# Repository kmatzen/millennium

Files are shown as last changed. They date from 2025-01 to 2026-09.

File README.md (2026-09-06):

# Millennium Project

The **Millennium Project** breathes new life into the Nortel Millennium public telephone by replacing much of its original electronics with modern hardware and software. The project integrates a Raspberry Pi Zero 2 W, two Arduinos, and a VoIP software stack while retaining all the original hardware, including the display, keypad, coin acceptor, magstripe reader, handset, and ringer speaker.

## Table of Contents

1. [Overview](#overview)
2. [Architecture](#architecture)
3. [Features](#features)
4. [Directory Structure](#directory-structure)
5. [Setup](#setup)
6. [Configuration](#configuration)
7. [Development](#development)
8. [Resources](#resources)
9. [License](#license)

---

## Overview

This project reimagines the functionality of the Nortel Millennium telephone by combining modern hardware and software while preserving its iconic hardware features:
- **Raspberry Pi Zero 2 W**: Manages the system, runs the VoIP stack, and interfaces with the original hardware.
- **Arduinos**: Control the keypad, display, and other peripherals.
- **Custom PCB**: Consolidates the connections between components.
- **Host Software**: Includes a daemon, plugin system, web dashboard, and ALSA audio configuration.
- **Preserved Hardware**: The original display, keypad, coin acceptor, magstripe reader, handset, and ringer speaker are retained and functional.

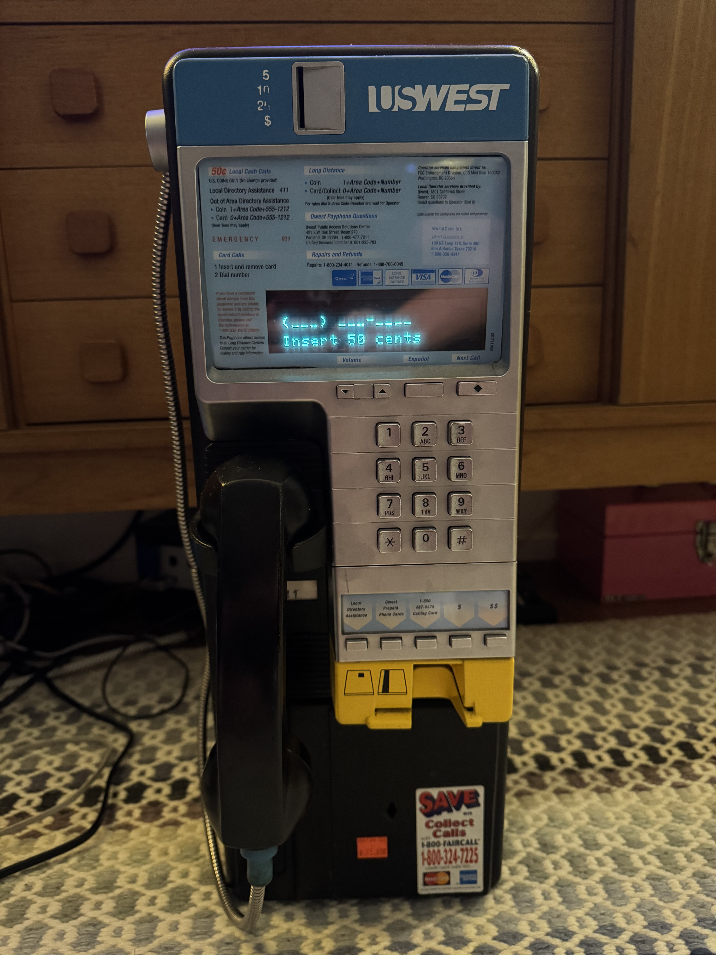
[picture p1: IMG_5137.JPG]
photo of modified phone


---

## Architecture

```
┌────────────────────────── Raspberry Pi Zero 2 W ───────────────────────────┐
│                                                                            │
│  ┌──────────────┐     ┌──────────────┐      ┌──────────────────────────┐   │
│  │ Daemon       │────▶│ PJSIP (VoIP) │      │ Web Dashboard :8081      │   │
│  │              │     └──────────────┘      │                          │   │
│  │ Plugins:     │                           │ - phone state            │   │
│  │ - Phone      │     ┌──────────────┐      │ - plugin switching       │   │
│  │ - Fortune    │     │ ALSA Audio   │      │ - OTA updates            │   │
│  │ - Jukebox    │     └──────────────┘      │ - health / metrics       │   │
│  │ - +4 games   │                           └──────────────────────────┘   │
│  └──────┬───────┘                                                          │
│         │ USB serial (9600 baud)                                           │
└─────────┬──────────────────────────────────────────────────────────────────┘
          │
┌─────────┴───────────────── Custom PCB (phonev6) ───────────────────────────┐
│                                                                            │
│  ┌──────────────────────┐ I2C      ┌────────────────────────┐              │
│  │ Display Arduino      │◀─────────│ Keypad Arduino         │              │
│  │ (millennium_beta)    │          │ (millennium_alpha)     │              │
│  │                      │          │                        │              │
│  │ - VFD display        │          │ - 4x7 keypad           │              │
│  │   (parallel 8-bit)   │          │ - magstripe reader     │              │
│  │ - coin validator     │          │ - hook switch          │              │
│  │   (SoftSerial)       │          └────────────────────────┘              │
│  └──────────────────────┘                                                  │
└────────────────────────────────────────────────────────────────────────────┘
```

**Data flow**: Keypad/hook/card events originate on the Keypad Arduino, are sent via I2C to the Display Arduino, which forwards them to the Raspberry Pi over USB serial. The daemon processes events through an event processor, dispatches them to the active plugin, and sends display updates back down the same path. VoIP calls are handled by PJSIP (PJSUA C API) with audio routed through ALSA (dmix + route plugins for mono channel splitting).

---

## Features

- **Pay phone operation**: Insert coins, dial numbers, make VoIP calls — authentic payphone experience
- **Plugin system**: Swap modes live — Classic Phone, Fortune Teller, Jukebox, plus games (Number Guess, Simon, Dial-A-Joke, Trivia). Write your own against the [plugin SDK](host/PLUGIN_AUTHORING.md); new plugins appear in the dashboard automatically
- **Emergency calls**: Dial 911, 311, or 0 without coins (configurable free numbers)
- **Dedicated credential-card support**: Swipe a random-token card for free calling or administration; payment cards are prohibited
- **Web dashboard**: Real-time phone state, plugin switching, health monitoring via WebSocket
- **Signed OTA updates**: Check, install, attest, and roll back immutable host and firmware releases. The unattended production design is documented in [host/docs/UNATTENDED_APPLIANCE.md](host/docs/UNATTENDED_APPLIANCE.md).
- **Audio tones**: DTMF, dial tone, busy tone, coin tone, ringback via ALSA
- **Idle timeout**: Automatically resets phone state after configurable inactivity period
- **State persistence**: Saves and restores coin balance and plugin state across restarts
- **Health monitoring**: Tracks serial connection, SIP registration, and daemon activity
- **Metrics collection**: Counters for calls, coins, keypresses, card swipes
- **Version tracking**: Build version and git hash displayed on dashboard
- **Scenario testing**: Simulator-based integration tests with simulated time
- **Full ARM appliance VM**: A Debian/QEMU lab runs the real daemon under
  systemd against a protocol-faithful virtual phone controller. See
  [tools/qemu/README.md](tools/qemu/README.md).

---

## Directory Structure

- **`Arduino/`**: Arduino sketches for the keypad and display microcontrollers, plus a Makefile for building and flashing.
- **`case/`**: 3D model files (`.blend` and `.stl`) for a custom enclosure. See [case/README.md](case/README.md) for dimensions and print settings.
- **`pcb/`**: KiCad schematic, PCB layout, BOM, and Gerber files for the custom PCB (phonev6).
- **`HARDWARE.md`**: Physical assembly reference — USB topology, cable routing, power budget, and component list.
- **`host/docs/UNATTENDED_APPLIANCE.md`**: Production design for signed full-device OTA and outbound remote maintenance.
- **`host/`**: Raspberry Pi software:
  - `daemon.c` — Main daemon loop and event routing
  - `plugins/` — Plugin implementations (classic_phone, fortune_teller, jukebox, number_guess, simon, dial_a_joke, trivia)
  - `plugin_sdk.c` — Plugin authoring facade (see [PLUGIN_AUTHORING.md](host/PLUGIN_AUTHORING.md))
  - `web_server.c` — HTTP server with dashboard and REST API
  - `audio_tones.c` — Tone generation (DTMF, dial tone, etc.)
  - `updater.c` — OTA update checker and applier
  - `simulator.c` — Test runner with scenario file support and simulated time
  - `tests/` — Unit tests and scenario test files
  - `systemd/` — Service file for the daemon
  - `daemon.conf.example` — Example configuration file
  - `asoundrc.example` — ALSA audio configuration for mono channel splitting
- **`tools/qemu/`**: Reproducible ARM VM, cloud-init provisioning, virtual MCU,
  lifecycle commands, and end-to-end smoke test.

---

## Setup

### 1. Arduino Firmware
Navigate to the `Arduino/` directory and follow the instructions in its [README](Arduino/README.md) to build and flash firmware to the microcontrollers.

### 2. PCB
The PCB files are in the `pcb/` directory. Upload the Gerber files to a PCB fabricator like JLCPCB for manufacturing. See the [pcb README](pcb/README.md) for details.

### 3. Host Software
Follow the [setup guide](host/SETUP.md) for full step-by-step instructions, or use the quick install:

```bash
cd host
make daemon        # Build the daemon
sudo make install  # Install to /usr/local/bin and set up systemd
```

See the [host README](host/README.md) for dependency installation (PJSIP, ALSA) and audio configuration.

### 4. Configuration
Copy and edit the configuration file:

```bash
sudo cp host/daemon.conf.example /etc/millennium/daemon.conf
sudo nano /etc/millennium/daemon.conf
```

See [Configuration](#configuration) below for all available options.

---

## Configuration

The daemon reads configuration from `/etc/millennium/daemon.conf`. See `host/daemon.conf.example` for a complete annotated example. Key settings:

| Key | Default | Description |
|-----|---|---|
| `hardware.display_device` | `/dev/serial/by-id/usb-Arduino_LLC_Millennium_Beta-if00` | Serial device for display Arduino |
| `hardware.baud_rate` | `9600` | Serial baud rate |
| `call.cost_cents` | `50` | Cost per call in cents |
| `call.timeout_seconds` | `300` | Maximum call duration |
| `call.free_numbers` | `911,311,0` | Comma-separated numbers that bypass coin requirement |
| `call.idle_timeout_seconds` | `60` | Seconds of inactivity before phone resets |
| `card.enabled` | `true` | Enable magstripe card support |
| `card.free_tokens` | *(empty)* | Random 16-digit dedicated-card tokens for free calling |
| `card.admin_tokens` | *(empty)* | Random 16-digit dedicated-card tokens for administration |
| `web_server.enabled` | `true` | Enable the web dashboard |
| `web_server.port` | `80` | Web dashboard port |
| `system.source_dir` | `/home/millennium/millennium` | Development-only source directory |

---

## Development

### Building and testing

```bash
cd host
make test          # Build simulator + unit tests, run both
make daemon        # Build the full daemon (requires PJSIP/libpjproject on the Pi)
make clean         # Remove all build artifacts
```

### Running tests locally

Tests run on any platform (macOS, Linux) without PJSIP or ALSA — the simulator stubs out hardware dependencies:

```bash
cd host
make test
```

This runs:
- **Unit tests**: Config, daemon state, plugins, emergency numbers, card config, updater
- **Scenario tests**: Full integration tests (basic call, timeout, emergency, card swipe, hook lifecycle, state persistence, display scrolling, idle timeout)

### Adding a plugin

See [host/PLUGIN_AUTHORING.md](host/PLUGIN_AUTHORING.md) for the full guide. In short:

1. Create `host/plugins/your_plugin.c` (write it against [plugin_sdk.h](host/plugin_sdk.h))
2. Implement handler functions for the events you care about (coin, keypad, hook, call state, card, tick)
3. Register with `plugins_register()` in a `register_your_plugin()` function
4. Call the registration function from `plugins_init()` in `plugins.c`
5. Add the `.o` file to the Makefile build targets (daemon, `SIM_OBJS`, `UNIT_TEST_OBJS`)
6. Run `make test` — your plugin then appears in the dashboard automatically

### Coding style

- C89 across the whole codebase, compiled with `-std=gnu89` (the C89 language plus the GNU extensions the ALSA/PJSIP headers require, e.g. `inline`; strict `-std=c89` can't parse those headers)
- `-Wall -Wextra -Wdeclaration-after-statement -Werror` on every target — warnings are errors, and `-Wdeclaration-after-statement` keeps the source free of C99-style mixed declarations
- No unnecessary comments — code should be self-documenting

---

## Resources

This project draws on several resources for understanding and interfacing with the Nortel Millennium telephone's hardware:

1. **General Millennium Payphone Documentation**
   The [Millennium Payphone Wiki](https://wiki.muc.ccc.de/millennium:start) provides extensive documentation on the phone's hardware and protocols.
   - **Coin Validator Protocol**: Used the documented higher-level protocol to interface with the coin validator.
   - **EEPROM Data**: Referenced for configuring the coin validator to accept Canadian currency.

2. **Display Documentation**
   A detailed discussion on the Noritake CU20026SCPB-T23A VFD display can be found in this [HardForum thread](https://hardforum.com/threads/noritake-cu20026scpb-t23a-20-x-2-vfd-modulel.1132806/). This was essential for understanding and controlling the display.

3. **Device Pinouts**
   The [New Fire Millennium Payphone Page](http://www.newfire.org/payphones/millennium/) includes pinout diagrams for various components, which were critical when developing the Arduino sketches.

4. **Millennium Phone Source**
   The Millennium phone used in this project was sourced from [Ballard Reuse](https://ballardreuse.com/) in Seattle, a store specializing in salvaged and reusable materials.

---

## License

This project is licensed under the MIT License. See [LICENSE](LICENSE) for details.

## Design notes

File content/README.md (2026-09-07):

# Story content

Stories are data, not daemon code. Each story directory contains `story.json`
and an optional `media/` directory. A scene gives the two display lines, an
optional WAV filename, and event-to-scene transitions. Supported events cover
keypad input, coins, credentials, handset changes, timeouts, resumed sessions,
and a default recovery path.

Run these before review or deployment:

```sh
python3 content/storytool.py validate content/stories/last_line/story.json
python3 content/storytool.py explore content/stories/last_line/story.json
python3 content/storytool.py preview content/stories/last_line/story.json
python3 content/storytool.py compile content/stories/last_line/story.json \
  --output content/stories/last_line/story.mst
python3 content/storytool.py package content/stories/last_line/story.json \
  --output build/content --private-key /secure/content-signing.pem --key-id content-2026
python3 content/catalogtool.py build build/content/*.manifest.json \
  --base-url https://updates.kmatzen.com/experiences/ \
  --channel stable --sequence 1 --key-id catalog-2026 \
  --private-key /secure/catalog-signing.pem --output build/content/catalog.json
python3 content/catalogtool.py validate build/content/catalog.json
python3 content/catalogtool.py select build/content/catalog.json \
  --device-id phone-001
python3 content/publish_catalog.py build/content \
  /home/kmatzen/selfhosted/millennium-updates/www/experiences \
  --catalog-key catalog-2026:/secure/catalog-public.pem \
  --package-key content-2026:/secure/content-public.pem
```

Validation rejects unreachable scenes, unmarked dead ends, closed loops with no
ending, missing or unused media, duplicate inputs, invalid transitions, and
copy that exceeds the physical 20-character VFD. It also rejects undeclared
runtime capabilities, invalid compatibility ranges, ratings/locales, state
migrations, and package quotas. `preview` lets an editor play each choice locally;
`explore` prints every acyclic path and ending for review. Packaging produces a
canonical schema-2 manifest, per-file inventory and digests, compressed size,
monotonic sequence, compatibility/capability/rating/quota policy, reproducible
archive, and optional Ed25519 signature. Content versions are independent of
the daemon version; sequence provides the anti-rollback ordering.

On the phone, `install_content.py install` requires that signature and a
matching trusted key ID, revalidates the author and runtime forms, installs an
immutable release, and atomically moves `current` while retaining `previous`.
It accepts legacy schema-1 releases during migration, but schema-2 releases
also enforce archive and expanded-size limits, exact file inventory, runtime
and daemon compatibility, allowlisted capabilities, and persistent monotonic
sequence state. A rollback switches to the retained known-good release without
lowering that anti-rollback state.

`catalogtool.py` builds canonical signed channel catalogs from schema-2 package
manifests. Catalog entries use immutable HTTPS manifest/signature URLs and bind
the manifest SHA-256. Deterministic per-device rollout supports percentages,
device groups, global holds, signed-digest withdrawal, package-ID denial, and
installed-sequence filtering. The website remains an untrusted transport;
catalog and package signatures establish authority.

`publish_catalog.py` verifies both signature layers and every bound digest
again at the server boundary. It refuses an existing release directory or a
non-increasing channel sequence, publishes packages beneath
`releases/<id>/<sequence>-<version>/`, then atomically commits the mutable
channel catalog last. The publisher accepts public verification keys only;
offline private keys never belong on the update server.

On `anima`, `updates.kmatzen.com` is served by the unprivileged
`millennium-updates` container. Its read-only `/srv/updates` mount is backed by
the operator-writable host directory
`/home/kmatzen/selfhosted/millennium-updates/www`; run the publisher against
that host path. Copy only the already-signed package set, this publisher and
its Python verifier modules, and the public keys to a private staging
directory. No container restart is required because nginx reads the bind mount
for each request. Verify the public catalog URL and every catalog-bound object
after publication before advancing rollout.

The full-device OTA bundle carries the matching content verifier and compiler
under `/opt/millennium/current/content`, so a story compiler-format change is
promoted with the daemon that reads it. Production content activation should
invoke that release-owned verifier rather than an older fixed-path copy.
`install_content.py rollback` swaps those links without changing the host
daemon or MCU firmware. Configure `story.path` to
`/var/lib/millennium/content/current/story.mst`.

`make -C host install` installs the verifier as
`/usr/local/libexec/millennium-content` and provisions *The House at the End of the Line* as an
immutable offline bootstrap release. It never replaces an existing `current`
content link. New content can therefore be installed and rolled back without
replacing the daemon, while a factory-new or disconnected phone still has a
complete local experience.

Authors should keep the first prompt actionable, acknowledge every input with
audio or display feedback, provide timeout and hang-up recovery, make the main
ending discoverable without secrets, and test every branch with a first-time
caller. Never place personal data in story state or analytics.

The runtime supports conditional transitions over persistent integer variables,
`set` and `increment` actions, the special `$hour` and `$weekday` variables,
outgoing calls and call-state transitions, per-scene `timeout_seconds`, and
events for every physical input. A scene may also schedule one persistent local
callback after a bounded wall-clock delay:

```json
"callback": {"after_seconds": 86400, "target": "operator_callback"}
```

The due timestamp survives daemon restarts. Story Mode delivers the callback
only while the handset is down, records it as consumed before entering the
target, and can route a timeout into an ordinary message-waiting scene. This is
a narrative callback, not permission to call a real telephone number; external
calls still use the separately configured `call` field.

Operators may set `story.callbacks_enabled=false` as an immediate kill switch.
`story.callback_quiet_start` and `story.callback_quiet_end` are local hours
(defaults `22` and `8`); a due callback remains pending until the handset is
down, callbacks are enabled, and the current hour is outside that interval.

Accessibility metadata configures output
volume, a global repeat key, minimum response time, high-contrast copy, and a
spoken-instruction mode that requires audio for every actionable scene.
Audio values are safe `.wav` filenames stored in the story's `media/`
directory; the runtime resolves them through the atomically selected content
release, so media changes and rollbacks cannot drift away from story data.

Editorial and release criteria live in [STORY_BIBLE.md](STORY_BIBLE.md), the
planned experience sequence in [ROADMAP.md](ROADMAP.md), and first-time-caller
observation records in [PLAYTEST.md](PLAYTEST.md).

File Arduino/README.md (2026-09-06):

# Arduino Firmware

Host and MCU communication uses the CRC-framed, negotiated protocol documented
in [`../docs/MCU_PROTOCOL.md`](../docs/MCU_PROTOCOL.md). Both sketches report
their role, release version, source build ID, protocol version, self-test result,
and previous AVR reset cause for OTA attestation and monitoring.

Two Arduino Micro boards (ATmega32U4) run the keypad/peripheral I/O:

| Board | FQBN | Sketch | Role |
|---|---|---|---|
| Millennium Alpha  | `millennium:avr:millennium_alpha`  | `sketches/keypad`  | 4x7 keypad, magstripe reader, hook switch |
| Millennium Beta | `millennium:avr:millennium_beta` | `sketches/display` | VFD display, coin validator, I2C→USB bridge |

See [PINOUT.md](PINOUT.md) for complete pin assignments, I2C protocol, and serial command reference.

## Pre-built Firmware

Pre-built hex files are checked in under `build/`:

```
build/keypad/keypad.ino.hex    # Flash to Millennium Alpha
build/display/display.ino.hex  # Flash to Millennium Beta
```

These can be flashed directly without compiling:

```bash
arduino-cli upload -p /dev/serial/by-id/usb-Arduino_LLC_Millennium_Alpha-if00 \
    --fqbn millennium:avr:millennium_alpha --input-dir ./build/keypad

arduino-cli upload -p /dev/serial/by-id/usb-Arduino_LLC_Millennium_Beta-if00 \
    --fqbn millennium:avr:millennium_beta --input-dir ./build/display
```

## Building from Source

### Prerequisites

- [arduino-cli](https://arduino.github.io/arduino-cli) in your `PATH`
  (or set `ARDUINO_CLI=/path/to/arduino-cli`)
- Arduino AVR core: `arduino-cli core install arduino:avr`

That is the whole setup. The Millennium board definitions live in this repo
under `hardware/millennium/avr/` and the Makefile points `arduino-cli` at them,
so no machine-specific configuration is needed (#256).

### Build and Flash

```bash
make build              # Compile both sketches → build/
make install            # Flash both to connected Arduinos
make install_keypad     # Flash keypad only
make install_display    # Flash display only
make clean              # Remove build artifacts
```

**Recommended: build on macOS, deploy to Pi via GPIO reset**

The Pi has direct GPIO reset connections to both Arduinos:
- GPIO17/GEN0 (pin 11) → Arduino Alpha RST
- GPIO27/GEN2 (pin 13) → Arduino Beta RST

The deploy scripts assert reset via GPIO (open-drain: drive low, release to input), wait for
the sketch's port to disappear, then wait for the **bootloader's** port and flash that with
`avrdude`. Those are two different paths: a reset board runs stock Caterina, which enumerates
as `usb-Arduino_LLC_Arduino_Micro-if00`, not under the sketch's custom name. Pointing avrdude
at the sketch path instead reaches the running firmware and fails with
`butterfly_recv(): programmer is not responding` (#254). An external reset holds the
bootloader open for several seconds, so there is no tight window to hit. Requires
`raspi-gpio` and `avrdude` on the Pi.

```bash
./Arduino/deploy_display.sh [user@host]   # flash Beta (display)
./Arduino/deploy_keypad.sh  [user@host]   # flash Alpha (keypad)
# Default host: millennium@millennium-phone.local

# Or via make:
make deploy_display
make deploy_keypad
make deploy          # flash both (keypad first, then display)
```

If hex not pushed: `VIA_SCP=1`.

If `arduino-cli` is not in your `PATH`:

```bash
make build ARDUINO_CLI=/home/millennium/bin/arduino-cli
```

### Verifying a Build

The build is reproducible — recompiling from the same source with the same
arduino-cli and AVR core version produces identical hex files.

## Custom Board Definitions

The two boards are Arduino Micro clones with custom USB product names and
PIDs so the Pi can distinguish them via `/dev/serial/by-id/`. Building with
stock `arduino:avr:micro` is **not** a substitute — it would produce two
indistinguishable "Arduino Micro" ports, and both `pi_flash.sh` and the
daemon's `hardware.display_device` key off those names.

The definitions are vendored in this repo (#256):

```
hardware/millennium/avr/boards.txt     # millennium_alpha / millennium_beta
hardware/millennium/avr/platform.txt   # references arduino:avr
```

They reference the installed AVR core for toolchain, core and variant rather
than duplicating it, so nothing here pins a core version. Verified byte-identical
output across AVR core 1.8.6 and 1.8.8, and across a Pi and a Mac.

They previously existed only as hand-appended entries in the AVR core's own
`boards.txt` on one SD card, where any `arduino-cli core upgrade` would have
silently erased them.

Key differences from stock Arduino Micro:

| Property | Stock Micro | Millennium Alpha | Millennium Beta |
|---|---|---|---|
| USB PID (app) | 0x0037 | 0x0045 | 0x0046 |
| USB PID (boot) | 0x8037 | 0x8045 | 0x8046 |
| Product name | Arduino Micro  | Millennium Alpha | Millennium Beta |

The full entries are in [`hardware/millennium/avr/boards.txt`](hardware/millennium/avr/boards.txt).

### Bootloaders

The boards run **stock** Micro Caterina bootloaders, flashed at the factory. The
custom VID/PID only takes effect once the sketch is running; during the
bootloader window both boards look like a plain Arduino Micro. That is why
`pi_flash.sh` flashes the `usb-Arduino_LLC_Arduino_Micro-if00` path, and why it
resets only one board at a time — two boards in the bootloader at once would
contend for that single path with no way to tell them apart (#254).

The vendored `boards.txt` deliberately omits the `bootloader.*` keys the old
hand-edited entries carried. They referenced
`Caterina-Micro-Millennium-Alpha.hex` / `-Beta.hex`, which were never built, and
burning a bootloader is not part of any workflow here.

To build custom bootloaders (requires LUFA library and `avr-gcc`):

```bash
cd ~/.arduino15/packages/arduino/hardware/avr/1.8.6/bootloaders/caterina
make VID=0x2341 PID=0x8045 TARGET=Caterina-Micro-Millennium-Alpha
make VID=0x2341 PID=0x8046 TARGET=Caterina-Micro-Millennium-Beta
```

This requires the [LUFA 111009](https://github.com/abcminiuser/lufa) library
installed at the path referenced in the Makefile
(`../../../../../../LUFA/LUFA-111009` relative to the bootloader directory).

## Directory Structure

```
Arduino/
├── Makefile                    # Build and flash targets
├── hardware/millennium/avr/    # vendored board definitions (#256)
├── PINOUT.md                   # Pin assignments and protocol reference
├── build/
│   ├── keypad/keypad.ino.hex   # Pre-built keypad firmware
│   └── display/display.ino.hex # Pre-built display firmware
├── sketches/
│   ├── keypad/keypad.ino       # Keypad Arduino source
│   └── display/display.ino     # Display Arduino source
└── libraries/
    ├── Keypad/                 # Keypad matrix library
    └── MagStripe/              # Magnetic stripe reader library
```

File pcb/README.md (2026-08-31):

# PCB Design

This directory contains the PCB design files created with [KiCad](https://www.kicad.org/).

## Design History

- **phonev2** (removed): Dual LM358 op-amps, raw power connector, pin headers for audio.
- **phonev4** (earlier fabrication): Single LM386 power amplifier for ringer only,
  XL6009 boost converter, RJ9 and 3.5mm jacks. Had two design flaws: speaker
  output coupling (#42) and unamplified handset earpiece (#44).
- **phonev5** (previous schematic): TDA2822M dual-channel amplifier replacing the
  LM386, fixing both audio design flaws. Adds reverse polarity protection, ESD
  protection, power LED, fuse, test points, and improved I2C pull-ups.
- **phonev6 (current — fabricated and installed)**: through-hole → SMD migration of
  the phonev5 design, plus a `make verify` guardrail suite (netlist sync, footprint
  parity, pinout and footprint checks, ERC, DRC) that must be all-green before
  ordering. This is the revision currently installed in the phone.

## Audio Circuit (TDA2822M)

The TDA2822M is a dual low-voltage audio power amplifier in a DIP-8 package
(same footprint as the LM386 it replaces). It provides two independent amplified
channels, solving both the speaker coupling and quiet handset issues.

### Signal Paths

```
USB audio card (stereo 3.5mm)
  ├─ Left channel → J7 tip → C_inA → TDA2822 IN_A (pin 3)
  │                                    → OUT_A (pin 1) → C_outA → speaker_front+ → ringer
  │
  └─ Right channel → J7 ring → C_inB → TDA2822 IN_B (pin 4)
                                        → OUT_B (pin 5) → C_outB → speaker_receiver+ → J4 RJ9 → handset
```

Each channel has its own input coupling capacitor (100nF) and output coupling
capacitor (100µF). The channels are electrically isolated inside the TDA2822M,
eliminating the crosstalk present in the v4 LM386 design.

### TDA2822M Pin Connections

| Pin | Function | Net |
|-----|---|---|
| 1 | OUT_A | → C_outA → `speaker_front+` |
| 2 | GND | `gnd` |
| 3 | IN_A | `speaker_front_pre+` via C_inA |
| 4 | IN_B | `speaker_receiver_pre+` via C_inB |
| 5 | OUT_B | → C_outB → `speaker_receiver+` |
| 6 | V+ | `5V_MAIN` |
| 7 | RIPPLE | → C_ripple (4.7µF) to GND |
| 8 | NC | Not connected |

### Component Values

| Ref | Value | Purpose |
|---|---|---|
| C_inA | 100nF | Input coupling, channel A (ringer) |
| C_inB | 100nF | Input coupling, channel B (handset)  |
| C_outA | 100µF 16V | Output coupling, channel A (ringer)  |
| C_outB | 100µF 16V | Output coupling, channel B (handset) |
| C_vcc | 100µF 16V | Vcc bypass |
| C_ripple  | 4.7µF | Ripple rejection (pin 7) |
| C_dec | 100nF | Vcc decoupling |

## Bill of Materials

| Ref | Value / Part | Qty | Footprint | Notes |
|---|---|-----|---|---|
| A1 | Arduino Micro (keypad) | 1 | Socket headers | Millennium Alpha board |
| A2 | Arduino Micro (display) | 1 | Socket headers | Millennium Beta board |
| A3 | Raspberry Pi Zero WH | 1 | ADA3708 footprint | Adafruit ADA3708 |
| U1 | XL6009 boost converter | 1 | Module | 12V output (from 5V input), coin validator supply |
| U2 | TDA2822M | 1 | DIP-8 | Dual audio amplifier |
| R1 | 4.7kΩ resistor | 1 | Axial | I2C pull-up (SDA) |
| R2 | 4.7kΩ resistor | 1 | Axial | I2C pull-up (SCL) |
| R3 | 1kΩ resistor | 1 | Axial | Power LED current limit |
| C_inA | 100nF ceramic | 1 | Axial L3.8mm THT | TDA2822 ch A input coupling |
| C_inB | 100nF ceramic | 1 | Axial L3.8mm THT | TDA2822 ch B input coupling |
| C_outA | 100µF 16V electrolytic | 1 | Radial D8mm P3.8mm | TDA2822 ch A output coupling |
| C_outB | 100µF 16V electrolytic | 1 | Radial D8mm P3.8mm | TDA2822 ch B output coupling |
| C_vcc | 100µF 16V electrolytic | 1 | Radial D8mm P3.8mm | TDA2822 Vcc bypass |
| C_ripple | 4.7µF electrolytic | 1 | Radial D5mm P2.0mm | TDA2822 ripple rejection |
| C_dec | 100nF ceramic | 1 | Axial L3.8mm THT | TDA2822 Vcc decoupling |
| C-* | 100nF ceramic | 5 | Axial L3.8mm THT | Decoupling (see below) |
| D1–D3 | P6KE6.8CA | 3 | DO-15 (THT axial) | TVS clamp signal lines to GND (600W bidirectional) |
| Q1 | AO3401A P-ch MOSFET | 1 | SOT-23 (SMD, JLCPCB basic C15127) | Reverse polarity protection |
| F1 | 1A PTC fuse | 1 | Radial D10mm THT | Resettable overcurrent fuse |
| D4 | Red LED (0603, C2286 basic) | 1 | LED_0603 SMD | Power indicator |
| J1 | Coin validator | 1 | 2x5 pin header | 10-pin IDC |
| J2 | Keypad | 1 | 2x10 pin header | 20-pin IDC |
| J3 | VFD display | 1 | 2x13 pin header | 26-pin IDC |
| J4 | Handset (RJ9) | 1 | RJ9 jack | 4P4C handset connector |
| J5 | Microphone | 1 | 3.5mm stereo jack | Handset mic input |
| J6 | Card reader | 1 | 2x7 pin header | 14-pin for magstripe reader |
| J7 | Speaker | 1 | 3.5mm stereo jack | Stereo audio from USB card |
| TP1–5 | Test points | 5 | Through-hole loop D2.5mm | 5V_MAIN, Pi 3.3V, GND, SDA, SCL (see Test Points section)|

### Decoupling Capacitors (C-*)

| Ref | Location |
|---|---|
| C-arduino1 | Near keypad Arduino |
| C-arduino-display1 | Near display Arduino |
| C-raspi1 | Near Raspberry Pi |
| C-coin1 | Near coin connector |
| C-card1 | Near card reader |

## Protection Circuits

### Reverse Polarity Protection (Q1)

A P-channel MOSFET (AO3401A, SOT-23 SMD; JLCPCB basic C15127) on the incoming 5V rail protects
against accidental reverse-polarity connections. Q1 is placed on the power
input *before* distribution and *before* feeding U1 IN+. The MOSFET's body
diode conducts during normal operation with near-zero voltage drop, and blocks
current when polarity is reversed.

### ESD / TVS Protection (D1, D2, D3)

Three P6KE6.8CA TVS diodes (600W bidirectional, THT DO-15) protect signal
lines from ESD and transients. Each clamps between the protected signal and
GND—one pin to signal, one to GND. D1 protects J4 (handset); D2 protects
speaker_front+ (ringer output from TDA2822); D3 protects the third signal
line. These protect against back-EMF and ESD on external connectors.

### Overcurrent Protection (F1)

A 1A resettable PTC fuse (F1) is placed on the incoming 5V rail, in series
with Q1, before power distribution and before U1. It protects the entire board
(including the boost converter input) from downstream shorts. The fuse
self-resets when the fault is cleared.

### Power Indicator (D4, R3)

A red LED on the 5V_MAIN rail provides visual confirmation that the board is
powered, useful when debugging inside the payphone enclosure.

## Connector Pinouts

### J1 — Coin Validator (2x5)

The coin validator is powered from the 12V_COIN rail (U1 output). The PCB
routes SoftwareSerial (600 baud) from the display Arduino pins 14 (RX) and 23
(TX), plus a reset line from pin 15. See the coin validator documentation for
the serial protocol.

### J2 — Keypad (2x10)

Routes to the keypad Arduino's row pins (6–9) and column pins (10–13, 18–20),
plus the hook switch pins (4, 5, 21). See `Arduino/PINOUT.md` for the complete
mapping.

### J3 — VFD Display (2x13)

8-bit parallel data bus (D0–D7) plus control signals (WR, AD, RD, CS, TEST,
RESET) routed from the display Arduino. See `Arduino/PINOUT.md` for the pin-
to-VFD-pin mapping with wire colors.

### J4 — Handset (RJ9)

| Pin | Signal |
|-----|---|
| 1 | `mic+` |
| 2 | `speaker_receiver+` |
| 3 | `gnd` |
| 4 | `gnd` |

### J6 — Card Reader (2x7)

MagStripe reader connections routed to the keypad Arduino: CLS (pin 22),
RDT/data (pin 0), RCL/clock (pin 1).

### J7 — Speaker/Audio (3.5mm stereo)

| Contact | Signal | Destination |
|---|---|---|
| Tip | `speaker_receiver_pre+` | → TDA2822 ch B → handset |
| Ring | `speaker_front_pre+` | → TDA2822 ch A → ringer  |
| Sleeve  | `gnd` | Ground |

## I2C Bus

The two Arduinos communicate over I2C (SDA/SCL). The PCB provides 4.7kΩ pull-up
resistors (R1, R2) to 5V on both lines — the standard recommended value for
100kHz I2C.

## Power Distribution

The board is powered from an external 5V supply. Power flows as follows:

1. **Incoming 5V** enters the board and passes through:
   - Q1 (reverse polarity protection)
   - F1 (PTC fuse)
2. **5V_MAIN rail** (after Q1 and F1) distributes to:
   - Both Arduino Micro boards (5V pin)
   - Raspberry Pi Zero WH (5V via GPIO header)
   - VFD display (5V logic supply; VFD filament uses its own internal supply)
   - TDA2822M amplifier (pin 6)
   - MagStripe reader (5V via Arduino)
   - U1 IN+ (boost converter input)

3. **12V_COIN rail**: U1 (XL6009) boosts 5V → 12V. XL6009 pins: IN+ = 5V_MAIN,
   IN- = GND, OUT- = GND, OUT+ = 12V_COIN. The 12V_COIN rail powers the coin
   validator only (J1). Nothing else on the board uses 12V.

## Test Points

| Label | Signal | Purpose |
|---|---|---|
| TP1 | 5V_MAIN  | Main 5V power rail |
| TP2 | 3.3V | Pi's 3.3V output (if accessible) |
| TP3 | GND | Ground reference |
| TP4 | SDA | I2C data (Arduino ↔ Arduino) |
| TP5 | SCL | I2C clock |
| TP6 | 12V_COIN | Boosted 12V rail for coin validator |

**Note on USB connectivity**: Arduino ↔ Pi communication is via USB through an
external hub. There are no discrete USB serial TX/RX nets on the PCB; TP6 and
TP7 in older docs referred to USB serial, but that path does not exist as PCB
nets. Only the test points above (5V_MAIN, GND, 12V_COIN, I2C) are actual PCB
nets.

## Schematic Audit

Run `python3 audit_schematic.py` to check component/BOM alignment, net labels, and documentation consistency. See `AUDIT.md` for findings and action items.

## Files

| File | Description |
|---|---|
| `phonev6.kicad_pro` | KiCad project file |
| `phonev6.kicad_sch` | Schematic (updated with TDA2822M) |
| `phonev6.kicad_pcb` | PCB layout (needs re-layout for new parts) |
| `phonev6.kicad_prl` | KiCad preferences (local) |
| `phonev6.csv` | Bill of materials (updated) |
| `phone.kicad_sym` | Custom symbol library (xl6009, TDA2822M, P6KE6.8CA) |
| `footprints.pretty/` | Project footprint lib (F1: Fuse_Radial_D10.0mm_P5.00mm) |
| `fp-lib-table` | Footprint library table (includes project footprints) |
| `jlcpcb/production_files/` | Gerbers zip, BOM, CPL (JLCPCB upload) |
| `audit_schematic.py` | Python script to audit schematic vs BOM vs README |
| `AUDIT.md` | Audit findings and action items |
| `SCHEMATIC_D2_CHANGES.md`  | TVS diode wiring (D1, D2, D3 P6KE6.8CA) and net reference |

## Manufacturing

See **[JLCPCB_WORKFLOW.md](JLCPCB_WORKFLOW.md)** for fabrication steps.

Quick summary:
1. Run `./pcb/scripts/export_jlcpcb.sh` to generate `jlcpcb/production_files/GERBER-phonev6.zip`
2. Use KiCad's JLCPCB Fabrication Toolkit plugin for BOM/CPL
3. Upload all three from `jlcpcb/production_files/` to JLCPCB

## Schematic Changes Required in KiCad

The schematic file has been updated with the TDA2822M symbol and updated
component values. The following wiring changes need to be completed in KiCad's
schematic editor:

### Audio path rewiring

1. **J7 pin 1 (tip)**: Change net from `speaker_receiver+` to
   `speaker_receiver_pre+`. This is the pre-amplified handset signal that
   now feeds into the TDA2822 channel B input.

2. **TDA2822 IN_A (pin 3)**: Connect to `speaker_front_pre+` via input
   coupling cap C_inA.

3. **TDA2822 IN_B (pin 4)**: Connect to `speaker_receiver_pre+` via input
   coupling cap C_inB.

4. **TDA2822 OUT_A (pin 1)**: Connect via output coupling cap C_outA to
   `speaker_front+` (ringer speaker).

5. **TDA2822 OUT_B (pin 5)**: Connect via output coupling cap C_outB to
   `speaker_receiver+` (handset earpiece via J4).

6. **TDA2822 GND (pin 2)**: Connect to `gnd`.

7. **TDA2822 V+ (pin 6)**: Connect to `5V_MAIN` via C_vcc and C_dec bypass caps.

8. **TDA2822 RIPPLE (pin 7)**: Connect via C_ripple (4.7µF) to `gnd`.

### Protection circuit wiring

1. **Q1 (reverse polarity)**: Place on the incoming 5V rail *before* distribution
   and *before* U1. Source to incoming 5V, drain to 5V_MAIN bus, gate to source
   (or appropriate pull-down for PMOS). Protects the entire board including U1
   input.

2. **F1 (fuse)**: Insert in series on the incoming 5V rail, before Q1 or between
   Q1 drain and 5V_MAIN distribution. Protects the 5V supply and boost converter
   input from overcurrent.

3. **D1, D2, D3 (TVS)**: P6KE6.8CA bidirectional TVS. Each: pin 1 → GND,
   pin 2 → protected signal (e.g. speaker_receiver+, speaker_front+, or
   other external signal). Protects signal lines, not power.

4. **D4 + R3**: Connect from 5V_MAIN through R3 (1kΩ) through D4 to GND.

### Test points

Add test point symbols connected to: 5V_MAIN, 3.3V, GND, SDA, SCL, 12V_COIN.
Do not add TX/RX test points for USB serial; Arduino ↔ Pi communication uses
USB through an external hub, so there are no discrete USB serial nets on the
PCB.

## Known PCB Errata

1. **Missing trace: Reset 2 (GPIO27 → Arduino Beta RST)** — The PCB is missing a
   trace connecting the Pi's GPIO27/GEN2 (pin 13) to the display Arduino's RST
   pin. Worked around with a bodge wire on the assembled board. Must be added as
   a proper trace in the next KiCad layout revision.

## Known Issues (resolved by this revision)

1. ~~**Speaker output coupling (#42)**~~ — **Fixed**: TDA2822M provides fully
   isolated dual channels. No more crosstalk between handset and ringer.

2. ~~**Handset earpiece too quiet (#44)**~~ — **Fixed**: Both channels are now
   amplified by the TDA2822M. The handset earpiece is no longer driven at
   unamplified line level.

## Remaining Considerations

The phonev6 schematic, layout, and generated BOM are the fabricated as-built
revision. Its migration is intentionally mixed technology: protection and
support parts moved to SMD while U2 remains the verified DIP-8 TDA2822M. The
layout is not pending; only the GPIO27 reset bodge in Known PCB Errata remains
for a future revision.

1. **ALSA config update**: The ALSA `softvol` max_dB setting in
   `host/asoundrc.example` may need adjustment since the TDA2822M provides
   hardware amplification. Software gain can likely be reduced.

2. **Gain tuning**: The TDA2822M's default gain may need adjustment for
   comfortable volume. If too loud, input attenuation resistors can be added.
   If too quiet, the coupling cap values can be increased.

3. **Mounting holes**: Consider adding M3 mounting holes at board corners for
   mechanical support inside the payphone enclosure.

## Circuit Improvement Ideas

Ideas for future revisions, ordered by likely impact.

### High priority

1. **Bulk capacitor on 5V input** — Add a 470–1000 µF electrolytic (16–25V) on
   the 5V rail (after Q1/F1, before distribution). Smooths supply during Pi boot
   current spikes and audio peaks.

2. **Bulk capacitor on 12V_COIN** — Add 100–220 µF (25V) near J1 (coin validator).
   Coin validators draw current spikes when the motor runs; the bulk cap reduces
   rail droop.

3. **Series resistor on coin validator reset** — If the Arduino drives the reset
   line directly to J1, add a 100–220 Ω series resistor. Limits fault current and
   reduces coupling.

### Medium priority

4. **I2C series resistors** — Add 22–33 Ω series resistors on SDA/SCL at each
   Arduino I2C port. Dampens ringing if cable lengths increase or in noisy
   environments.

5. **XL6009 thermal** — The 5V→12V boost at ~50–100 mA can get warm in a confined
   enclosure. Use adequate copper around the module; consider a small heatsink if
   airflow is limited.

6. **Undervoltage handling** — The bulk input cap (item 1) helps. If the 5V supply
   is marginal during boot, consider explicit UVLO or reset sequencing for
   critical loads.

### Lower priority

7. **ESD on audio jacks** — J5 (mic) and J7 (speaker) are externally accessible.
   Consider PRTR5V0U2X or similar TVS on their signal pins for robustness.

8. **Power LED brightness** — If D4 is too bright in a dark payphone, increase
   R3 (e.g., 2–4.7 kΩ) for dimmer indication.

9. **TDA2822M gain flexibility** — Add DNP footprints for optional input
   attenuation resistors so gain can be tuned without a respin.

### Documentation / mechanical

10. **Connector keying** — Verify J1 (coin validator) is keyed to prevent reverse
    insertion. Document pin-1 orientation clearly.

11. **Pi power path** — Document whether the Pi receives 5V only from the GPIO
    header or also via USB; affects power sequencing and fault behavior.

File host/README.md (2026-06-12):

# Host Software for Raspberry Pi Zero 2 W

This directory contains the software and configuration files needed to run the Millennium payphone daemon on a Raspberry Pi Zero 2 W.

**First-time setup?** See [SETUP.md](SETUP.md) for the full step-by-step guide.

## Overview

The host software includes:
- A daemon for managing the payphone — event processing, plugin system, display control, VoIP calling, web dashboard
- A systemd service file for running the daemon at startup
- An ALSA configuration for audio routing (mono channel splitting for handset/speaker)

## Files

- `Makefile` — Builds the daemon, simulator, and unit tests
- `DEVICE_TEST.md` — Run API tests against the live phone over the network
- `daemon.conf.example` — Example configuration file (copy to `/etc/millennium/daemon.conf`)
- `asoundrc.example` — Example ALSA configuration for the USB audio device
- `systemd/daemon.service` — Systemd service for the daemon
- `plugins/` — Plugin implementations (classic_phone, fortune_teller, jukebox, number_guess, simon, dial_a_joke, trivia)
- `PLUGIN_AUTHORING.md` / `PLUGIN_SYSTEM_SUMMARY.md` — Plugin authoring guide and system overview
- `tests/` — Unit tests and scenario test files

## Dependencies

The following must be installed on the Raspberry Pi Zero 2 W:

1. **PJSIP (pjproject)**: Built from source for VoIP/SIP support (PJSUA C API).
   - [pjproject GitHub Repository](https://github.com/pjsip/pjproject)
   - See [SETUP.md](SETUP.md) for build flags (ALSA + OpenSSL/TLS).

2. **ALSA development libraries**: For audio tone generation.
   ```bash
   sudo apt install libasound2-dev
   ```

## Audio Setup

Audio routing uses pure ALSA configuration (no PipeWire or WirePlumber needed). The USB audio device is a C-Media USB sound card with stereo output. The ALSA config splits this into mono channels so one channel drives the handset earpiece and the other drives the ringer/speaker.

1. Copy the ALSA configuration (or run `sudo make install`, which includes this):
   ```bash
   sudo cp host/asoundrc.example /etc/asound.conf
   ```

2. Verify the USB audio device is card 1:
   ```bash
   aplay -l
   ```
   If it's a different card number, edit `/etc/asound.conf` and change `"hw:1,0"` accordingly.

The config provides several PCM devices:
- `default` — Stereo output to the USB audio device (via dmix + softvol)
- `out_left_solo` — Mono output to left channel only (handset earpiece)
- `out_right_solo` — Mono output to right channel only (ringer speaker)
- `out_left_dup` / `out_right_dup` — Mono duplicated to both channels

## Build and Test

```bash
make daemon        # Build the full daemon (requires PJSIP/libpjproject)
make test          # Build simulator + unit tests, run both
make clean         # Remove all build artifacts
sudo make install  # Install daemon binary, ALSA config, and systemd service
```

## Command-line options

The daemon accepts a few flags (anything else is rejected with a usage message
and exit code 2):

```
Usage: millennium-daemon [options]

Options:
  -c, --config <path>   Read configuration from <path>
                        (default: /etc/millennium/daemon.conf)
  -v, --version         Print version and build info, then exit
  -h, --help            Print this help, then exit
```

`--version` prints the build's semantic version, git hash, and build time —
useful for confirming which build is actually installed after a deploy:

```bash
millennium-daemon --version
# millennium-daemon 0.3.0 (git 1f831a8, built 2026-06-11T12:00:00Z)
```

`--config` may appear anywhere on the command line and also accepts the
`--config=<path>` form. The systemd unit passes
`--config /etc/millennium/daemon.conf`.

## Systemd Setup

```bash
sudo make install
```

This installs the daemon and enables the `daemon.service` unit. SIP credentials
are read from `/etc/millennium/daemon.conf` (`sip.*`). Check status:

```bash
sudo systemctl status daemon.service
```

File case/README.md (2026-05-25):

# 3D-Printed Case

An enclosure for the custom PCB, designed in Blender and printed in PLA+.

## Dimensions

| Measurement | Value |
|---|---|
| Outer size | 109.5 × 134.0 × 38.0 mm |
| Interior (approx)  | ~103 × 128 mm |
| Wall thickness | ~3 mm |
| Depth per half | 19 mm |
| PCB size | 88.9 × 124.5 mm |
| PCB clearance (X)  | ~14.6 mm |
| PCB clearance (Y)  | ~3.5 mm |
| Triangle count | 3,544 |

## Design

The case is a two-piece clamshell that splits horizontally at the midplane:

- **Bottom half** — has rectangular cutouts on one edge for USB cables and
  connectors (2 large + 1 small), allowing cables to pass through to the
  Raspberry Pi and Arduinos while the case is closed.
- **Top half** — plain walls, no cutouts. Acts as the lid.
- **6 notch tabs** — 3 on each long side, designed for rubber bands to hold
  the halves together.

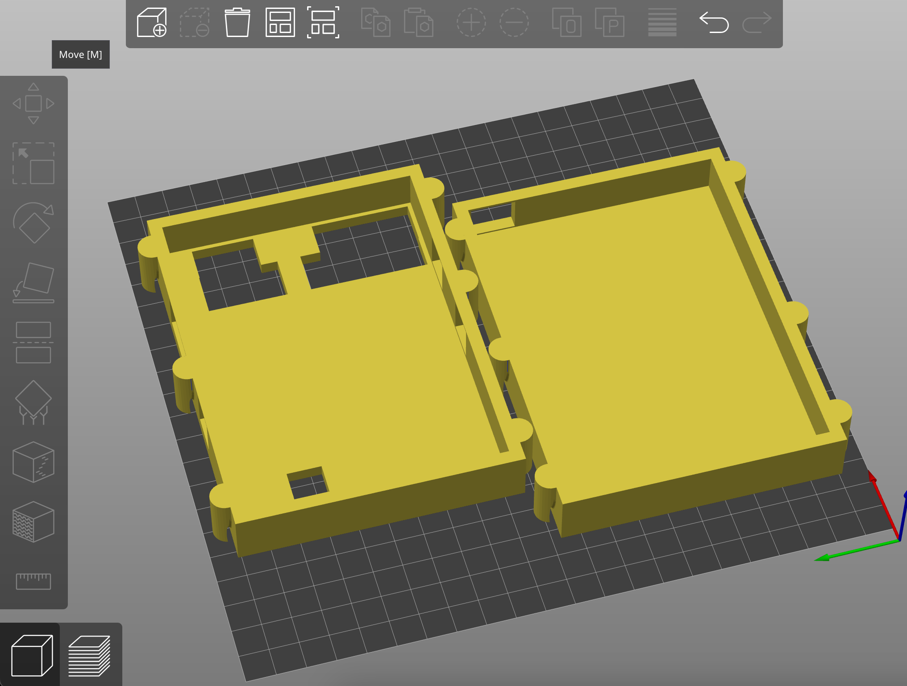
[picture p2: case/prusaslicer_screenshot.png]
PrusaSlicer view of both halves


## Files

- `case.blend` — Blender source file (editable)
- `case.stl` — Ready-to-print STL mesh (both halves as a single object)
- `prusaslicer_screenshot.png` — Preview of the sliced halves

## Printing

### Preparation

1. Load `case.stl` into your slicer (e.g., PrusaSlicer, Cura, OrcaSlicer).
2. The STL contains the full case as one piece. Use the slicer's cut tool to
   split it at Z = 0 mm (the midplane) into two separate halves.
3. Orient each half with the open face up (flat bottom on the print bed).

### Recommended Settings

| Setting | Value |
|---|---|
| Material | PLA+ (or PETG for heat resistance) |
| Layer height | 0.2 mm |
| Infill | 20–30% |
| Perimeters | 3 |
| Supports | Not needed (flat bottom, no overhangs) |
| Bed adhesion | Brim recommended for the larger half |

The original was printed with PLA+ at default slicer settings. No supports
are required since both halves print with the open face up.

### Print Time

Approximately 3–4 hours per half on a standard FDM printer at 0.2 mm layer
height.

## Assembly

1. Place the PCB into the bottom half. The PCB sits on the flat interior
   floor — there are no standoffs or mounting posts.
2. Route cables through the rectangular cutouts: USB cables for the Pi and
   Arduinos, audio cables, and the handset/keypad ribbon cables.
3. Place the top half over the bottom and align the notch tabs.
4. Loop rubber bands around the 3 pairs of opposing notch tabs to clamp the
   halves together.

## Known Limitations

1. **No PCB standoffs**: The PCB rests directly on the case floor. This risks
   shorting traces on the bottom copper layer against any printing artifacts.
   Adding 4 standoff posts (matching the PCB corner positions) would lift the
   board and provide proper mechanical mounting.

2. **No screw bosses**: The halves are held together only by rubber bands.
   Adding M3 screw bosses at the corners would provide a more secure and
   permanent closure.

3. **No ventilation**: The case is fully enclosed with no airflow openings.
   The Pi Zero W runs at ~38°C in this enclosure which is fine, but a few
   small vent slots on the top half would improve airflow if the system is
   under sustained load.

4. **Tight Y clearance**: The PCB has only ~3.5 mm of clearance in the Y
   direction. Components or solder joints that protrude from the board edge
   may interfere with the case walls.

5. **No cable strain relief**: The cutouts are simple rectangular openings
   with no strain relief features. Cables can be pulled out accidentally.

6. **No labeling**: The case has no external markings for connector
   identification or orientation.

## Modification Tips

The Blender source file (`case.blend`) can be edited to address the
limitations above. Common modifications:

- **Add standoffs**: Extrude 4 cylindrical posts (2.5 mm diameter, 3 mm
  tall) from the interior floor at the PCB mounting hole positions.
- **Add screw bosses**: Replace the notch tabs with cylindrical bosses and
  matching holes for M3 × 16 mm screws.
- **Add vents**: Boolean-subtract a row of 2 mm slots from the top half.
- **Add cable guides**: Extrude small channels or clips near the cutouts to
  route and retain cables.

Export the modified model as STL from Blender (File → Export → STL) with
"Selection Only" if you've kept the case as a single object.

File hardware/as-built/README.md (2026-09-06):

# Per-device as-built records

Copy `TEMPLATE.md` once for every physical phone. Do not mark a record accepted
while any `REQUIRED` value remains. Hash the exact fabrication exports and HEX
files installed—not merely nearby source files. Store assembly photographs in
the device's adjacent `photos/` directory and list their hashes.

Power-loss testing must interrupt boot, idle, an active call, content-state
save, OTA download, MCU flash, and host activation. Brownout testing records
the supply, load, minimum voltage, duration, observed reset causes, and safe
recovery result. A narrative note without measurements is not evidence.

On an installed phone, arm each scenario immediately before the physical
action. Reboot-required cases reconcile automatically; run `reconcile`
manually after network-only or measured-load cases:

```bash
sudo millennium-physical-interruption arm --scenario idle_power_loss
# remove and restore power
sudo millennium-physical-interruption status
sudo millennium-physical-interruption reconcile  # harmless if already complete
```

Copy the resulting JSON from
`/var/lib/millennium/physical-tests/evidence/` into the private evidence
directory, add the human observation and measurements, then pass that file to
`as_built_record.py record-test`.

Generate a machine-readable starting record on the actual phone, then fill it
with observations and exact installed-artifact identities:

```bash
python3 tools/as_built_record.py capture --device-id phone-001 \
  --operator OPERATOR --output hardware/as-built/phone-001/evidence.json
python3 tools/as_built_record.py validate \
  hardware/as-built/phone-001/evidence.json
```

Fill the record through the CLI so file hashes and measurement requirements
cannot be omitted accidentally:

```bash
python3 tools/as_built_record.py set-physical evidence.json \
  --field pcb_revision --value phonev6
python3 tools/as_built_record.py add-photo evidence.json \
  --path photos/interior.jpg --description "Interior, PCB marking and wiring"
python3 tools/as_built_record.py record-installed evidence.json \
  --name host_binary --path /opt/millennium/current/host/millennium-daemon \
  --identity "sequence 9, version 0.4.0"
python3 tools/as_built_record.py record-test evidence.json \
  --name controlled_brownout --result pass --date 2026-09-02 \
  --instrument-and-load "bench supply and complete installed phone" \
  --minimum-voltage 4.72 --evidence-file evidence/brownout.txt
```

Use `record-installed` for every artifact named by `--help`, `set-physical`
for every physical field, and `record-test` for every interruption scenario.
A failed observation is recorded with `--result fail` and remains an open gate.

`validate` intentionally fails while any physical observation, measurement,
photo, installed identity, or recovery drill is absent. Candidate repository
hashes emitted by `capture` are never represented as installed artifacts.

## Final handoff gate

After the as-built record and first-time-caller playtest record are complete,
create one final record that also binds the four real Wi-Fi client tests, two
physically distinct encrypted signing-key copies, and an interactive
maintenance session performed from outside the home network:

```bash
python3 tools/handoff_acceptance.py template --device-id phone-001 \
  --as-built-record evidence.json \
  --playtest-record playtest-last-line-2.1.0.json \
  --signing-key-id release-2026-08 \
  --signing-public-key host/ota/keys/release-2026-08.pem \
  --output hardware/as-built/phone-001/handoff.json

python3 tools/handoff_acceptance.py record-wifi \
  hardware/as-built/phone-001/handoff.json --platform ios --result pass \
  --date 2026-09-02 \
  --portal-evidence-file evidence/millennium-wifi-ios.json \
  --outcome-evidence-file evidence/wifi-ios-outcome.txt

python3 tools/handoff_acceptance.py add-key-copy \
  hardware/as-built/phone-001/handoff.json --media-label "USB-A" \
  --ciphertext /Volumes/USB-A/release-2026-08.pem.aes256 \
  --verified-at 2026-09-02 --recovery-tested-at 2026-09-02 \
  --copy-evidence-file evidence/key-copy-usb-a.json \
  --recovery-evidence-file evidence/key-recovery-usb-a.json

python3 tools/handoff_acceptance.py record-external \
  hardware/as-built/phone-001/handoff.json --result pass --date 2026-09-02 \
  --network-description "cellular hotspot, not home ISP" \
  --evidence-file evidence/external-maintenance.json

python3 tools/handoff_acceptance.py record-server-backup \
  hardware/as-built/phone-001/handoff.json \
  --evidence-file server-state-backup-2026-09-02.json

python3 tools/handoff_acceptance.py validate \
  hardware/as-built/phone-001/handoff.json
```

Repeat `record-wifi` for `android`, `macos`, and `windows`, and `add-key-copy`
for a second removable device. The tool hashes each ciphertext itself, rejects
duplicate media labels, and requires every recovery drill to match the
canonical public-key identity selected for production. It also hashes and
rechecks every referenced evidence file, validates the linked as-built and
playtest records, and will not mark the phone acceptable from QEMU, a
mislabeled legacy key, or unsupported narrative assertions alone.

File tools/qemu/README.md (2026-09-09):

# Millennium QEMU appliance lab

This setup boots a complete Debian 12 ARM appliance, builds and runs the real
Millennium daemon under systemd, and connects it to separate behavioral models
of the Alpha and Beta Arduinos plus their display, keypad, card, hook, and coin
peripherals. It is intended for development,
integration tests, admin-dashboard work, release rehearsal, and failure testing.

It deliberately does **not** claim to emulate a Raspberry Pi Zero 2 W board or
execute the AVR instructions. QEMU has no ATmega32U4 machine, and the physical
Beta link uses native USB CDC. The co-simulation instead preserves the real
Alpha → I2C → Beta → USB protocol boundary and Beta → peripheral routing. The
actual firmware ELFs remain covered by the reproducible Arduino build and must
pass the hardware release gate.

QEMU's stable `virt` machine is used instead. USB enumeration, ALSA channel
routing, Wi-Fi radio/AP behavior, Arduino flashing, coin-validator electrical
timing, and the physical display still require a real-phone hardware test.

The lab has two complementary machines. The everyday cloud guest supports fast
development, OTA fault injection and peripheral co-simulation. The
`exact-image-test` boots the expanded factory image itself and exercises its
real MBR A/B layout, system slot, persistent partition, shared mounts and early
services. QEMU-only slot aliases are injected into `/run`; the tested image is
not altered. A physical Zero 2 W must still verify firmware selection,
read-only-root behavior, SD I/O, radios, USB, audio and power interruption.

## Requirements

- macOS arm64 or Linux
- QEMU with AArch64 and UEFI support (`brew install qemu` on macOS;
  `apt install qemu-system-arm qemu-efi-aarch64 qemu-utils` on Debian)
- Python 3, OpenSSH client and server, netcat, curl, tar, and socat
- about 2 GB RAM and 2 GB free disk space for the cloud lab; exact-image tests
  additionally require the expanded production image (currently about 15 GB)

Both the cloud guest and current production image use Debian arm64. The cloud
guest validates application, service, network, update, and protocol behavior;
the exact-image test additionally validates the assembled production userspace
and disk layout. Keep the real-device smoke test as a release gate.

## First boot

```sh
tools/qemu/qemu.sh start
tools/qemu/qemu.sh wait
tools/qemu/qemu.sh provision
tools/qemu/qemu.sh smoke
```

`start` downloads Debian's official generic-cloud image on first use, creates a
copy-on-write 16 GB overlay, generates a VM-only SSH key and NoCloud CIDATA
disk, starts the virtual MCU, and launches QEMU. All generated state remains
under `tools/qemu/state/` and is ignored by Git.

Cloud-init installs the native build dependencies. `provision` streams the
current working tree into the guest, compiles the daemon there, installs its
configuration and hardened systemd service, and starts it. Re-run `provision`
after source changes; rebuilding the disk is unnecessary.

## Everyday commands

```sh
tools/qemu/qemu.sh status
tools/qemu/qemu.sh ssh
tools/qemu/qemu.sh logs
tools/qemu/qemu.sh display
tools/qemu/qemu.sh hook up
tools/qemu/qemu.sh key 1
tools/qemu/qemu.sh coin 25
tools/qemu/qemu.sh card TEST-OWNER-TOKEN
tools/qemu/qemu.sh peripherals
tools/qemu/qemu.sh fault i2c down
tools/qemu/qemu.sh fault i2c up
tools/qemu/qemu.sh fault coin jam
tools/qemu/qemu.sh fault coin clear
tools/qemu/qemu.sh fault serial down
tools/qemu/qemu.sh fault serial up
tools/qemu/qemu.sh fault ack drop
tools/qemu/qemu.sh fault ack delay 250
tools/qemu/qemu.sh fault crc next
tools/qemu/qemu.sh fault validator verify-fail
tools/qemu/qemu.sh fault validator verify-clear
tools/qemu/qemu.sh reset-mcu alpha
tools/qemu/qemu.sh reset-mcu beta
tools/qemu/qemu.sh reset-mcu watchdog-alpha
tools/qemu/qemu.sh reset-mcu watchdog-beta
tools/qemu/qemu.sh restart-virtual-mcu
tools/qemu/qemu.sh network down
tools/qemu/qemu.sh network up
tools/qemu/qemu.sh pause
tools/qemu/qemu.sh resume
tools/qemu/qemu.sh power-cut
tools/qemu/qemu.sh collect-artifacts my-test-run
tools/qemu/qemu.sh ota-test
tools/qemu/qemu.sh ota-fault-test
tools/qemu/qemu.sh ota-external-origin-test
tools/qemu/qemu.sh os-ota-test
tools/qemu/qemu.sh wifi-test
tools/qemu/qemu.sh maintenance-external-tunnel-test
tools/qemu/qemu.sh experience-test
tools/qemu/qemu.sh experience-lifecycle-test
tools/qemu/qemu.sh experience-power-test
tools/qemu/qemu.sh exact-image-test
tools/qemu/qemu.sh full-test
tools/qemu/qemu.sh stop
```

When all three exact-image variables shown below are set, `full-test` includes
the exact production-image gate and records
`exact_production_image_tested: true`. With none set it runs the portable cloud
lab and records `false`; a partial exact-image configuration is rejected. The
exact-image boot remains bounded at ten minutes because external-volume I/O and
concurrent emulation can make a valid first boot exceed five minutes.

Cold disk checkpoints are available while the VM is stopped:

```sh
tools/qemu/qemu.sh checkpoint save known-good
tools/qemu/qemu.sh checkpoint list
tools/qemu/qemu.sh checkpoint load known-good
tools/qemu/qemu.sh checkpoint delete known-good
```

`power-cut` terminates QEMU without a guest shutdown specifically for recovery
testing. `reset` and checkpoint loading are recoverable but intentionally alter
the overlay selected for the next boot; do not keep irreplaceable data only in
the lab VM.

To use the loopback-only dashboard and metrics endpoints, open an SSH tunnel:

```sh
tools/qemu/qemu.sh tunnel
```

Then visit `http://127.0.0.1:8081`. Obtain its bearer token with
`tools/qemu/qemu.sh token`. Metrics are at `http://127.0.0.1:8080`.

The co-simulator writes the complete Arduino/peripheral state to
`tools/qemu/state/display.json` and logs VFD and validator traffic in
`tools/qemu/state/mcu.log`. Alpha models the 4x7 keypad, hook debounce boundary,
card reader, bounded I2C delivery, resets, and drop accounting. Beta models I2C
forwarding, USB framing, VFD writes, validator gate/reset/program state, resets,
and heartbeats. The shared link implements CRC-16/CCITT, HELLO negotiation,
critical-command ACKs, fragmented input, resynchronization, and sequences.
The status snapshot also carries a deterministic ticked trace, MCU firmware and
reset-cause identities, and every injected fault. Run
`qemu.sh peripheral-fault-test` for the live I2C, serial, validator, watchdog,
ACK, and CRC matrix.

`collect-artifacts NAME` creates `tools/qemu/state/artifacts/NAME/` with the
daemon journal, health JSON, Prometheus metrics, console/provision logs, VFD and
peripheral state, OTA status/recovery/flash evidence, deterministic fault trace,
and a SHA-256 summary explicitly
marked `physical_hardware_claimed: false`.

Provisioning also installs the production OTA worker, timers, recovery unit,
immutable release layout, a guest-local HTTPS origin, and two independent MCU
identity endpoints. The lab creates its own disposable signing and TLS keys in
`/var/lib/millennium/qemu-ota`; these keys never leave the ignored VM overlay
and are not production credentials. `ota-test` signs and commits a release
through the real worker and attests both virtual MCU roles. `ota-fault-test`
exercises loss, corruption, withdrawal, quarantine, interrupted activation,
rollback, and active-link invariants.

`ota-external-origin-test` copies a newly signed release out of the guest,
serves it from an independent HTTPS process on the QEMU host, disables the
guest-local origin, and drives the production updater through apply, outage,
and recovery. It also injects wrong TLS identity, mid-bundle cutoff,
post-activation health loss, signed rollback and withdrawal, and exercises the
systemd update-check path used after Wi-Fi transition. This catches networking
and trust-boundary defects that an in-guest origin cannot expose.

`maintenance-external-tunnel-test` starts an isolated SSH server outside the
guest, provisions the production reverse-tunnel service against it, reaches
the guest only through the forwarded port, then proves fail-closed behavior
and automatic recovery across a server outage.

`os-ota-test` runs the full signed OS state machine inside the ARM64 guest. It
covers atomic HTTPS staging and interrupted/truncated downloads, inactive-slot
write/readback, pre-reboot selection, failed candidate fallback, digest-scoped
quarantine, health commit, persistent anti-rollback state, and both selector
directions using test-only virtual block files. Raspberry Pi firmware behavior
remains a physical Zero 2 W acceptance gate.

## Exact production-image test

Provide the expanded image and a generic arm64 QEMU `virt` kernel/initramfs.
The initramfs must carry the modules needed before the image's system slot is
mounted: `fat`, `vfat`, `nls_ascii`, `nls_cp437`, `nls_iso8859_1`, and
`nf_tables` (including their dependencies). A minimal cloud initramfs often
omits these because its own root disk does not need them; the exact-image test
will reject that transport rather than silently skipping production mounts or
firewall startup.

```sh
export MILLENNIUM_QEMU_EXACT_IMAGE=/path/to/millennium-zero2w-ab-phone-001.img
export MILLENNIUM_QEMU_EXACT_KERNEL=/path/to/vmlinuz-arm64
export MILLENNIUM_QEMU_EXACT_INITRD=/path/to/initrd.img-arm64
tools/qemu/qemu.sh exact-image-test
```

The harness creates disposable copy-on-write overlays and boots both immutable
system partitions (5 and 6),
injects `/dev/vda1`, `vda2`, `vda5`, and `vda7` as the production slot names
through ephemeral udev rules, and starts the image's own systemd. It requires
the persistent/shared mount graph, both FAT boot partitions, D-Bus, resolver,
nftables and the Millennium firewall to start under their real service
accounts. It executes the selected daemon binary as the `millennium` account
and rejects systemd `203/EXEC`; daemon liveness with virtual MCUs is covered by
the full-system suite. It fails on the permission errors previously
observed on the physical image and writes `console.log` plus `result.json` under
`$MILLENNIUM_QEMU_STATE/exact-image/`.

The output explicitly records `raspberry_pi_firmware_emulated: false` and
`physical_hardware_claimed: false`. QEMU has no exact Zero 2 W machine, so this
test closes userspace/image-assembly gaps without pretending to validate the
VideoCore boot chain, BCM2710A1 peripherals, native SD/USB/Wi-Fi behavior or
brownouts.

`wifi-test` exercises the NetworkManager boundary through deterministic radio
faults, validates captive-portal behavior for the major platform probes, and
checks the setup firewall, service sandbox, atomic credential storage, rollback,
recovery gesture, timeout, and private factory handoff. RF behavior and real
client association remain physical gates.

`wifi-external-client-test` adds an outside-in transport check. A client process
outside QEMU crosses an explicit forwarded TCP boundary to the real portal in
the ARM64 guest, performs an Android captive probe, downloads acceptance
evidence, renders the setup form, preserves its session cookie, submits the
CSRF-protected form, and verifies the helper receives the intended candidate.
It does not claim RF association.

## Reset and recovery

```sh
tools/qemu/qemu.sh reset
tools/qemu/qemu.sh start
```

Reset is recoverable: the previous overlay is renamed with a timestamp instead
of deleted. The downloaded base image is retained. To change ports, state
location, or the size of a newly created overlay, set
`MILLENNIUM_QEMU_SSH_PORT`, `MILLENNIUM_QEMU_STATE`, or
`MILLENNIUM_QEMU_DISK_SIZE` (for example, `64G`). The size setting never
resizes an existing disk.

If boot fails, inspect `tools/qemu/state/console.log`. If the
daemon fails, use `qemu.sh logs` and `qemu.sh ssh systemctl status daemon`.

## Test layers

`python3 tools/qemu/test_virtual_mcu.py` runs without QEMU and checks protocol
framing. `qemu.sh smoke` checks the running guest, systemd service, virtio MCU
device, health API, metrics endpoint, input injection, and display response.
`qemu.sh lifecycle-test` verifies pause/resume and network isolation against an
already provisioned guest. `qemu.sh recovery-test` saves a named cold
checkpoint, boots it, cuts power without a guest shutdown, restores the
checkpoint, and requires a healthy daemon after reboot. The complete remaining objective ledger and exact
acceptance commands are in `OBJECTIVES.md`.

`qemu.sh full-test` reprovisions the current tree and runs every software layer
in dependency-safe order, including the production-paced offline story. It
emits a timestamped `full-test-result.json` whose
`physical_hardware_claimed` field is always false.

The QEMU lab complements rather than replaces these release gates:

1. host unit/scenario/content tests;
2. arm64 release compilation and signed OTA verification;
3. this ARM VM appliance smoke test;
4. a real phone smoke test for USB, audio, Wi-Fi, firmware, and peripherals.

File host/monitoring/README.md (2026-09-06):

# Appliance monitoring and backup

`millennium-monitor.timer` samples the loopback health, state, and metrics APIs
once per minute and writes a Prometheus node-exporter textfile. It also checks
the daemon and maintenance-tunnel units, signed-OTA status, serial disconnects,
MCU reset reports, disk space, recent kernel filesystem errors, reboot time,
update-site certificate lifetime, and backup freshness. A failed check makes
the oneshot unit fail as well as emitting its metric, so `OnFailure=` or the
system journal can be used even without Prometheus.

Install `alerts.yml` on the monitoring server and scrape the phone's node
exporter through the authenticated maintenance path. The `last_checkin` alert
must be evaluated off-device; a dead phone cannot alert about itself.

`millennium-hil-smoke.timer` runs nightly against the installed hardware. It
requires both stable MCU device paths, framed-protocol negotiation, matching
host/release versions, healthy daemon and maintenance services, and a
non-failed OTA state. Its atomic JSON result is monitored for failure and
staleness. The test is intentionally non-destructive: it does not place calls,
accept coins, or rewrite story state.

## Physical interruption evidence

`millennium-physical-interruption` creates a durable checkpoint before an
operator deliberately interrupts power or networking. It records boot ID,
active host/content links, installed sequence, firmware digests, OTA state,
service state, and the full HIL result. Only one scenario can be armed at once:

```bash
sudo millennium-physical-interruption arm --scenario idle_power_loss
# Perform exactly the printed physical action, then restore power.
sudo millennium-physical-interruption status
```

The boot service automatically reconciles reboot-required scenarios. For
network-only and measured-load scenarios, run
`sudo millennium-physical-interruption reconcile` after restoring the normal
condition. Evidence is retained under
`/var/lib/millennium/physical-tests/evidence/` and failed attempts never
overwrite one another.

The harness does not mark a physical test accepted. It records
`physical_observation_required: true`; the operator must still document the
instrument/load, minimum voltage where applicable, observed behavior, and use
`tools/as_built_record.py record-test`. An expected OTA rollback counts as
system recovery only when the prior host release is restored and, for an MCU
flash interruption, both prior firmware digests are restored.

### Isolated OTA-download interruption

Use `tools/physical_ota_download_probe.py` when the production manifest is
already current and a destructive reinstallation would add risk without
improving the network evidence. The probe downloads the unchanged production
manifest and detached signature, validates both through the installed OTA
worker and trust store, then downloads and hashes the referenced bundle. It
never calls the install or activation commands.

For a Pi with an independent Wi-Fi maintenance path, connect its Ethernet
adapter and the operator laptop to an isolated router. Run an SSH TLS byte
forward on the laptop and put `tools/rate_limited_tcp_relay.py` between that
forward and the Pi. The rate limit belongs on the Pi-facing relay—not in the
downloader—so upstream or kernel buffers cannot complete the transfer after
the cable is removed. The relay binds only to the isolated laptop address and
the probe overrides DNS in-process; neither `/etc/hosts`, firewall rules, nor
the published manifest are changed.

Arm `ota_download_interruption`, begin the paced probe, and confirm its JSON
reports `phase: bundle-download` before physically removing only the RJ45
cable. Valid interruption evidence requires all of the following:

- the direct Ethernet address becomes unreachable;
- the probe terminates with `phase: interrupted` before receiving the signed
  bundle's declared byte count;
- the independent maintenance tunnel remains active;
- reconnecting RJ45 restores the direct address without a reboot;
- a subsequent probe validates the full bundle size and SHA-256; and
- harness reconciliation passes the full HIL snapshot without changing the
  active release, content target, installed sequence, or firmware identities.

A transfer that completes from buffered bytes after link loss is diagnostic
only and must not be entered into the as-built acceptance record.

## Encrypted backup

Install `restic`, copy `backup.env.example` to
`/etc/millennium/backup.env`, create the referenced password file with mode
`0600`, initialize the remote repository, and run:

```sh
sudo systemctl start millennium-backup.service
sudo systemctl status millennium-backup.service
sudo restic -r "$RESTIC_REPOSITORY" snapshots --tag millennium-phone
```

Only after that successful first run should the timer be enabled. The backup
contains daemon configuration and credentials, signed OTA state/artifacts, the
canonical authorized-maintainer public key, the device WireGuard identity,
the SSH hardening drop-in, and Cloudflare maintenance configuration when
present. Restic encrypts all content
before it leaves the phone and applies daily, weekly, and monthly retention.
Keep the repository credential and restic password in the offline recovery
record; losing both copies makes the backup intentionally unrecoverable.

Quarterly, restore the newest snapshot into an empty temporary directory on a
different machine and record the snapshot ID, date, and verification result.
An untested repository is not considered a backup.

### Pull-based backup host

For a phone reachable only through its reverse maintenance tunnel, install
`millennium_backup_pull.sh` on the backup host. The phone's authorized key must
be restricted to `millennium-backup-export`. The pull script can request only
`backup` and `ack`: it streams the fixed archive into Restic, applies retention,
and acknowledges the phone only after both operations succeed. That acknowledgement
updates `/var/lib/millennium/backup/last-success`, which is the freshness stamp
consumed by `millennium-monitor`.

Install `millennium_metrics_pull.sh` and its user timer on the same host to pull
the monitor's fixed Prometheus textfile through that restricted key. The export
command cannot read arbitrary files, and the pull validates the check-in metric
before atomically replacing anima's node-exporter textfile. This avoids a stale
LAN address and continues working wherever the phone's reverse tunnel connects.

The same nightly service must also run `millennium_server_state_backup.py`.
That helper streams an allowlisted archive directly into the existing encrypted
Restic repository—no plaintext archive is staged—and immediately streams the
saved archive back through `tar -t` to prove every required path is restorable.
It covers the update origin, doormand configuration, maintenance systemd units
and scripts, authorized public keys, and an installed copy of the recovery
instructions. The service refuses to acknowledge overall backup success if a
required path is missing or restore verification fails. Its latest evidence is
`~/.config/millennium-backup/server-state-last.json`.

Each phone stream carries a unique per-run Restic tag. If SSH fails after
Restic observes EOF, the wrapper resolves only snapshots with that run tag and
forgets their explicit IDs, preventing an empty or truncated stdin snapshot
from appearing valid. A successful phone snapshot is dumped back through
`tar -t` before retention or acknowledgement. The independent server-state
backup still runs when the phone is unavailable, but the combined service
correctly remains failed until both required legs succeed.

Install the backup-host components and recovery documentation with permissions
that keep the Restic credential private:

```bash
install -m 0755 host/monitoring/millennium_backup_pull.sh \
  ~/.local/bin/millennium-backup-pull
install -m 0755 host/monitoring/millennium_server_state_backup.py \
  ~/.local/bin/millennium-server-state-backup
install -d -m 0700 ~/.local/share/millennium-recovery
install -m 0600 host/docs/UNATTENDED_APPLIANCE.md \
  host/docs/SIGNING_KEY_LIFECYCLE.md ~/.local/share/millennium-recovery/
install -m 0644 host/monitoring/millennium-backup-pull.service \
  host/monitoring/millennium-backup-pull.timer ~/.config/systemd/user/
systemctl --user daemon-reload
systemctl --user enable --now millennium-backup-pull.timer
systemctl --user start millennium-backup-pull.service
```

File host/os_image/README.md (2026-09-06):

# Millennium Raspberry Pi OS image

This directory defines the minimal production operating-system image for the
Raspberry Pi Zero 2 W. It uses Raspberry Pi's official `rpi-image-gen`, pinned
by `rpi-image-gen.lock`, and adapts its rotational A/B layout to the MBR boot
scheme required by Zero 2 W firmware.

The image contains runtime dependencies and deployed application artifacts
only. Repository sources, compilers, QEMU state, package caches, and temporary
build files do not belong in the output.

## Layout

| Number | Purpose | Format/type |
| --- | --- | --- |
| 1 | boot control (`bootcode.bin`, `start.elf`, `autoboot.txt`) | FAT32 primary |
| 2 | boot A | FAT32 primary |
| 3 | boot B | FAT32 primary |
| 4 | logical-partition container | MBR extended |
| 5 | system A | ext4 logical |
| 6 | system B | ext4 logical |
| 7 | persistent device state | ext4 logical |

The static slot map is `a.boot=::2`, `a.system=::5`, `b.boot=::3`, and
`b.system=::6`. Persistent data uses the upstream `PERSISTENT` filesystem and
`/persistent` mount contract.

Because MBR partitions do not provide GPT partition labels, the image layer
installs that static map at `/boot/slot.map` before regenerating every
initramfs, then proves each generated archive contains it. The copy on each
boot FAT partition is retained for runtime inspection; the embedded copy is
what lets early boot create `/dev/disk/by-slot/{active,other}` before mounting
the root filesystem.

The image also embeds `89-millennium-mbr-slots` immediately before the
upstream root safety check. It reads the firmware-selected boot partition and
creates all four active/other aliases deterministically for partitions 2/5 and
3/6. Any other partition or missing block device still fails closed.

Zero 2 W's BCM2837 boot ROM loads `bootcode.bin` from the first FAT partition
before the second-stage firmware can process `autoboot.txt`. The preparation
transform therefore copies the pinned boot payload's real `bootcode.bin` and
`start.elf` into BOOTCONFIG. The selected A/B partition contains the same GPU
firmware plus the kernel and initramfs. Missing or empty firmware fails the
build; the independent verifier also proves the selector and selected-slot
copies match.

## Build

Build on native arm64 Debian Bookworm or Trixie. Clone the exact commit in the
lock file, prepare an isolated builder tree, then build with the project source
layer:

```sh
git clone https://github.com/raspberrypi/rpi-image-gen.git rpi-image-gen
git -C rpi-image-gen checkout 3f2c916086ad70197945bfc50ef953c1f6035f10
python3 tools/prepare_zero2w_image_builder.py \
  --upstream rpi-image-gen --output rpi-image-gen-zero2w
mkdir image-work
cd rpi-image-gen-zero2w
PATH=/usr/sbin:/sbin:$PATH ./rpi-image-gen build \
  -S ../host/os_image -c millennium-zero2w-ab.yaml -B ../image-work
```

The preparation script verifies the upstream commit and every transformed
source fragment. It refuses unknown upstream content instead of applying a
best-effort patch.

## Verify

Run the independent MBR/EBR parser against the raw image before publishing or
writing removable media:

```sh
python3 tools/verify_zero2w_image.py \
  --boot-content \
  image-work/image-millennium-zero2w-ab/millennium-zero2w-ab.img
```

Also inspect `autoboot.txt`, `slot.map`, the NetworkManager profile, enabled
units, account name, SSH policy, and deployed application payload. A successful
partition check alone is not a production release gate.

The built root filesystem must contain the project-owned
`/usr/lib/systemd/system-generators/slot-shared-generator`. Its regression test
proves that every `Path=` declaration creates both a mount unit and a
`local-fs.target.requires` link. The image-layer test also proves that the
project generator is reinstalled during cleanup, after the upstream image
overlay would otherwise replace it:

```sh
python3 -m unittest \
  tools.tests.test_slot_shared_generator \
  tools.tests.test_zero2w_image_layer
```

After booting the exact recovery image on a Zero 2 W, verify the runtime mount
topology before accepting any application health result:

```sh
findmnt -no SOURCE,OPTIONS /
findmnt -no SOURCE,OPTIONS /etc/millennium
findmnt -no SOURCE,OPTIONS /etc/ssh
findmnt -no SOURCE,OPTIONS /etc/NetworkManager/system-connections
findmnt -no SOURCE,OPTIONS /var/lib/millennium
```

The root source must be the active system slot and include `ro`. Every shared
path must be backed by the persistent partition and include `rw`. QEMU's
generic `virt` guest does not satisfy this physical-image gate.

Run `tools/audit_zero2w_rootfs.py` against the generated root and package
manifest. It rejects compiler/binutils, EEPROM and device-tree tooling that is
irrelevant to Zero 2 W, VCS/source residue, package caches, and temporary files.

For a new physical phone, generate all per-device secrets in a memory-backed
staging directory and run `tools/factory_seed_zero2w.py` on a copy of the raw
image. It seeds both system slots and the official shared/persistent paths,
checks the declared sharing contract, applies fixed ownership and modes, and
writes a privacy-safe provisioning record. Never publish or retain the seeded
whole-disk image: it contains the device's private host and tunnel keys.

The optional upstream Image Description Provisioning document is omitted for
this target because its schema rejects DOS logical partitions. The raw image is
still constructed by `genimage`, checked by `sfdisk`, and independently checked
by `verify_zero2w_image.py`.

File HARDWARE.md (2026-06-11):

# Hardware Assembly Reference

Physical hardware inside the Millennium payphone, how everything connects,
and notes from the current build.

## Components

| Component | Model / Part | Notes |
|---|---|---|
| Single-board computer | Raspberry Pi Zero 2 W | Single USB port, needs hub |
| Keypad microcontroller | Arduino Micro (custom) | "Millennium Alpha" board def |
| Display microcontroller | Arduino Micro (custom) | "Millennium Beta" board def |
| USB audio card | C-Media CM109 (Unitek Y-247A) | USB class-compliant, stereo out + mono mic in |
| USB hub | Huasheng USB2.0 HUB | 2 hubs daisy-chained for 3 ports. Supports per-port software power via uhubctl (-l 1-1 -a cycle -p 2 for display Arduino). |
| Boost converter | XL6009 module | Boosts 5V → 12V for coin validator only |
| Custom PCB | phonev6 | Connects all peripherals |
| VFD display | Noritake CU20026SCPB-T23A | 20×2 character VFD |
| Coin validator | Original Millennium part | 600 baud serial protocol |
| Magstripe reader | Original Millennium part | Clock + data signals |
| Handset | Original Millennium part | RJ9 connector (4P4C) |
| Ringer speaker | Original Millennium part | Front-mounted |
| Keypad | Original Millennium part | 4×7 matrix, 20-pin ribbon |
| 3D-printed case | PLA+ | Houses the PCB |

## USB Topology

The Raspberry Pi Zero 2 W has a single micro-USB OTG port. A USB hub provides
connectivity for all USB peripherals:

```
Pi Zero 2 W (USB OTG)
  └─ USB Hub #1
       ├─ USB Hub #2
       │    ├─ Arduino "Millennium Alpha" (keypad)
       │    └─ Arduino "Millennium Beta" (display)
       └─ C-Media USB Audio Adapter
```

The two Arduinos enumerate as USB serial devices:
- `/dev/serial/by-id/usb-Arduino_LLC_Millennium_Alpha-if00`
- `/dev/serial/by-id/usb-Arduino_LLC_Millennium_Beta-if00`

The USB audio card appears as ALSA `hw:1,0`.

## Cable Routing

Inside the payphone, cables route from the original hardware to the custom PCB:

| Cable | From | To | Connector |
|---|---|---|---|
| Keypad ribbon | Keypad matrix | PCB J2 (2×10 header) | 20-pin IDC |
| Display ribbon | VFD display | PCB J3 (2×13 header) | 26-pin IDC |
| Coin validator | Coin mechanism | PCB J1 (2×5 header) | 10-pin IDC |
| Magstripe reader | Card slot | PCB J6 (2×7 header) | 14-pin IDC |
| Handset | Handset cord | PCB J4 (RJ9 jack) | 4P4C RJ9 |
| Mic audio | USB audio card out  | PCB J5 (3.5mm jack) | 3.5mm stereo  |
| Speaker audio | USB audio card out  | PCB J7 (3.5mm jack) | 3.5mm stereo  |
| USB (display) | PCB Arduino Beta | Pi via USB hub | Micro-USB |
| USB (audio) | USB audio card | Pi via USB hub | USB-A |
| Power | 5V supply | PCB power input (5V) | Screw terminal |

## Power

The board is powered from an external 5V supply. The 5V_MAIN rail powers
everything except the coin validator: both Arduinos, the Raspberry Pi (via
GPIO 5V pins), the VFD display logic, the audio amplifier (TDA2822M), the
card reader, and the USB hub. The coin validator requires 12V; the XL6009
(U1) boost converter generates 12V_COIN from 5V input, and that rail feeds
only the coin validator.

Total estimated current draw:

| Rail | Component | Current (typical) |
|---|---|---|
| 5V_MAIN | Raspberry Pi Zero 2 W  | 150 mA |
| 5V_MAIN | Arduino Micro × 2 | 50 mA each |
| 5V_MAIN | VFD display | 100 mA |
| 5V_MAIN | USB audio card | 50 mA |
| 5V_MAIN | Audio amplifier | 50–200 mA (playing) |
| 5V_MAIN | USB hub | 50 mA |
| 5V_MAIN | **Subtotal** | **~550–700 mA** |
| 12V_COIN | Coin validator (via U1)| ~50 mA |

The external 5V supply must provide enough current for both 5V_MAIN loads and
the XL6009 input (which draws from 5V to produce 12V_COIN for the coin validator).
The quad-core Zero 2 W can draw well above the ~150 mA typical figure under
sustained multi-core load, so size the supply with headroom (a 2 A+ supply is
recommended).

## Thermal

The original Pi Zero W ran at approximately 38°C inside the closed case with no
active cooling. The quad-core Zero 2 W runs warmer under sustained load but
stays well within operating limits (throttling starts at 80°C). The phone's
metal enclosure acts as a passive heat sink.

## Physical Mounting

The custom PCB sits inside a 3D-printed PLA+ case (see `case/README.md`).
The case mounts inside the payphone's internal cavity. The original
Millennium control board is removed and replaced with this assembly.

Original hardware (keypad, display, coin validator, magstripe reader, handset,
ringer) remains in place and connects to the PCB via ribbon cables and the
RJ9/3.5mm jacks.

## Serial Numbers and Device IDs

| Device | USB VID:PID  | Serial Name |
|---|---|---|
| Keypad Arduino | 2341:8045 | Millennium Alpha |
| Display Arduino  | 2341:8046 | Millennium Beta |
| USB Audio | 0d8c:0014 | Audio Adapter |

The custom Arduino board definitions assign unique VID/PID pairs so the
Arduinos can be identified by name in `/dev/serial/by-id/`.

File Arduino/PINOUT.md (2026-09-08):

# Arduino Pinout Reference

This document maps every Arduino pin used by the firmware to its physical function and PCB connector.

## Board Assignments

| Board Name | Ref | FQBN | USB Product Name  | Firmware |
|---|-----|---|---|---|
| Millennium Alpha  | A1  | `millennium:avr:millennium_alpha`  | Millennium Alpha  | `keypad.ino` |
| Millennium Beta | A2  | `millennium:avr:millennium_beta` | Millennium Beta | `display.ino` |

Both are ATmega32U4-based (Arduino Micro clones) at 16 MHz. The custom board
definitions only change the USB VID/PID so the Pi can distinguish them via
`/dev/serial/by-id/`.

## Keypad Arduino (Millennium Alpha, A1)

| Arduino Pin | ATmega32U4 Pin | Function | Direction | Notes |
|---|---|---|---|---|
| 0 | PD2 (RXD1) | MagStripe RDT (data) | Input (ISR)  | Shared with HW UART RX — see note  |
| 1 | PD3 (TXD1) | MagStripe RCL (clock) | Input (ISR)  | Shared with HW UART TX — see note  |
| 4 | PD4 | Hook down sense | Input pullup | |
| 5 | PC6 | Hook up sense | Input pullup | |
| 6 | PD7 | Keypad row 3 (* 0 #) | I/O | |
| 7 | PE6 | Keypad row 2 (7 8 9) | I/O | |
| 8 | PB4 | Keypad row 1 (4 5 6) | I/O | |
| 9 | PB5 | Keypad row 0 (1 2 3) | I/O | |
| 10 | PB6 | Keypad col 0 | I/O | |
| 11 | PB7 | Keypad col 1 | I/O | |
| 12 | PD6 | Keypad col 2 | I/O | |
| 13 | PC7 | Keypad col 3 | I/O | Extra columns (A-P keys) |
| 18 (A0) | PF7 | Keypad col 4 | I/O | Extra columns (A-P keys) |
| 19 (A1) | PF6 | Keypad col 5 | I/O | Extra columns (A-P keys) |
| 20 (A2) | PF5 | Keypad col 6 | I/O | Extra columns (A-P keys) |
| 21 (A3) | PF4 | Hook common pin | Output | Driven LOW to scan, HIGH at idle |
| 22 (A4) | PF1 (ADC1) | MagStripe CLS (card present) | Input | |
| 2 (SDA) | PD1 | I2C SDA (master) | I/O | To display Arduino |
| 3 (SCL) | PD0 | I2C SCL (master) | I/O | To display Arduino |

### Notes

**Pins 0/1 (MagStripe) vs UART**: On the ATmega32U4, USB serial (`SerialUSB`)
uses the native USB peripheral, not the hardware UART on pins 0/1. So
`Serial1` (PD2/PD3) is free and there is no conflict between the MagStripe
interrupt pins and USB communication. This is correct.

**Hook switch technique**: Pin 21 is configured as OUTPUT in `setup()` and
driven LOW to scan the hook switch, then returned HIGH. A 50 ms debounce timer
prevents spurious events from switch bounce.

**4x7 keypad matrix**: Columns 3–6 map keys A–P which are not standard phone
keys. The daemon only processes `0`–`9`, `*`, `#`, so these extra keys are
silently ignored. They correspond to extra button positions on the Millennium
keypad PCB (volume, language, etc.).

## Display Arduino (Millennium Beta, A2)

| Arduino Pin | ATmega32U4 Pin | Function | Direction | Notes |
|---|---|---|---|---|
| 0 (RX) | PD2 (RXD1) | VFD RD (read strobe) | Output | |
| 1 (TX) | PD3 (TXD1) | VFD AD (address) | Output | |
| 4 | PD4 | VFD WR (write strobe)| Output | |
| 5 | PC6 | VFD D0 | Output | |
| 6 | PD7 | VFD D1 | Output | |
| 7 | PE6 | VFD D2 | Output | |
| 8 | PB4 | VFD D3 | Output | |
| 9 | PB5 | VFD D4 | Output | |
| 10 | PB6 | VFD D5 | Output | |
| 11 | PB7 | VFD D6 | Output | |
| 12 | PD6 | VFD D7 | Output | |
| 13 | PC7 | VFD RESET | Output | |
| 14 (MISO) | PB3 | Coin validator RX | Input | SoftwareSerial at 600 baud |
| 15 | PB1 | Coin validator RESET | Output | Active-low reset |
| 16 | PB2 | VFD TEST | Output | |
| 17 (SS) | PB0 | VFD CS (chip select) | Output | |
| 23 | N/A | Coin validator TX | Output | SoftwareSerial (pin 23 is TX)|
| 2 (SDA) | PD1 | I2C SDA (slave) | I/O | Slave address 0 |
| 3 (SCL) | PD0 | I2C SCL (slave) | I/O | |
| USB | Native USB | SerialUSB to Pi | I/O | 9600 baud |

### VFD Pin Mapping (Noritake CU20026SCPB-T23A)

| VFD Pin | Signal | Arduino Pin | Wire Color |
|---|---|---|---|
| 1 | D7 | 12 | gray |
| 3 | D6 | 11 | white |
| 5 | D5 | 10 | black |
| 7 | D4 | 9 | brown |
| 9 | D3 | 8 | red |
| 11 | D2 | 7 | orange |
| 13 | D1 | 6 | yellow |
| 15 | D0 | 5 | green |
| 17 | WR | 4 | blue |
| 19 | AD | 0 (RD=1) | violet |
| 21 | RD | 1 (AD=0) | gray |
| 23 | CS | 17 | white |
| 25 | TEST | 16 | black |
| 20 | RESET  | 13 | yellow |

## I2C Bus

- **Master**: Keypad Arduino (A1) via `Wire.begin()`
- **Slave**: Display Arduino (A2) via `Wire.begin(8)`
- **Address**: 8 (`I2C_DISPLAY_ADDR` on both controllers)
- **Pull-ups**: External pull-ups required on SDA/SCL (check PCB)

### Protocol (Keypad → Display → Pi)

The keypad Arduino sends complete protocol-v2 frames over I2C. The display
Arduino's `receiveEvent` ISR forwards each byte unchanged over USB serial to the
Pi. Key, hook, credential, and diagnostic types are defined in
[`../docs/MCU_PROTOCOL.md`](../docs/MCU_PROTOCOL.md). The Wire buffer limits an
Alpha frame to 32 bytes and its credential payload to 24 bytes.

### Pi → Display Arduino (USB Serial)

All commands use the versioned frame described in `docs/MCU_PROTOCOL.md`.
Display, coin control, EEPROM program, and EEPROM verify are types `0x10`–`0x13`;
`0x14` is reserved and identity is `0x15`. Critical commands are acknowledged by sequence number and
replays are not executed twice.

### Coin Validator → Pi

When the coin validator sends a byte over SoftwareSerial, the display Arduino
wraps it as a `MCU_EVT_COIN` (`0x23`) frame and forwards it over USB serial.

## Custom Board Definitions

The board definitions are vendored in the repo (#256):
```
Arduino/hardware/millennium/avr/boards.txt
```

Key differences from stock Arduino Micro:

| Property | Stock Micro | Millennium Alpha  | Millennium Beta  |
|---|---|---|---|
| USB PID (app)  | 0x0037 | 0x0045 | 0x0046 |
| USB PID (boot) | 0x8037 | 0x8045 | 0x8046 |
| Product name | Arduino Micro  | Millennium Alpha  | Millennium Beta  |
| Bootloader | Caterina-Micro | Caterina-Micro | Caterina-Micro |

The boards run **stock** Caterina bootloaders flashed at the factory. The old
hand-edited definitions named `Caterina-Micro-Millennium-Alpha.hex` / `-Beta.hex`
bootloaders that were never built; the vendored definitions drop those keys,
since burning a bootloader is not part of any workflow here.

The practical consequence is that the custom product name only applies while the
**sketch** is running. During the bootloader window both boards present as a
plain `Arduino Micro` — which is why `pi_flash.sh` flashes the
`usb-Arduino_LLC_Arduino_Micro-if00` path and resets only one board at a time
(#254).

If a board is ever bricked badly enough to need its bootloader reflashed, stock
`Caterina-Micro.hex` is the right image; the custom identity comes back as soon
as a sketch is uploaded.

## Known Issues and Recommendations

1. ~~**I2C address 0 is the general call address**~~. **Resolved** — display
   Arduino now uses `Wire.begin(8)` (`I2C_DISPLAY_ADDR`), and the keypad
   addresses it as `Wire.beginTransmission(8)`.

2. ~~**No hook switch debounce**~~. **Resolved** — `keypad.ino` now uses a 50 ms
   timer-based debounce (`DEBOUNCE_MS`) before reporting hook state changes.

3. ~~**`parseTrack2` has no bounds checking**~~. **Resolved** — all sentinel
   search loops use the `length` parameter as an upper bound.

4. ~~**`receiveEvent` ISR writes to `SerialUSB`**~~. **Resolved** — `receiveEvent`
   now writes to a lock-free ring buffer; `loop()` drains it to `SerialUSB`.

5. ~~**Blocking serial reads in `display.ino`**~~. **Resolved** — `waitForSerial()`
   implements a 2-second timeout (`SERIAL_TIMEOUT_MS`).

6. ~~**No watchdog timer**~~. **Resolved** — both sketches enable a 4-second
   watchdog (`WDTO_4S`) in `setup()` and pet it every `loop()` iteration (and
   inside the long EEPROM program/verify loops in `display.ino`).

7. ~~**Dead code**~~. **Resolved** — `#if 0` debug blocks and unused `vfdtest()`
   have been removed.

8. ~~**Coin EEPROM data is hardcoded**~~. **Resolved** — `coinEeprom[]` in
   `display.ino` now has a block comment documenting the structure: global config,
   per-coin-type acceptance windows (nickel, dime, quarter, dollar), calibration
   block, and hardware provenance (TRC-6500).

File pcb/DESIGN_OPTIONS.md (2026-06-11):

# PCB Design Options: Bus Breakout & Direct UART

Design exploration for phonev6+ revisions.

## 1. Bus Breakout Connector (I/O on Separate Board)

**Goal:** Put J1–J7 (coin, keypad, VFD, handset, mic, card, speaker) on a separate I/O board, connected to the main board via a bus.

### Signal Count

| Connector | Pins | Notes |
|---|---|---|
| J1 Coin validator | 10 | 12V, GND, TX, RX, RESET, + unused |
| J2 Keypad | 20 | 14 used (rows 0–3, cols 0–6, hook) |
| J3 VFD display | 26 | 14 used (D0–D7, WR, AD, RD, CS, TEST, RESET) |
| J4 Handset RJ9 | 4 | mic+, speaker+, GND |
| J5 Mic | 3 | sig, shield, switch |
| J6 Card reader | 14 | 3 used (CLS, RDT, RCL) |
| J7 Speaker | 3 | stereo L/R, GND |
| **Subtotal I/O** | **~80** | |
| Power (5V, GND, 12V_COIN) | 3 | |
| I2C (SDA, SCL) | 2 | Keypad ↔ Display |
| **Total** | **~85** | |

### Bus Connector Options

| Option | Connector | Pins | Cost | Notes |
|---|---|---|---|---|
| A | 2× 2×20 IDC ribbon | 80 | Low | Two 40-pin ribbons (keypad/VFD/coin on one, audio/card/handset on other) |
| B | 1× 2×25 IDC | 50 | Low | Single ribbon; need to reduce pins or use two boards |
| C | FFC/FPC (flex) | 40–60 | Medium | Single cable, smaller footprint |
| D | Board-to-board (e.g. Samtec) | 60–80 | Higher | More robust, good for modular layout |

**Recommended:** Option A — two 2×20 (40-pin) IDC connectors. Split logically:
- **Bus A:** Keypad (J2), VFD (J3), Card (J6) → ~50 signals → use two rows of a 2×20 or a 2×25
- **Bus B:** Coin (J1), Handset (J4), Mic (J5), Speaker (J7), power, I2C → ~25 signals → one 2×20

Or a single 2×25 (50-pin) if all critical signals fit; some keypad/VFD pins could be dropped if not all keys/features are used.

### Main Board vs I/O Board

**Main board (with bus connector):**
- Arduino Micro ×2 (A1, A2)
- Raspberry Pi
- TDA2822M, XL6009
- Power input (Q1, F1)
- **Bus connector** (replaces direct J1–J7 footprint)
- USB hub connection (unchanged)

**I/O board (daughter / remote):**
- J1, J2, J3, J4, J5, J6, J7
- Bus connector (mates to main)
- Optional: local ESD/TVS on long lines (D1–D3 could move here)
- Routing: straight pass-through from bus pins to connector pins

### KiCad Implementation

1. Create a new schematic sheet for "I/O Board" with J1–J7 and a bus connector symbol.
2. On the main schematic, replace J1–J7 with a single "J_BUS" connector that carries all nets.
3. Define the bus pinout in a table (e.g. `BUS_PINOUT.md`) so both boards stay in sync.
4. For a two-board design, either:
   - One project with two PCB files (main + I/O), or
   - One project, one PCB with a clearly defined "split line" for a future mechanical break.

---

## 2. Direct UART from Pi (Bypass USB for Arduino ↔ Pi)

**Goal:** Connect Pi UART (GPIO 14/15) directly to Arduino serial, avoiding USB hub and `/dev/ttyACM*`.

### Current Architecture

- **Pi ↔ Display Arduino:** USB CDC (SerialUSB) at 9600 baud
- **Pi ↔ Keypad Arduino:** Indirect — keypad → display (I2C) → display → Pi (USB)
- **Pi UART:** GPIO 14 (TX), GPIO 15 (RX) exist on the Pi header but are **unconnected** on phonev6

### Challenge: Arduino Pin Usage

| Arduino | HW UART (pins 0/1) | USB |
|---|---|-----|
| Keypad (A1) | MagStripe RDT, RCL | Not used for Pi |
| Display (A2) | VFD RD, AD | **Used for Pi** |

The display Arduino uses its only hardware UART (Serial1) for the VFD. Pi communication is over SerialUSB (native USB). So we **cannot** simply wire Pi UART to Arduino pins 0/1 on the display without reallocating VFD pins.

### Options for Direct UART

#### Option 2a: Repin Display Arduino

- Move VFD RD and AD to two other GPIO pins (e.g. 18, 19).
- Use pins 0 (RX) and 1 (TX) for Pi UART.
- **Level shifting required:** Pi = 3.3V, Arduino Micro = 5V. Use bidirectional shifter (e.g. TXS0108E, BSS138, or 74LVC245).
- **Firmware:** Use `Serial1` for Pi instead of `SerialUSB`. Daemon would open `/dev/ttyS0` or `/dev/serial0` instead of `/dev/serial/by-id/...`.

**Pros:** One UART link, no USB for display
**Cons:** Pin shuffle, level shifter, firmware changes, lose USB identity (no by-id)

#### Option 2b: Add USB-UART Bridge on Pi

- Add a USB-UART IC (e.g. CH340, CP2102) on the PCB, fed from Pi 3.3V.
- Connect its UART side to the display Arduino’s Serial1 (with level shifting).
- Pi talks to the bridge as `/dev/ttyUSB0`. Same idea as "direct" UART but still USB from the Pi’s perspective.

**Pros:** No change to Arduino pinout
**Cons:** Extra part, still USB on the Pi side, just different topology

#### Option 2c: Keep USB, Improve Topology

- Use a Pi 4/5 with multiple USB ports → no hub, simpler wiring.
- Or keep Pi Zero + hub, but this doesn’t address "direct from Pi."

#### Option 2d: Pi UART ↔ Keypad Only

- Keypad doesn’t talk to the Pi directly today; everything goes through the display.
- To use Pi UART, we’d need the keypad to talk to the Pi over UART instead of I2C→display→USB. That’s a protocol/architecture change.

**Conclusion:** Direct Pi UART is possible if we repin the display (Option 2a) and add level shifters. It removes USB for that link and avoids hub/enumeration issues, at the cost of pin changes, new parts, and firmware updates.

---

## Summary

| Question | Feasible? | Approach |
|---|---|---|
| Bus breakout for I/O? | **Yes** | Add a multi-pin bus (e.g. 2×20 or 2×25 IDC) to the main board; create an I/O daughter board with J1–J7; document pinout. |
| Pi UART for Arduino? | **Yes, with changes** | Repin VFD RD/AD, use Serial1 for Pi, add 3.3V↔5V level shifter, update daemon to use `/dev/ttyS0`. |

If you want to proceed, the next step is a concrete pinout table for the bus connector and (if desired) a proposed VFD repin + UART schematic fragment.

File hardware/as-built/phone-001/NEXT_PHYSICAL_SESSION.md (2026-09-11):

# Phone 001 final physical acceptance session

This is the shortest safe path through every remaining hardware-dependent
gate. Keep the phone assembled and connected for the entire session; the order
below is intended to avoid another teardown or network rewire. None of these
steps may be replaced by QEMU evidence.

Before touching the phone, validate the coverage inventory and print the exact
remaining physical-only plan:

```bash
python3 tools/coverage_ledger.py validate
python3 tools/coverage_ledger.py physical-plan
```

Run the `host` and `contracts` ledger suites locally and the `qemu` suite on
`anima`. Do not begin this session unless all three pass for the candidate
source commit. The physical plan intentionally coalesces every remaining claim
into the single assembly, Wi-Fi-client, interruption, external-network, and
playtest phases below; it is the machine-checked guard against silently adding
an untested shipped function or repeating a hardware setup unnecessarily.

## Bring once

- the production-equivalent Raspberry Pi Zero 2 W;
- the controller board, Alpha and Beta Arduinos, display, keypad, handset,
  audio path, coin validator, and any token/card reader, all connected as they
  will be handed off;
- the production power supply plus a meter or oscilloscope capable of recording
  minimum 5 V rail voltage during boot, ringing, coin operation, and brownout;
- one dedicated, OS-reported removable SD card of at least 32 GB for recovery;
- two additional, physically distinct removable media for the new offline
  experience package/catalog signing keys (do not reuse the recovery card);
- the disconnected signing machine and both custodians' full OpenPGP hardware
  key fingerprints;
- the Mac with this repository and `UEBuild` attached;
- iOS, Android, macOS, and Windows clients;
- a cellular hotspot or other network that is genuinely outside the home ISP;
- two first-time callers who have not read the story documentation.

Do **not** use the 512 GB `UEBuild` volume as recovery media, regardless of the
`/dev/diskN` number macOS assigns it. It holds the builder, retained images, and
signing-key backup. Identify the recovery card by its reported media name,
capacity, and removable status immediately before writing it.

## 0. Establish and provision the experience trust roots

No production experience signing key currently exists in the repository,
local restricted storage, or `anima`'s retained signing vault. Before
publishing a catalog, generate separate package and catalog Ed25519 keys on the
disconnected signing machine. Export only their public keys. For each private
key, use `tools/signing_key_backup.py backup` for both custodians, copy the two
encrypted ciphertexts to distinct removable media with `copy-offline`, and run
an independent `recover` sign/verify drill from each read-only medium-backed
copy. Retain the evidence records and destroy the plaintext RAM-backed scratch
directory after each operation.

Add both public keys to the phone through an OTA release authenticated by the
existing `release-2026-08` trust root. Confirm their exact DER SHA-256 values
on the rebuilt phone before signing any production content. Never copy either
private key to this repository, the phone, `anima`, or the update web root.

After all content unit and QEMU gates pass, build and sign immutable packages
and stable/beta/device-group catalogs offline as described in
`content/README.md`. Transfer only the signed artifacts and public keys to a
private staging directory on `anima`, then run `content/publish_catalog.py`
against `/home/kmatzen/selfhosted/millennium-updates/www/experiences`. Verify
the public catalog, signature, and every catalog-bound immutable object before
enabling the phone's automatic catalog timer. The nginx container reads that
host directory through a read-only bind mount and does not require a restart.

## 1. Write and verify the corrected recovery card

**Current candidate `940d118` is the only candidate eligible for the next
write.** It supersedes `9a343aa`, `27b69be`, `7033d94`, and `c409237`.
Physical boot of `9a343aa` proved the persistent namespace roots, effective
update trust, read-only root, owner Wi-Fi, both Arduinos, and outbound
maintenance tunnel, but exposed missing version and source-commit fields in
the bootstrap release record. `940d118` makes that metadata mandatory during
image staging and rejects its absence in the rootfs audit. The fresh image's
formal host, contracts, both-slot exact-image, full QEMU, signing, public OS
endpoint, and real-phone disposable updater-selection gates passed. The signed
expanded SHA-256 is
`f20a50bef7eb238993cd5a008561c6c90f0a1bcd95f0173332e293025bd833ea`;
the compressed SHA-256 is
`c6cd78c09a208609118af82a80e88f24c44ccc896ff2bf34b5ce3bae5872c906`.
The verified package is retained at
`/Volumes/UEBuild/millennium-images/zero2w-ab-1.0.0-940d118-phone001-unapproved`.
Exact evidence is in
`evidence/zero2w-recovery-seeded-artifact-940d118-2026-09-11.json`.

The dedicated card write is complete. macOS identified `/dev/disk12` as the
63,864,569,856-byte removable USB card and separately identified `UEBuild` as
the fixed 512 GB disk. The writer verified the release signature and compressed
artifact, wrote and flushed all 15,636,365,312 expanded bytes, and hashed the
complete image length back. Readback matched signed SHA-256
`c3d4efd4eb19bf1d88a02227792d56912e8b51315c1d81ee7cdb3815556ecbaa`.
The card was ejected successfully. Physical cold boot and the 125-second
health gate remain open. Exact evidence is in
`evidence/recovery-media-phone001-9a343aa.json`.

**Do not redeploy this written `9a343aa` card.** Its physical boot proved the
trust-path, persistent-state, Wi-Fi, tunnel, native-MCU, and SIP recovery fixes,
but the installed HIL found that the bootstrap `release.json` lacks host
version metadata. The real OS updater also rejected the first published OS
manifest because its board model omitted `Rev 1.0`; corrected sequence 2 passed
the physical compatibility check but was quarantined before any automatic
installation. A replacement image must include complete bootstrap metadata,
pass the static rootfs audit that now enforces it, and publish an OS release
whose exact board identity is validated by the real phone updater. Evidence is
in `evidence/physical-boot-rejection-9a343aa-2026-09-11.json`.

The formerly empty production OS channel is no longer a pre-write blocker.
Signed baseline OS release `00000001-1.0.0` is published at the production
HTTPS origin. Its manifest signature, compatibility selection, compressed
objects, and complete 3,489,660,928-byte expansion were independently fetched
and verified from `anima` after publication. The expanded boot and root hashes
match the exact generic images used to build the qualified `9a343aa` recovery
candidate. Publication is fail-closed, immutable by release identity, and uses
the stable manifest rename as its commit point. Exact evidence is in
`evidence/os-release-00000001-1.0.0-production-2026-09-11.json`.

**The `27b69be` card is rejected and must not be redeployed.** Physical boot of
`c409237`
reached owner Wi-Fi and the maintenance tunnel but exposed missing persistent
state roots for both application and OS update checks. `27b69be` provisions
and exact-image-tests all production namespace roots: `ota`, `os-ota`, `hil`,
`backup`, and `physical-tests`. Both production system slots, the full QEMU
lab, host suite, contracts suite, and formal release gate passed on `anima`
without making a physical-hardware claim. The signed expanded SHA-256 is
`ea10c9f4c3e062c80f323535a0d1fdb9cc7138b66f5067edfae983f47dcfa55b`;
the compressed SHA-256 is
`114c7a83ae302778b5779c2045b7b281dbd88e919f0905949e5819b84060127e`.
The package is retained on `anima` at
`/data2/millennium-build-27b69be/recovery-package` and independently verified
on external storage at
`/Volumes/UEBuild/millennium-images/zero2w-ab-1.0.0-27b69be-phone001-unapproved`.
Exact evidence is in
`evidence/zero2w-recovery-seeded-artifact-27b69be-2026-09-11.json`.

**The signed `7033d94` package is superseded and must not be written.** It
fixed only the application OTA root; the later physical audit also exposed the
missing OS OTA root and showed that the remaining declared persistent roots
had not been provisioned or exercised.

**The `c409237` card is rejected and must not be redeployed.** Its physical
boot proved the corrected captive-portal firewall path, owner Wi-Fi
association, setup-AP shutdown, and outbound maintenance tunnel. It also
proved that the scheduled update check could not start because the production
image lacked `/var/lib/millennium/ota`; that defect is corrected and
regression-tested only in `7033d94` and later.

**The superseded `1f63772` candidate was built, factory-seeded, signed, and
accepted by its automated gates, but failed physical captive handoff and must
not be redeployed.** Its unchanged
application payload is from `4a15bf6`; the image-layer correction is
`1f63772`, and the final exact-image harness is `ff27782`. The exact seeded
image is retained on `anima` at
`/data2/millennium-build-1f63772/phone001-1f63772.img`; its expanded SHA-256 is
`aa1b2b0b1d5b312709666db22d6246ae0cfd921ba13cce595a59893ed5142e71`
and its size is 15,636,365,312 bytes. Full QEMU evidence is in
`/data2/millennium-build-1f63772/repo/tools/qemu/state/artifacts/full-20260909T171854Z/`.
Its compressed recovery artifact and canonical manifest are signed with the
active offline release key and independently verified on macOS, `anima`, and
the non-overwriting external `UEBuild` copy. All four hashes, the public-key
identity, signature, and complete expanded stream match without using laptop
internal storage. The dedicated 63.9 GB removable card was written on
2026-09-10, flushed, completely read back, matched signed expanded SHA-256
`aa1b2b0b1d5b312709666db22d6246ae0cfd921ba13cce595a59893ed5142e71`,
and safely ejected. Exact evidence is in
`evidence/zero2w-recovery-seeded-artifact-1f63772-2026-09-09.json` and
`evidence/recovery-media-phone001-1f63772.json`. Insert and boot this card; do
not use any predecessor card for acceptance.

**The `4a15bf6` card was written and fully read back, but its physical boot is
rejected.** `daemon.service` failed with systemd `203/EXEC` because the image
installed `/opt/millennium` as `root:root 0750`; the unprivileged `millennium`
service user could not traverse the executable path. The previous exact-image
test had accepted an echoed marker before its assertions ran. The `1f63772`
replacement fixes both the image mode and the gate. Evidence is in
`evidence/recovery-media-phone001-4a15bf6.json` and
`evidence/zero2w-recovery-seeded-artifact-1f63772-2026-09-09.json`. Do not
redeploy `4a15bf6`.
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

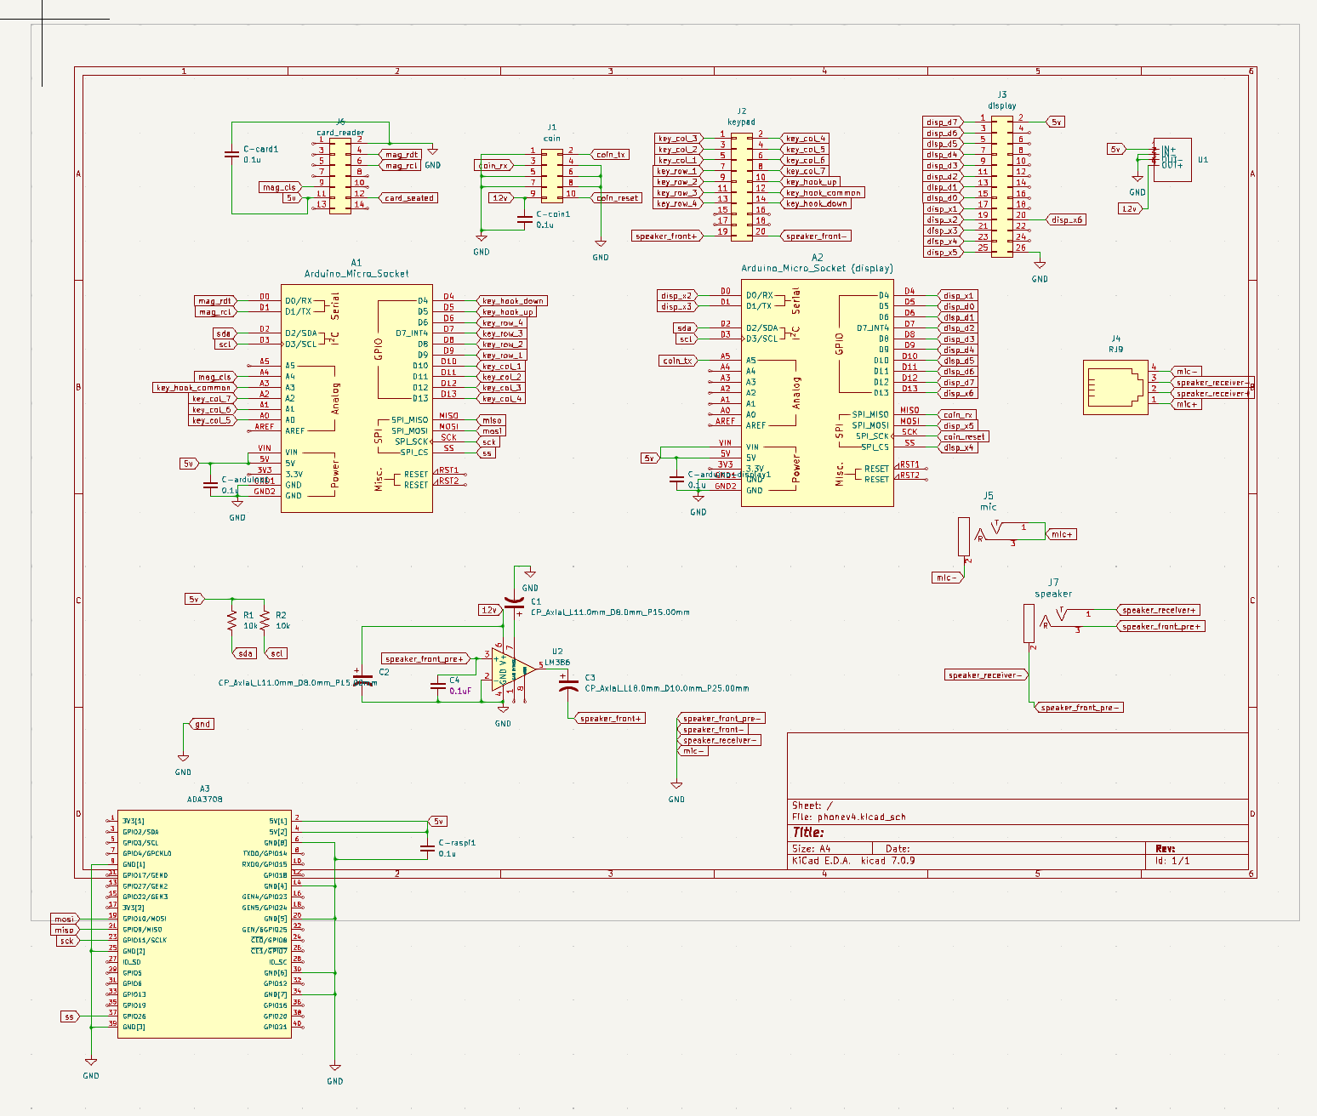
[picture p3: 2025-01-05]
pcb/schematic_screenshot.png

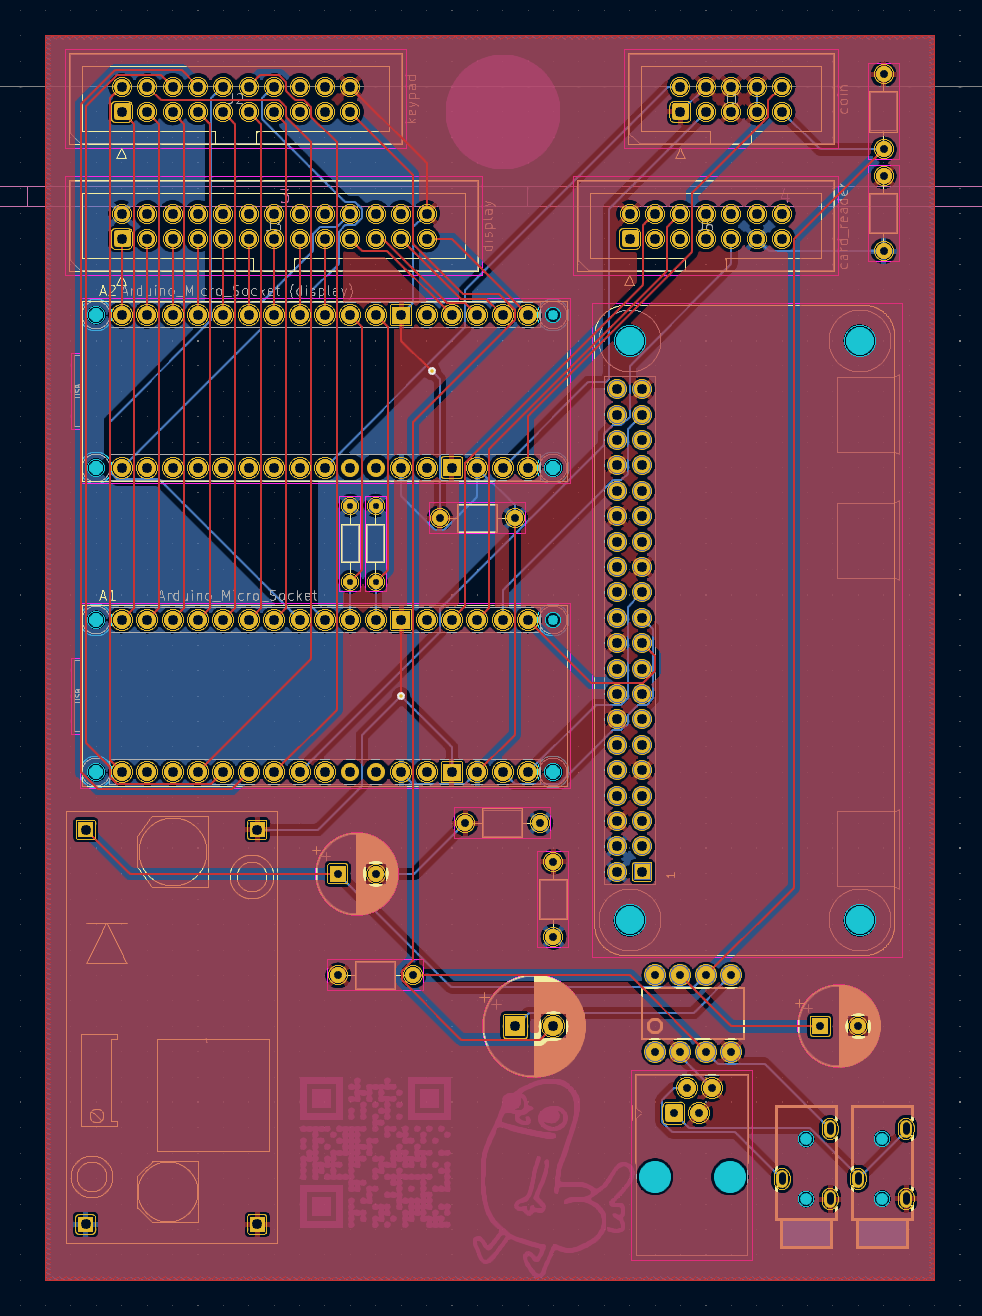
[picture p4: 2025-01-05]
pcb/pcb_screenshot.png

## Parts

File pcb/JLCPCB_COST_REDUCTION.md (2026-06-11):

# JLCPCB Assembly Cost Reduction: Basic vs Extended Parts

JLCPCB charges **$3 per unique extended component** (Economic PCBA) or **$1.50** (Standard PCBA). Basic parts have **no loading fee** because they are pre-loaded on pick-and-place machines. This document identifies extended parts in the phonev6 design and recommends basic alternatives where available.

## Cost Summary

| Category | Current | Basic Alternative | Savings (Economic) |
|---|---|---|---|
| Q1 P-MOSFET | Si2319A (C545576) extended | **AO3401A (C15127)** basic | $3 |
| R1,R2 4.7kΩ | 0805 C17673 basic | (already basic) | — |
| R3,R4,R5 1kΩ | 0805 C11702 basic | (already basic) | — |
| 100nF caps | 0805/0603 basic | C14663, C1525 | — |
| 100µF caps | CP_Elec (SMD) | C15008 (1206 MLCC) or C16133 (tantalum) | Consider for decoupling |
| U2 Audio amp | PT2308-S (C115492) extended | No basic dual audio amp | — |
| D1–D3 TVS | P6KE6.8CA (D_SMB) extended | Check SMB TVS basic options | TBD |
| F1 Fuse | 1812 SMD | Check basic fuse options | TBD |
| D4 LED | LED_0603 SMD | Basic LED options exist | — |
| Connectors | IDC, RJ9, PJ-320, Arduino, Pi, XL6009 | Usually extended | — |

## Implemented Replacements

### Q1 → AO3401A (Basic)

**Replaced:** Si2319A (C545576) → **AO3401A (C15127)** [JLCPCB basic]

- Same SOT-23 package, compatible pinout (G-S-D)
- AO3401A: 30V, 4A, 47mΩ @ 10V — sufficient for 5V reverse polarity (F1 is 1A)
- Saves $3 per board (Economic assembly)

### D4 LED → Red LED C2286 (Basic)

**Replaced:** Green LED (C125094) → **Red LED (C2286)** [JLCPCB basic, 0603]

- Same LED_0603 footprint
- Red is standard for power indicators
- Saves $3 per board if green was extended

### R1, R2 (4.7kΩ) → C17673 (Basic)

**Updated:** LCSC C17673 for 4.7kΩ 0805 resistors [JLCPCB basic]

### R3, R4, R5 (1kΩ) → C17513 (Basic)

**Updated:** LCSC C17513 for 1kΩ 0805 resistors [JLCPCB basic]

## Parts Already Basic or SMD

The design already uses many cost-effective choices:
- **Resistors:** 0805 (4.7k, 1k) — basic part C17673, C11702
- **Capacitors:** 0805 100nF, 0402 — basic MLCCs available
- **LED:** 0603 SMD — basic LED options in JLCPCB library
- **Fuse:** 1812 SMD (not radial THT) — check JLCPCB for basic 1A fuse

## Likely Extended (No Easy Basic Replacements)

| Part | LCSC | Notes |
|---|---|---|
| PT2308-S (U2) | C115492 | Dual audio amp SOIC-8; no basic dual audio amp in JLCPCB library |
| P6KE6.8CA (D1–D3) | — | TVS D_SMB; SMD TVS often extended |
| Arduino sockets, ADA3708, XL6009 | — | Connectors and modules are typically extended |
| IDC headers, RJ9, PJ-320 | — | Connectors usually extended |

## Verification Steps

1. **Upload BOM to JLCPCB** — Use KiCad's JLCPCB Fabrication Toolkit (File → Fabrication Outputs → JLCPCB) and upload the generated BOM. JLCPCB will flag each part as basic or extended and show the total loading fees.
2. **Check active basic parts list** — [lrks.github.io/jlcpcb-economic-parts/active.html](https://lrks.github.io/jlcpcb-economic-parts/active.html) (updated periodically).
3. **JLCPCB Part Search** — [jlcpcb.com/parts/componentsearch](https://jlcpcb.com/parts/componentsearch) — filter by "Basic" to find alternatives.

## Other Cost Savings (Non-Component)

### Assembly Service Level

- **Economic PCBA**: $3 per extended part loading fee. Best when you have few extended parts (as after our replacements).
- **Standard PCBA**: $1.50 per extended part. Compare total quote—with fewer extended parts, Economic is often cheaper.

### Panelization

- **50+ units:** Use "Panel by JLCPCB" to combine boards. Reduces the $0.46/board minimum assembly processing surcharge.
- **Suggested:** 150–200 mm panel, 2–6 boards per panel (V-cut or mouse-bites).

### Order Quantity

- **Volume discounts (PCB fabrication):** 50+ boards + area > 10 m² triggers FR4 discounts.
- **Assembly:** Per-board cost drops with quantity; fewer setup amortization per unit.

### Fabrication Defaults

- **Solder mask:** Green (default) — no upcharge. Red/blue/black/white cost more.
- **Lead time:** Standard is cheaper than expedited.
- **Surface finish:** ENIG costs more than HASL; use HASL if acceptable.

### Parts Already Basic

- **C49678** (100nF 0805): Used for C1–C6, C9, C10 — already basic.
- No further capacitor swaps needed unless changing footprints.

## References

- [JLCPCB: Basic vs Extended Parts](https://jlcpcb.com/help/answers/detail/578-How-to-identify-basic-and-extended-parts-in-JLCPCB-parts-library)
- [JLCPCB Assembly Pricing](https://jlcpcb.com/help/article/pcb-assembly-price)
- [Economic Parts List (Basic/Preferred Extended)](https://lrks.github.io/jlcpcb-economic-parts/active.html)

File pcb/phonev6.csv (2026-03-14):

Id | Designator | Footprint | Quantity | Designation | Supplier and ref
1 | A1 | Arduino_Micro_Socket | 1 | Arduino_Micro_Socket (keypad)
2 | A2 | Arduino_Micro_Socket | 1 | Arduino_Micro_Socket (display)
3 | A3 | ADA3708_RPI-ZERO | 1 | ADA3708 (Raspberry Pi Zero WH)
4 | U1 | XL6009_module | 1 | XL6009 boost converter (12V for coin validator)
5 | U2 | DIP-8_W7.62mm | 1 | TDA2822M dual audio amplifier
6 | R1,R2 | Resistor_SMD:R_0805_2012Metric | 2 | 4.7k (C17673 JLCPCB basic) | C17673
7 | C7 | CP_Radial_D5.0mm_P2.00mm | 1 | 100uF 16V (TDA2822 ch A output coupling)
8 | C11 | CP_Radial_D5.0mm_P2.00mm | 1 | 100uF 16V (TDA2822 ch B output coupling)
9 | C6 | C_Disc_D5.0mm_W2.5mm_P5.00mm | 1 | 100nF (TDA2822 ch A input coupling) | C49678
10 | C9 | C_Disc_D5.0mm_W2.5mm_P5.00mm | 1 | 100nF (TDA2822 ch B input coupling) | C49678
11 | C12 | CP_Radial_D5.0mm_P2.00mm | 1 | 100uF 16V (TDA2822 Vcc bypass)
12 | C8 | CP_Radial_D5.0mm_P2.00mm | 1 | 4.7uF (TDA2822 ripple rejection)
13 | C10 | C_Disc_D5.0mm_W2.5mm_P5.00mm | 1 | 100nF (TDA2822 Vcc decoupling) | C49678
14 | C1,C2,C3,C4,C5 | C_Disc_D5.0mm_W2.5mm_P5.00mm | 5 | 100nF decoupling (THT) | C49678
15 | D1,D2,D3 | D_DO-201AD_P12.70mm_Horizontal | 3 | P6KE6.8CA (600W bidirectional TVS, signal-to-GND, THT DO-201AD)
16 | Q1 | Package_TO_SOT_SMD:SOT-23 | 1 | AO3401A P-ch MOSFET (reverse polarity, SOT-23, C15127 JLCPCB basic) | C15127
17 | F1 | footprints:Fuse_Radial_D10.0mm_P5.00mm | 1 | 1A PTC resettable fuse (radial THT, pin-compatible with CP_Radial_D10mm_P5mm)
18 | D4 | LED_SMD:LED_0603_1608Metric | 1 | Red power LED (0603, C2286 JLCPCB basic) | C2286
19 | R3 | Resistor_SMD:R_0805_2012Metric | 1 | 1k LED current limit (C17513 JLCPCB basic) | C17513
20 | R4,R5 | Resistor_SMD:R_0805_2012Metric | 2 | 1k Pi GPIO to Arduino reset (C17513 JLCPCB basic) | C17513
21 | J1 | IDC-Header_2x05_P2.54mm_Vertical | 1 | coin
22 | J2 | IDC-Header_2x10_P2.54mm_Vertical | 1 | keypad
23 | J3 | IDC-Header_2x13_P2.54mm_Vertical | 1 | display
24 | J4 | RJ9_Evercom_5301-440xxx_Horizontal | 1 | RJ9 (handset)
25 | J5 | AUDIO-TH_HOOYA_PJ-320 | 1 | mic
26 | J6 | IDC-Header_2x07_P2.54mm_Vertical | 1 | card_reader
27 | J7 | AUDIO-TH_HOOYA_PJ-320 | 1 | speaker
28 | TP1,TP2,TP3,TP4,TP5 | TestPoint_Loop_D2.50mm_Drill1.0mm | 5 | Test points THT (5V_MAIN, Pi 3.3V, GND, SDA, SCL)

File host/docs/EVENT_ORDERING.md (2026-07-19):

# Event Ordering and Idempotency (#100)

Events are processed asynchronously: the PJSIP (PJSUA worker) thread queues call-state events to the main loop, while hook/coin/keypad events come from the serial/Arduino. Order is not guaranteed when multiple events occur close together.

## Hook + Call State Race

**Scenario**: User hangs up (hook_down) at roughly the same time the remote party hangs up (CALL_CLOSED → EVENT_CALL_STATE_INVALID).

### Order 1: Hook first, then INVALID

1. `handle_hook_event(hook_down)`: Transitions to IDLE_DOWN, clears keypad/coins, calls `millennium_client_hangup`, sends coin-validator commands.
2. `handle_call_state_event(INVALID)`: `current_state` is already IDLE_DOWN. Condition `current_state == CALL_ACTIVE || current_state == CALL_INCOMING` is false → **no action**. PJSIP tolerates a second hangup if one was already sent.

### Order 2: INVALID first, then hook

1. `handle_call_state_event(INVALID)`: Transitions to IDLE_UP, clears keypad/coins, calls `millennium_client_hangup`, sends coin-validator commands.
2. `handle_hook_event(hook_down)`: Transitions to IDLE_DOWN again, clears keypad/coins (already clear), sends hangup and coin-validator commands again. **Idempotent** — redundant but safe.

### Idempotency

- **INVALID handler**: Only acts when `current_state` is CALL_ACTIVE or CALL_INCOMING. If already IDLE (from prior hook_down), does nothing.
- **Hook-down handler**: Always transitions to IDLE_DOWN and clears state. Safe to run multiple times.
- **Double-hangup**: PJSIP tolerates (`pjsua_call_hangup` on an already-closed call is a no-op). Coin-validator commands (`c`, `z`) sent twice are assumed harmless.

## Testing

Scenario tests `test_remote_hangup.scenario` and `test_incoming_handset_up.scenario` cover call-state transitions.

## Model checking (`make tla-check`)

The idempotency argument above is a hand analysis of two orderings of two events. `tests/EventOrdering.tla` discharges it mechanically over *all* interleavings of every event type, across the two producers that actually race: the serial/Arduino path and the PJSUA worker thread, feeding the single-consumer main loop.

The model separates `hook` (the *physical* handset position) from `state` (the daemon's *belief*). The daemon's five-state enum conflates the two, so they can silently disagree — and that disagreement is only statable as an invariant once they are distinct variables.

**Verified (`make tla-check`, 3389 states):** under every interleaving, not just the two above — no reachable `INVALID`, balance stays non-negative, `IDLE_DOWN` always implies zero credit, and once the queue drains the daemon never sits in `CALL_ACTIVE` on-hook (`SettledNotActiveOnHook`) and its belief agrees with the physical handset (`Converged`).

**Confirms the analysis above:** the hook-down vs. `CALL_INVALID` race really is idempotent; both orders settle in `IDLE_DOWN`. The intermediate `IDLE_UP` in Order 2 is a genuine transient.

### Finding: the daemon could not tell an on-hook ring from an off-hook one

The first run of this spec produced three violations with a **single structural
root cause**, not a missing guard.

`daemon_state_data_t` had no field for the handset position, so the daemon
*inferred* it from `current_state` — and that inference is unsound, because
`CALL_INCOMING` is reachable both on-hook (a phone ringing in its cradle) and
off-hook (#92 interrupt dialing). No test on `current_state` can distinguish
them, so no guard placed there could be correct. Two intermediate attempts at a
`current_state` guard were both refuted by TLC before this became clear.

| Invariant | Failing behaviour |
|---|---|
| `SettledNotActiveOnHook` | A `CALL_ESTABLISHED` dispatched after the user hung up left the phone parked in `CALL_ACTIVE` with the handset cradled, with nothing left in the queue to recover it. |
| `Converged` | `CALL_INVALID` ending an unanswered on-hook ring dropped to `IDLE_UP` (`daemon.c:407`, `:411`), leaving the daemon believing the handset was lifted while it sat in the cradle. |
| `ActiveImpliesOffHook` | The instantaneous version of the first — see "By design" below. |

**Fix applied.** `daemon_state_data_t` gained an explicit `handset_up` field,
recorded in `handle_hook_event` from the physical hook direction. The
`EVENT_CALL_STATE_ACTIVE` arm now guards on it, and both `EVENT_CALL_STATE_INVALID`
arms return to `IDLE_DOWN` or `IDLE_UP` to match it. Mirrored in `simulator.c`
and `tests/cbmc_state_machine.c`.

Two consequences worth knowing:

- **`handset_up` is not persisted.** The keypad firmware only emits hook
  *transitions*, never the position at boot, so a restart cannot observe it. It
  is derived from the restored `last_state` instead, which keeps the two
  self-consistent.
- **Six scenario assertions changed** in `test_call_duration_metrics`,
  `test_failed_call_metrics`, and `test_missed_call_metrics`. Each was a
  `call_ended` with no preceding `hook_up`, asserting `IDLE_UP`. They were
  encoding the bug: the handset was never lifted, so `IDLE_DOWN` is correct.

### By design: `ActiveImpliesOffHook` (`make tla-check-race`)

The *instantaneous* property — never `CALL_ACTIVE` while the handset is
physically cradled, at every moment — cannot hold in an event-queue
architecture, and its violation is not a defect. The handset moves, the firmware
queues a hook event, and until the main loop dispatches it the daemon has not
yet learned. Every queued-event design has this window.

What is verified is that the window always **closes**: `SettledNotActiveOnHook`
and `Converged` both hold once the queue drains. Closing the instantaneous
window would require the firmware to report hook position synchronously — a
hardware change, not a daemon one.

### How the three tools divide the work

`make state-check` (CBMC) proves the **inductive step**: given a consistent
state, one transition preserves consistency — and that `simulator.c` and
`daemon.c` agree, now including `handset_up`. It cannot express two events in
flight.

`make tla-check` (TLC) proves the **reachability** half: no interleaving of
queued events can reach an inconsistent state to begin with. Neither tool covers
both halves alone, which is why the `CALL_ACTIVE` bug survived until now — CBMC
transcribed the unguarded arm faithfully and asserted nothing about it.

## Related: lock-order verification (`make lock-check`)

`tests/LockOrder.tla` model-checks the mutex acquisition graph for circular
wait, as a follow-up to #231. The full lock order is documented at
`daemon.c:59`.

Three things about it are worth knowing:

**The edge set was extracted, not remembered.** `tests/extract_lock_edges.py`
walks the source tracking lock/unlock nesting and takes the transitive closure
over the call graph. It found two edges the original #231 comment had missed —
`daemon_state_mutex -> plugins_mutex` (via `daemon_broadcast_state` calling
`plugins_get_active_name`) and `daemon_state_mutex -> logger_mutex`.

**Static analysis cannot see through function pointers.** The
`g_monitor_mutex -> daemon_state_mutex` edge runs through a registered health
check callback and had to be found by reading. The script says so in its own
docstring; treat its "no cycle" as necessary, not sufficient.

**`make lock-check-mutant` is what makes `make lock-check` mean anything.** It
reverses one edge and must report a violation. The first version of this spec
relied on TLC's built-in deadlock detection, which only flags a *global* stall
— and reported "no error" even on the deliberately-cycled model, because two
threads deadlocking while three keep running is not a global stall. The spec
now states circular wait directly as a waits-for cycle.

## Auditing the specs themselves (`make mutation-audit`)

A green TLC run is not evidence that a property is doing anything. Twice while
writing these specs a property passed for a reason unrelated to the system:

- `LockOrder.tla` relied on TLC's built-in deadlock detection, which flags only
  a state with *no successor*. A lock-order bug does not produce one — two
  threads deadlock while others keep running — so it reported "no error" on a
  deliberately-cycled version of itself.
- `Updater.tla`'s `RestartOk` both assigned `callDropped'` and listed it in
  `UNCHANGED`. That contradiction silently disabled the action whenever a call
  was up, so the guard under test was never exercised.

Both were caught by accident. `tests/mutation_audit.sh` makes it systematic:
for each property, break the system in the way that property is meant to notice
and confirm it fires. Anything reported `NOT CAUGHT` is vacuous or subsumed, and
its green result means nothing.

The audit also identified three properties that are **subsumed** and can never
be the invariant TLC reports — `NonNegative` in both specs (implied by
`TypeOK`'s `\in Nat`) and `NeverPromiseMoreThanHeld` (implied by
`LedgerAgreement`). They are kept for readability and now say so in place, so
nobody counts them as coverage.

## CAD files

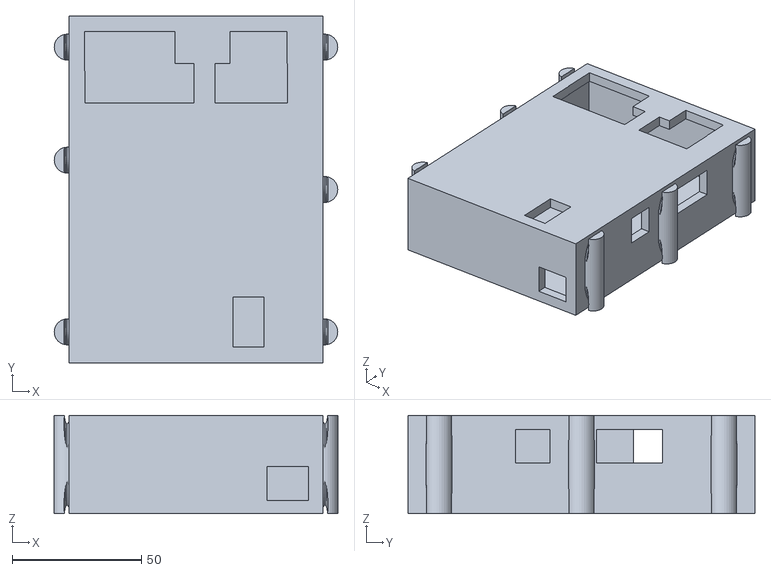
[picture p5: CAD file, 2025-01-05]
case/case.stl
109.5 x 134.0 x 38.0

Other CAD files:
case/case.blend

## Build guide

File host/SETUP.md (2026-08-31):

# Raspberry Pi Setup Guide

Step-by-step instructions for setting up the Millennium payphone daemon on a
Raspberry Pi Zero 2 W from a fresh Raspbian install.

## Prerequisites

- Raspberry Pi Zero 2 W with Raspbian 11 (Bullseye) or later
- SSH access to the Pi
- The custom PCB with both Arduinos flashed and the USB audio card connected
- A SIP account (e.g., from Twilio, VoIP.ms, or a local Asterisk server)

## 1. System packages

```bash
sudo apt update
sudo apt install build-essential git libasound2-dev libssl-dev cmake
```

## 2. User setup

The daemon runs as a system-wide systemd service. Add your user to the
`dialout` and `audio` groups (needed for serial ports and ALSA):

```bash
sudo usermod -aG dialout,audio $USER
```

Log out and back in for group changes to take effect.

## 3. Build PJSIP (pjproject — the VoIP stack)

The daemon embeds **PJSIP** via its PJSUA C API (`libpjproject`). Build it with
ALSA and TLS support:

```bash
cd ~
git clone https://github.com/pjsip/pjproject.git
cd pjproject
# A recent 2.x release; pin a tag you've tested, e.g.:
git checkout 2.15.1
./configure --enable-shared --disable-video \
            --with-ssl                # OpenSSL for TLS (Twilio needs it)
make dep && make -j$(nproc)
sudo make install
sudo ldconfig
```

Notes:
- `pkg-config --modversion libpjproject` should now succeed (the daemon's
  Makefile uses `pkg-config --cflags/--libs libpjproject`).
- PJSIP auto-detects ALSA; G.711 (PCMU/PCMA) is built in, which is all Twilio
  needs. Opus is optional.
- If `pkg-config` can't find it, ensure `/usr/local/lib/pkgconfig` is on
  `PKG_CONFIG_PATH`.

Smoke-test the PJSIP integration before wiring up real credentials — this
brings PJSUA up and down without a SIP peer or the phone hardware:

```bash
make pjsip-smoke && ./pjsip_smoke   # expect "RESULT: PASS"
```

## 4. Configure the SIP account

There is **no separate accounts file** — SIP credentials live in
`/etc/millennium/daemon.conf` (`make install` copies `daemon.conf.example`).
Set:

```
sip.id_uri=sip:+1XXXXXXXXXX@your-provider.sip.example.com
sip.registrar=sip:your-provider.sip.example.com
sip.realm=*
sip.username=+1XXXXXXXXXX
sip.password=YOUR_PASSWORD
sip.transport=tls                 # Twilio requires TLS
sip.stun_server=stun.l.google.com:19302
```

Leave `sip.id_uri`/`sip.registrar` empty to run the phone as a games console
with VoIP disabled. Because credentials are read by the daemon itself, it no
longer needs to run as a particular user or own a `~/.baresip` directory.

### Audio routing

The handset audio is split by the TDA2822M (left = ringer, right = earpiece).
The daemon's own tone generator (`audio_tones.c`) drives the ringer/dial/busy
tones on the left channel; PJSIP only carries the live **call** audio. Route
PJSIP's mono call audio to the earpiece via `/etc/asound.conf` (installed from
`asoundrc.example`) so the ALSA `default` device maps capture to the mic and
playback to the right channel. If needed, pin specific device IDs with
`sip.snd_capture_dev` / `sip.snd_playback_dev` (the daemon logs available
device IDs at startup).

## 5. Clone and build the daemon

```bash
cd ~
git clone https://github.com/kmatzen/millennium.git
cd millennium/host
make daemon
```

## 6. ALSA audio configuration

The USB audio card needs a custom ALSA config to split stereo into independent
mono channels for the handset earpiece and ringer speaker. From the `host/`
directory (where you just ran `make daemon`):

```bash
sudo cp asoundrc.example /etc/asound.conf
```

Verify the USB audio card is detected as card 1:

```bash
aplay -l
```

If it shows up as a different card number, edit `/etc/asound.conf` and change
`"hw:1,0"` to match.

Test audio output:

```bash
speaker-test -D out_left_solo -c1 -twav   # should play through ringer
speaker-test -D out_right_solo -c1 -twav  # should play through handset
```

## 7. Configure the daemon

```bash
sudo mkdir -p /etc/millennium
sudo cp daemon.conf.example /etc/millennium/daemon.conf
```

Edit `/etc/millennium/daemon.conf`. The key settings to verify:

```
hardware.display_device=/dev/serial/by-id/usb-Arduino_LLC_Millennium_Beta-if00
hardware.baud_rate=9600
call.cost_cents=50
call.timeout_seconds=300
web_server.enabled=true
web_server.port=80
```

The `hardware.display_device` path depends on the Arduino's USB product name.
With the custom board definitions flashed, the display Arduino appears as
`Millennium_Beta`. Verify with:

```bash
ls /dev/serial/by-id/
```

## 8. Create the log and state directories

```bash
sudo mkdir -p /var/log/millennium
sudo chown $USER:$USER /var/log/millennium
sudo mkdir -p /var/lib/millennium
sudo chown $USER:$USER /var/lib/millennium
```

## 9. Install the systemd service

**Production** (recommended): Use `make install` for a system-wide service that
starts at boot:

```bash
cd ~/millennium/host
make install
```

This installs the daemon to `/usr/local/bin/millennium-daemon`, creates
`/etc/systemd/system/daemon.service` (with a user override), copies
`daemon.conf.example` to `/etc/millennium/daemon.conf`, and starts the service.
Check status:

```bash
sudo systemctl status daemon.service
```

**Development** (running from repo, no `make install`): Use the dev service:

```bash
mkdir -p ~/.config/systemd/user
cp systemd/daemon-dev.service ~/.config/systemd/user/daemon.service
systemctl --user daemon-reload
systemctl --user enable daemon.service
systemctl --user start daemon.service
```

Ensure `/etc/millennium/daemon.conf` exists: `sudo cp daemon.conf.example /etc/millennium/daemon.conf`.

The web dashboard should now be accessible at `http://<pi-ip>:80`.

## 10. Disable unused services (optional cleanup)

If you previously had PipeWire/WirePlumber installed, mask the leftover services:

```bash
systemctl --user mask pipewire.service
systemctl --user mask wireplumber.service
systemctl --user disable remap-sink.service
systemctl --user disable filter-chain.service
systemctl --user disable audio-mux.service
```

## Verifying the setup

1. **Serial connection**: The daemon log should show "Serial port opened" on
   startup. If not, check the `display_device` path and that the Arduino is
   connected.

2. **VoIP registration**: Check the daemon log for SIP registration status.
   If registration fails, verify your `sip.*` credentials in
   `/etc/millennium/daemon.conf` and network connectivity.

3. **Audio**: Lift the handset and dial a number. You should hear dial tone
   through the handset earpiece. If no audio, verify the ALSA config and USB
   audio card detection.

4. **Web dashboard**: In production, open the authenticated maintenance domain
   provided by the Cloudflare tunnel. For local diagnosis on the Pi, use
   `http://127.0.0.1:8081`; the administrative listener is intentionally not
   reachable from the physical LAN.

5. **API integration test**: Run locally on the Pi or through the authenticated
   maintenance path:
   ```bash
   cd ~/millennium/host && make api-test
   # Or from another machine: HOST=<pi-ip> ./tests/api_test.sh
   ```

## Development-only source deployment

The following workflow is only for a developer-controlled lab phone. Never use
it to maintain an unattended production appliance:

```bash
cd ~/millennium/host
git pull
make clean && make daemon
sudo make install
```

Production phones accept only signed releases through the workflow in
`docs/UNATTENDED_APPLIANCE.md`. If using the development service
(`systemctl --user`), restart it with `systemctl --user restart daemon.service`.

## Troubleshooting

### Config, epoll, or state file errors

If you see:
- **Could not load config file** — Copy the config and ensure the path exists:
  ```bash
  sudo mkdir -p /etc/millennium
  sudo cp host/daemon.conf.example /etc/millennium/daemon.conf
  ```
  Update the systemd unit to use `--config /etc/millennium/daemon.conf`.

- **`pkg-config` can't find libpjproject** — Ensure PJSIP installed to
  `/usr/local` and `PKG_CONFIG_PATH=/usr/local/lib/pkgconfig`, then `sudo ldconfig`.
  Verify with `pkg-config --modversion libpjproject`.

- **Unit file daemon.service is masked** — Unmask before enabling: `sudo systemctl unmask daemon.service`, then run `make install` again.

- **No such file or directory** (for millennium-daemon) — You're running from the repo without `make install`. Use the dev service:
  ```bash
  cp systemd/daemon-dev.service ~/.config/systemd/user/daemon.service
  systemctl --user daemon-reload
  systemctl --user restart daemon.service
  ```

- **Failed to open state file for writing** — Create the state directory and make it writable:
  ```bash
  sudo mkdir -p /var/lib/millennium
  sudo chown $USER:$USER /var/lib/millennium
  ```
  Or set `MILLENNIUM_STATE_FILE=/home/$USER/.local/state/millennium` in the environment.

### Serial port not found

If the daemon log shows a serial open error:

1. Check the Arduino is connected: `ls /dev/serial/by-id/`
2. Verify your user is in the `dialout` group: `groups`
3. If the device path differs from the config, update `hardware.display_device`
   in `/etc/millennium/daemon.conf`

### No audio output

1. Verify the USB audio card is detected: `aplay -l`
2. Check the card number matches the ALSA config: look for `"hw:1,0"` in
   `/etc/asound.conf` and update if the card number differs
3. Test each channel independently:
   ```bash
   speaker-test -D out_left_solo -c1 -twav
   speaker-test -D out_right_solo -c1 -twav
   ```
4. Check ALSA mixer levels: `alsamixer -c 1`

### SIP registration fails

1. Check network connectivity: `ping -c3 8.8.8.8`
2. Verify the `sip.*` credentials in `/etc/millennium/daemon.conf`
3. Check the daemon log for PJSIP/SIP error messages:
   ```bash
   journalctl -u daemon.service --no-pager -n 100 | grep -iE 'reg|sip|403'
   ```
4. Check the web dashboard `/api/state` — it shows `sip_registered` (1=ok, -1=failed)
   and `sip_last_error` with the provider's message.
5. **Twilio 403 Forbidden**: Common causes:
   - Wrong `sip.username` or `sip.password` in `/etc/millennium/daemon.conf`
   - Credentials List username/password in Twilio Console don't match
   - SIP domain (e.g. `matzen-test.sip.twilio.com`) not set up or mismatched
   - Verify in Twilio Console → Voice → SIP Trunking → Credential List

### Daemon crashes or restarts repeatedly

1. Check the log for the crash reason:
   ```bash
   sudo journalctl -u daemon.service --no-pager -n 100
   ```
2. Check available disk space: `df -h` — the log file can grow if
   `logging.to_file=true`
3. Check memory: `free -h` — the Pi Zero 2 W has limited RAM

### VFD display shows garbage or nothing

1. Check the serial baud rate matches the config (should be 9600)
2. The Display Arduino may need a reset — unplug and replug the USB cable
3. Check I2C communication between the Arduinos:
   ```bash
   i2cdetect -y 1
   ```
   You should see address `08` (display Arduino) on the bus

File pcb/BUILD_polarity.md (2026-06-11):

# phonev6 — Hand-assembly polarity sheet

Auto-generated from the schematic. For each part, verify the **silkscreen polarity mark** (bar, dot, plus, beveled corner, pin-1 chamfer) lines up with the **net listed at the marked pin** before reflow / iron.

## electrolytic cap

| Ref | Value | Package | Pin | Function | Net |
|-----|---|---|-----|---|-----|
| `C7` | 100µF 16V | CP_Elec_6.3x5.4 | 1 | + (anode) | `5V_MAIN` |
|  | |  | 2 | − (cathode) | `GND` |
| `C11` | 100µF 16V | CP_Elec_6.3x5.4 | 1 | + (anode) | `Net-(U2-OUT1)` |
|  | |  | 2 | − (cathode) | `speaker_front+` |
| `C12` | 100µF 16V | CP_Elec_6.3x5.4 | 1 | + (anode) | `Net-(U2-OUT2)` |
|  | |  | 2 | − (cathode) | `speaker_receiver+` |

## LED

| Ref | Value | Package | Pin | Function | Net |
|-----|---|---|-----|---|-----|
| `D4` | Red LED | LED_0805_2012Metric | 1 | K  (cathode, marked) | `GND` |
|  | |  | 2 | A  (anode) | `Net-(D4-A)` |
| `D8` | Green LED | LED_0805_2012Metric | 1 | K  (cathode, marked) | `GND` |
|  | |  | 2 | A  (anode) | `LED_3V3` |
| `D9` | Green LED | LED_0805_2012Metric | 1 | K  (cathode, marked) | `GND` |
|  | |  | 2 | A  (anode) | `LED_12V` |
| `D10` | Yellow LED | LED_0805_2012Metric | 1 | K  (cathode, marked) | `RESET1` |
|  | |  | 2 | A  (anode) | `LED_RST1` |
| `D11` | Yellow LED | LED_0805_2012Metric | 1 | K  (cathode, marked) | `RESET2` |
|  | |  | 2 | A  (anode) | `LED_RST2` |
| `D12` | Blue LED | LED_0805_2012Metric | 1 | K  (cathode, marked) | `sda` |
|  | |  | 2 | A  (anode) | `LED_SDA` |
| `D13` | Blue LED | LED_0805_2012Metric | 1 | K  (cathode, marked) | `scl` |
|  | |  | 2 | A  (anode) | `LED_SCL` |

## MOSFET (SOT-23)

| Ref | Value | Package | Pin | Function | Net |
|-----|---|---|-----|---|-----|
| `Q1` | AO3401A | SOT-23 | 1 | G  (gate) | `GND` |
|  | |  | 2 | S  (source) | `Net-(Q1-S)` |
|  | |  | 3 | D  (drain) | `BOOST_IN+` |

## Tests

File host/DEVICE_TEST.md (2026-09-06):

# Device Testing

Run integration tests against the real Millennium payphone when it's connected
and the daemon is running.

## Finding the device

The Pi's address is **DHCP and has changed before** (e.g. `.145` → `.115` →
`.152`), so don't rely on a fixed IP. Prefer the mDNS hostname; fall back to the
router's DHCP table:

```bash
PI=raspberrypi.local            # mDNS hostname (can be flaky — fall back to an IP)
ping -c2 "$PI"                  # confirm it resolves and is up
# If it doesn't resolve, find the current IP on the LAN:
arp -a | grep -i 'b8:27\|dc:a6\|e4:5f\|d8:3a'   # Raspberry Pi OUIs
```

The daemon serves the HTTP API on **port 80**.

## Prerequisites

- Daemon running on the device (`ssh millennium@$PI 'sudo systemctl status daemon.service'`)
- Device reachable on the network (port 80 for the HTTP API)

## Run API Tests (from your machine)

```bash
make api-test HOST=raspberrypi.local      # or HOST=<pi-ip>
```

Or set the variable once:

```bash
export HOST=raspberrypi.local
make api-test
```

> `make device-test` defaults to `millennium-phone.local`; override it with
> `DEVICE_HOST=<hostname>` when testing another lab device.
> address — only use it if the Pi still happens to live there. Prefer
> `make api-test HOST=...` with the current address.

## Run API Tests (from the device)

SSH into the device and run locally (no networking flakiness):

```bash
ssh millennium@raspberrypi.local 'cd millennium/host && make api-test'
```

## Troubleshooting

If tests fail with "Cannot reach":

1. Check the daemon is running: `ssh millennium@$PI 'sudo systemctl status daemon.service'`
2. Verify port 80 is listening: `ssh millennium@$PI 'ss -tlnp | grep ":80 "'`
3. Confirm network connectivity: `curl -s http://$PI/api/health`
4. If `raspberrypi.local` doesn't resolve, the Pi may be powered off or on a new
   IP — find it via the router's DHCP table or the `arp -a` OUI grep above.

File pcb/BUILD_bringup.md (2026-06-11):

# phonev6 — bench bring-up checklist

Walk this top-to-bottom. **Do not skip stages** — each one catches a class of fault before the next stage exposes more expensive parts to it.

## Stage 0 — visual + polarity

- [ ] All solder joints reflowed cleanly; no bridges; no cold joints (loupe).
- [ ] **Polarity** of every electrolytic / LED / SOT-23 / diode matches `BUILD_polarity.md` (silkscreen mark ↔ schematic net at marked pin).
- [ ] Run `make verify` — netlist sync, pinouts, footprints, ERC, DRC all green.

## Stage 1 — bare board, no power, no ICs populated

Use a DMM in resistance / continuity mode. **Do not install the Pi or Arduinos yet.** With the board on the bench, GND clip on TP3:

- [ ] `5V_MAIN` ↔ `GND`: ≥ ~1 kΩ (no short). Probe: TP1.
- [ ] `BOOST_IN+` ↔ `GND`: ≥ ~1 kΩ (no short). Probe: (probe at any cap pin on this net).
- [ ] `12V_COIN` ↔ `GND`: ≥ ~1 kΩ (no short). Probe: (probe at any cap pin on this net).
- [ ] `3.3V` ↔ `GND`: ≥ ~1 kΩ (no short). Probe: TP2.
- [ ] Audio outputs `speaker_front+` ↔ `GND` and `speaker_receiver+` ↔ `GND`: should read open / high (the output coupling caps look like an open in DC).

If anything reads a hard short, **stop** and find it (look for solder bridges under SOIC pins, polarized parts in wrong, TVS shorted).

## Stage 2 — first power-on, current-limited, ICs still out

Bench supply: **5 V at 200 mA limit**. Power leads only into the 5 V input. Pi and Arduinos still **out of their sockets**.

- [ ] Power-on current draw: a few mA (just the LEDs + leakage). Supply does **not** hit the current limit.
- [ ] **F1** does not trip (no flashing red on the supply).
- [ ] **D4** (red power LED) lights.
- [ ] Voltage at `5V_MAIN` ≈ 5.0 V. Probe: TP1.
- [ ] Voltage at `BOOST_IN+` ≈ 5 V (≈ V_in − Q1 R_DS_on × I; should be well within ~50 mV of `5V_MAIN`). If `BOOST_IN+` is near 0 V, Q1 is backwards or the gate is floating.
- [ ] **D9** (green 12 V LED) lights ⇒ XL6009 is switching.
- [ ] `12V_COIN` ≈ 12 V (trim the XL6009 module's pot if not). Probe at any cap on this net (e.g. C17/C18).

## Stage 3 — populate the Pi (A3), bump current limit

Power **off**. Plug the Pi into its socket. Raise supply limit to ~1.5 A.

- [ ] Power on. Total current ≤ ~500 mA at idle on the Zero 2 W.
- [ ] **D8** (green 3.3 V LED) lights.
- [ ] Voltage at `3.3V` ≈ 3.3 V. Probe: TP2.
- [ ] Pi boots normally (activity LED blinking after a few seconds; SSH becomes reachable on the network).

## Stage 4 — populate Arduinos (A1 keypad, A2 display)

Power off. Plug in the two Arduino Micros.

- [ ] Power on. Total current increases by ~50 mA × 2 (Arduino idle).
- [ ] Flash both via the **`deploy-arduino`** workflow (`make deploy_keypad`, `make deploy_display`).
- [ ] **D10 / D11** (yellow `RESET1` / `RESET2` LEDs) **flash briefly** during the GPIO reset pulse — visible during the deploy. If they don't flash, the Pi GPIO isn't toggling the reset line.
- [ ] **D12 / D13** (blue `SDA` / `SCL`) flicker once the daemon runs I2C between Alpha and Beta. At idle they're off (lines pulled high); during traffic they twitch.

## Stage 5 — verify the audio amp (U2)

With everything powered, **no audio signal** yet:

- [ ] DC voltage at **U2 pin 2 (Vcc)** ≈ 5.0 V.
- [ ] DC voltage at **U2 pin 4 (GND)** ≈ 0 V (solid ground).
- [ ] DC voltage at **U2 pin 1 (OUT1)** and **pin 3 (OUT2)** ≈ ½·Vcc (~2.5 V). If either output sits near 0 V or near 5 V, the bias is broken — most likely the NF cap (C13 on pin 8, C14 on pin 5) is missing / reversed / cold-jointed.
- [ ] DC voltage at **pin 8 (NF1)** and **pin 5 (NF2)** ≈ ½·Vcc, stable. AC ripple here ⇒ bad / wrong NF cap.

Now apply a tone (Pi-side, after the daemon is up):

```bash
speaker-test -D out_left_solo  -t sine -f 1000   # ringer channel (OUT1)
speaker-test -D out_right_solo -t sine -f 1000   # earpiece channel (OUT2)
```

- [ ] Scope on **U2 pin 1 / pin 3** shows a clean sine, no clipping at moderate volume.
- [ ] Scope on `speaker_front+` / `speaker_receiver+` (after the 100 µF output cap) shows AC sine centred on 0 V into the speaker load.
- [ ] Scope on **`5V_MAIN`** AC-coupled while a loud tone plays: ripple ≪ 100 mV. Heavy ripple means insufficient bulk decoupling or boost noise.

## Stage 6 — functional end-to-end

- [ ] Lift / replace handset: hook events arrive at the daemon (`journalctl -u daemon.service -f` shows `HU` / `HD`).
- [ ] Keypad: pressing keys logs `K<char>` events.
- [ ] Coin: drop a known coin, verify a `V<byte>` event with the expected value.
- [ ] Magstripe: swipe a card, daemon logs `C<PAN>`.
- [ ] Place a test call (matches the **`phone-status`** skill: `curl -s http://<pi>:8081/api/state` should show `sip_registered:1`).

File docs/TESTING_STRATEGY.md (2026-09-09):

# Testing and release strategy

The default decision is **reject the image**. A release is eligible for a
single, planned hardware acceptance session only after all automated gates
below pass for the same full source commit and the exact image that will be
written. Passing QEMU is never recorded as passing physical hardware.

## Coverage model

`acceptance/inventory.json` is generated from every shipped executable,
systemd unit, API and Wi-Fi route, updater state, maintenance action, plugin,
experience event, MCU message and recovery tool. `acceptance/coverage.json`
assigns every inventory item to an owner, executable suites, fault classes,
fidelity levels and any irreducible physical gate. CI rejects stale or unowned
inventory and missing profiles.

For every production path, test the success path, rejection path, restart
path, interruption boundary, retry limit, rollback or fail-closed behavior,
and evidence/privacy behavior where applicable. A source-only assertion is not
sufficient for an installed permission, identity, mount, firewall, service
ordering or packaging contract.

## Automated layers

1. **Static and contract tests** validate generated metadata, image contents,
   unit sandboxing, filesystem modes, configuration, schemas, parsers, release
   signatures, inventory ownership and evidence validators.
2. **Host unit and process tests** execute daemon, SIP, audio, web, story,
   Wi-Fi, OTA and recovery logic with deterministic clocks and fault injection.
   GCC, Clang, ASan and UBSan cover independent compiler and memory-safety
   failure modes; formal parser and state-machine checks remain CI gates.
3. **Peripheral co-simulation** preserves Alpha-to-I2C-to-Beta-to-USB routing
   and injects corrupt, duplicated, delayed, missing and reset traffic instead
   of directly mutating daemon state.
4. **Outside-in ARM64 QEMU** runs on `anima`. It exercises real systemd users,
   services and sockets; independent captive-portal and update clients; TLS
   origins; maintenance SSH; resource exhaustion; network loss; abrupt power
   cuts; every update journal boundary; quarantine; rollback and recovery.
5. **Exact-image QEMU** boots a disposable overlay of the factory-seeded image.
   It validates the assembled partitions, persistent mounts, read-only system
   assumptions, service accounts, runtime directory traversal, firewall,
   NetworkManager policy and early boot graph. The generic guest is useful for
   breadth but cannot satisfy this gate.
6. **Evidence coherence** binds local and QEMU results to one full source
   commit, requires every named scenario, requires an exact-image pass, and
   rejects any automated evidence that claims physical fidelity.

## Required automated release procedure

Run local coverage from a clean checkout and retain its JSON result:

```sh
python3 tools/generate_coverage_inventory.py --check
python3 tools/coverage_ledger.py validate
python3 tools/coverage_ledger.py run-automated --suite host --suite contracts \
  --evidence /path/to/local-evidence.json
```

Build and factory-seed the candidate on `anima`, then run the entire QEMU lab
with all three `MILLENNIUM_QEMU_EXACT_*` inputs set to that candidate image and
its transport kernel/initrd. Preserve both `full-test-result.json` and the
copied `exact-image-result.json` from the same artifact directory.

Finally produce the automated verdict:

```sh
python3 tools/release_gate.py \
  --local /path/to/local-evidence.json \
  --qemu /path/to/full-test-result.json \
  --exact /path/to/exact-image-result.json
```

Any missing, stale, generic-guest-only, incomplete or failed evidence rejects
the release. Fixes found by a gate require a new commit, new image, and complete
rerun; results from the predecessor cannot be carried forward.

## Physical-only residuals

Only physics and human-perception claims remain outside automation: Zero 2 W
firmware/tryboot selection, SD electrical behavior, real RF association and
native captive detectors, USB enumeration, MCU instruction timing, acoustic
quality, control voltages, brownouts, external-network provenance, and a
first-time owner's comprehension. Their exact procedures and GitHub issues are
generated by:

```sh
python3 tools/coverage_ledger.py physical-plan
```

These are run once, in the documented order, only after the automated release
verdict accepts the candidate. A physical failure rejects the image, becomes a
regression test at the highest feasible installed-image fidelity, and restarts
the automated procedure from a new commit.

## Regression rule

Every escaped defect must add a test that fails on the rejected artifact and
passes on the correction. The test must reproduce the boundary that failed.
For example, the captive portal permission defect is checked both by starting
the deployed Wi-Fi services and connecting to the broker as the real
`millennium-wifi` user, and by asserting the effective runtime-directory owner,
group and traversal permission while booting the exact production image.

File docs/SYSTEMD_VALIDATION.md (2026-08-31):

# Systemd validation evidence

The production units were validated on 2026-08-31 using systemd 255
(`255.4-1ubuntu8.17`) on the Linux host `anima`.

```text
systemd-analyze verify host/systemd/*.service host/systemd/*.timer
```

No project unit produced an unknown-directive, invalid-value, dependency-cycle,
or calendar error. The isolated host did report expected deployment-context
warnings for executables that are installed only on the phone, plus unrelated
warnings from units already installed on `anima`; neither is a project unit
syntax failure.

The daemon sandbox was also analyzed offline after applying the same `User=`
override generated by `make install`:

```text
systemd-analyze security --offline=yes --threshold=5 daemon-merged.service
Overall exposure level for daemon-merged.service: 4.4 OK :-)
```

The release pipeline repeats `systemd-analyze verify` on Ubuntu. Any future
change to a production unit must retain an exposure score below 5.0 and must not
introduce a project-unit verification diagnostic.

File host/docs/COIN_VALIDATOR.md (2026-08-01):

# Coin Validator Commands (#110)

The daemon sends 1-byte commands to the Mars/MEI TRC-6500 coin validator via the Arduino display firmware (I2C → CMD_COIN_CTRL → UART to validator).

## Observed Usage

| Byte | Context | Purpose |
|---|---|---|
| `'a'` (0x61) | Hook up → IDLE_UP | Enable/accept coins |
| `'c'` (0x63) | Hook down, remote hangup, call ended | Cancel/reject coins |
| `'f'` (0x66) | Serial reconnect, call incoming | Re-init / enable validator |
| `'z'` (0x7a) | After `'c'` or `'f'` | Commit/execute (sequence terminator?) |

Note `'a'` travels alone — `daemon.c` sends no `'z'` after it. Only `'c'` and `'f'` are terminated.

## Serial Reconnect (#110, #239)

When the serial link recovers (`open_serial_port` succeeds), the SDK restores the
gate to whatever state the daemon last asked for, replaying that call site's exact
byte sequence. This mirrors how the same reconnect path re-sends the last display
contents (see `SERIAL_DISCONNECT_RECOVERY.md`).

The gate state is tracked in `client->coin_gate_cmd`, updated on every
`millennium_client_write_to_coin_validator` call; the replay decision lives in
`coin_gate.c` and is unit-tested:

| Tracked gate | Replayed on reconnect |
|---|---|
| `'a'` (handset up) | `'a'` |
| `'c'` (handset down) | `'c'` `'z'` |
| `'f'` (call incoming) | `'f'` `'z'` |
| nothing yet | `'c'` `'z'` |

Untracked defaults to reject, which is the fail-safe direction: an armed validator
with the handset on the hook physically swallows a coin that `handle_coin_event`
then refuses to credit, because it only credits in `IDLE_UP`.

**Previously (#239)**: this path sent a bare `'f'` unconditionally. That both
dropped the `'z'` every other `'f'` call site pairs with — so the re-init may never
have committed — and armed the validator regardless of hook state. Replaying the
tracked gate fixes both without introducing any byte sequence the daemon does not
already send elsewhere, so it needs no new assumption about what the TRC-6500 does
with an unterminated `'f'`.

**Still open**: whether `'z'` really is a commit/terminator is unconfirmed against
the hardware; the table above just preserves each call site's existing pairing.

**Risk (unchanged)**: a coin mid-accept or mid-reject when the link dropped is
still unaccounted for.

**Mitigation (future)**: a non-blocking delay (e.g. 2 s) before the replay would
let in-progress coins settle. Would require storing the reconnect timestamp and
replaying on a later `check_serial` call.

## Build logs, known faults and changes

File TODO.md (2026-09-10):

# Millennium Phone TODO

This list captures the work required to make the phone safe and maintainable
as an unattended appliance. Items are ordered by priority.

Continuation status, exact next actions, test commands, external artifact
locations, and evidence boundaries are recorded in `HANDOFF.md`. Read it before
starting a broad "address all items" pass.

The remaining physical and human acceptance work is sequenced in
`hardware/as-built/phone-001/NEXT_PHYSICAL_SESSION.md` so it can be completed
with one assembled-hardware session and without repeating the network wiring.

## P0 — Required before handoff

- [ ] Add owner-friendly Wi-Fi onboarding and recovery.
  - [x] On first boot with no configured network, create a temporary
    `Millennium-Setup-<device-id>` WPA2 access point and captive portal.
  - [x] Generate a unique per-device setup password at provisioning time and
    print the SSID, password, and portal URL as a QR code in the owner packet.
    Never use a fleet-wide password.
  - [x] Let the owner scan for nearby networks, enter credentials over the
    local setup link, and see clear connecting/success/failure feedback.
  - [x] Store Wi-Fi credentials only in root-owned NetworkManager connection
    profiles; never log, back up, export, or expose them to the daemon.
  - [x] Validate and escape SSIDs and passphrases without invoking a shell.
    Support spaces, Unicode, hidden SSIDs, WPA2/WPA3 transition networks, and
    open networks only after an explicit warning.
  - [x] Shut down the setup AP after a verified station connection, restart
    OTA and maintenance services, and confirm the phone reaches its update and
    maintenance endpoints.
  - [x] Provide a protected physical recovery gesture that reopens setup for
    15 minutes without erasing the existing network; never enter setup merely
    because Internet access is temporarily unavailable.
  - [x] Isolate setup mode with firewall rules: permit only DHCP, DNS, and the
    portal from the setup interface; block SSH, the admin API, forwarding, and
    access to stored credentials.
  - [x] Add attempt throttling, a visible setup-mode indicator, a hard timeout,
    and automatic rollback to the previous working network after failure.
  - [ ] Test wrong passwords, hidden networks, power loss during save, radio
    failure, captive-portal detection on iOS/Android/macOS/Windows, and recovery
    with local console access before enabling it on a deployed phone.
    - [x] Automated fault tests cover wrong credentials, hidden profiles,
      atomic-save interruption, radio errors, and platform probe routes.
    - [x] Export privacy-preserving physical-client evidence only after the
      browser family matches a recently observed native captive probe.
    - [ ] Repeat the matrix with physical radios, each named client platform,
      and a local console on the production phone.
  - Done when a first-time owner can connect the phone to a new home network
    from a mobile browser without maintainer help, while an untrusted setup
    client cannot reach administrative services or recover stored credentials.

- [ ] Add fail-safe full operating-system OTA updates.
  - [x] Build a supported NetworkManager-based Raspberry Pi OS image for the
    Zero 2 W with redundant boot/root slots and a separate persistent-data
    partition; do not repartition the deployed Bullseye system in place.
  - [x] Use the Raspberry Pi firmware's one-shot `tryboot` A/B mechanism so an
    uncommitted image automatically falls back after a failed or interrupted
    boot without requiring network access.
  - [x] Authenticate the OS image manifest and every compressed and expanded
    boot/root payload; bind model, partition layout, source commit,
    monotonically increasing sequence, minimum compatible application/MCU
    versions, rollout controls, and exact sizes and hashes into the signature.
  - [x] Stream verified images only to inactive slots, read them back, and
    reject overlap with the active boot/root devices before changing boot state.
  - [x] Preserve per-device identity, NetworkManager profiles, setup secret,
    maintenance credentials, story state, logs required for diagnosis, and OTA
    anti-rollback state outside the replaceable root filesystems.
    - [x] Make the image-owned shared-state generator link every declared mount
      into `local-fs.target`, and regression-test the generated dependencies.
    - [x] Reject non-canonical machine IDs and provision the daemon token with
      the exact ownership and group-readable mode required at runtime.
    - [ ] On the rebuilt physical image, prove `/` is read-only and every
      declared `/etc`, `/var`, and identity path is writable from partition 7
      before accepting daemon, Wi-Fi, SSH, or OTA health.
  - [ ] Commit the new boot slot only after bounded checks prove the daemon,
    both MCUs, audio, SIP, local controls, update endpoint, and maintenance
    tunnel are healthy; otherwise record failure and return to the prior slot.
    - [x] Implement and software-verify the bounded gate, including an actual
      ALSA PCM write, fresh independent Alpha/Beta diagnostics, named daemon
      health, and reverse-tunnel stability beyond its SSH failure window.
    - [ ] Boot the signed candidate on the production-equivalent Zero 2 W and
      prove a healthy physical candidate commits while each failed gate returns
      to the prior slot.
  - [ ] Rate-limit and quarantine failed OS images, respect calls and
    maintenance windows, expose owner-safe status, and retain a signed recovery
    image that can be written by a maintainer.
    - [x] Implement digest-scoped exponential backoff, bounded retry quarantine,
      busy-device and maintenance-window gates, administrative clearing, and
      privacy-safe owner status.
    - [x] Produce, sign, and retain a software-verified production-equivalent
      recovery image, with its exact compressed and expanded hashes bound to
      the active release key. Keep it explicitly unapproved until physical boot.
    - [x] Preserve completed write/readback evidence for rejected predecessor
      images without treating it as acceptance of the current candidate.
    - [x] Write the current `6f50d12` retained image to OS-identified dedicated
      removable recovery media and verify its full image-length readback against
      the signed expanded digest.
    - [x] Retain the rejected `c9b01fb` media after physical testing exposed
      AP-to-owner activation timing and portal-lifetime defects.
    - [x] Build, sign, fully simulate, write, and read back the corrected
      `d895b35` replacement; physical testing rejected it after measuring an
      AP-to-station transition longer than its retry window.
    - [x] Rebuild from `b496081` or later with the measured physical handoff
      bound, then sign, fully simulate, and write/read back the `98e018a`
      replacement.
    - [x] Rebuild from `6dad08e` or later after physical testing found an
      activated-but-not-beaconing setup AP; require recovery to cycle the AP
      before physical acceptance.
      - [x] The signed `4a15bf6` replacement passed the exact-image and full
        QEMU gates, including the forced AP down/up recovery path, and is
        independently verified on `anima` and external `UEBuild`.
      - [x] Retain `4a15bf6` as rejected physical evidence after its daemon
        failed with `203/EXEC`: `/opt/millennium` was `root:root 0750`, so the
        `millennium` service user could not traverse the installed path.
      - [x] Correct the exact-image false positive, execute the production
        daemon as its service user, reject `203/EXEC`, test both system slots,
        normalize `/opt/millennium` to `root:root 0755`, and rebuild, sign, and
        fully simulate the `1f63772` replacement without claiming physical
        hardware fidelity.
      - [x] Write the signed `1f63772` package to OS-identified 63.9 GB
        removable recovery media, verify the complete 15,636,365,312-byte
        readback against the signed expanded digest, and safely eject it.
    - [ ] Boot a non-quarantined verified recovery image on the
      production-equivalent Zero 2 W; the physically booted v3, `2ad5179`,
      `7f94bdd`, `6f50d12`, `c9b01fb`, `d895b35`, `98e018a`, and `4a15bf6` artifacts are
      retained as failed evidence and must not be redeployed.
  - [ ] Exercise download, inactive-slot write, pre-reboot, first boot, health
    commit, and rollback in QEMU and by physically removing power on the
    production-equivalent Zero 2 W image.
    - [x] Exercise the complete signed OS state machine in the ARM64 QEMU guest,
      including interrupted/truncated download, failed-candidate fallback,
      quarantine, retry, and healthy commit without claiming Pi firmware
      fidelity.
    - [ ] Repeat the matrix on the production-equivalent Zero 2 W image with
      measured physical power removal at every journal boundary.
  - [ ] Reimage the production phone only from locally attached recovery media,
    restore its per-device state, and prove both A/B directions plus recovery
    before handoff.
  - Done when a bad, truncated, or power-interrupted OS release cannot replace
    the last bootable slot and a healthy signed OS update commits unattended.

- [x] Secure the management API.
  - [x] Bind administrative endpoints to loopback or a Unix socket by default.
  - [x] Expose remote administration only through the authenticated maintenance path.
  - [x] Require a per-device credential or mutual TLS for state-changing requests.
  - [x] Add origin/CSRF checks, rate limiting, and firewall rules.
  - [x] Separate read-only status endpoints from administrative controls.
  - Done when an unauthenticated LAN client cannot control the phone or start an update.

- [x] Make OTA release storage immutable.
  - [x] Key release directories by sequence and version, not version alone.
  - [x] Refuse to overwrite a release referenced by `current` or `previous`.
  - [x] Reject duplicate or conflicting release identities.
  - [x] Add tests for version reuse, interrupted activation, and rollback.
  - Done when no valid manifest can destroy the active or rollback release.

- [x] Establish a single authoritative software version.
  - [x] Generate the daemon and OTA manifest versions from one source.
  - [x] Have the bundle builder execute the packaged daemon's `--version`.
  - [x] Refuse to sign a release when the embedded and requested versions differ.
  - [x] Keep documentation and compatibility metadata generated from the same version.
  - Done when a version mismatch cannot enter a signed bundle.

- [x] Fix PJSIP shared-state concurrency.
  - [x] Serialize SIP state changes or protect all shared state with synchronization.
  - [x] Snapshot and validate call IDs before answer or hangup operations.
  - [x] Copy `pj_str_t` values by length into bounded, NUL-terminated buffers.
  - [x] Add concurrency and malformed-string tests.
  - Done when SIP callbacks and daemon threads have no unsynchronized shared access.

- [x] Honor configured serial devices and baud rates.
  - [x] Pass parsed hardware configuration into the serial client.
  - [x] Remove hardcoded Beta-device assumptions.
  - [x] Add tests covering non-default paths and reconnects after USB renumbering.
  - Done when both MCU paths can be changed solely through configuration.

- [x] Attest both MCU firmware images after OTA flashing.
  - [x] Make each MCU report its role, firmware version, build hash, and protocol version.
  - [x] Put the expected identities in the signed release manifest.
  - [x] Verify the display and keypad independently before committing an update.
  - [x] Roll back if either MCU fails identity or health validation.
  - Done when swapped, stale, or incorrect firmware cannot pass the OTA health gate.

- [x] Quarantine failed OTA releases.
  - [x] Record failures by signed-manifest digest and sequence.
  - [x] Add exponential backoff and a maximum retry count.
  - [x] Retry only after a newer signed release or an explicit administrative clear.
  - [x] Test repeated download, flash, health failure, and rollback behavior.
  - Done when a bad release cannot repeatedly disrupt or reflash the phone.

## P1 — Production hardening

- [x] Harden the daemon's systemd sandbox.
  - [x] Remove unnecessary capabilities and unlimited memory locking.
  - [x] Use an unprivileged port or systemd socket activation.
  - [x] Enable filesystem, home, temporary-directory, address-family, and device restrictions.
  - [x] Replace the external ping startup gate with offline-capable retry behavior.
  - [x] Validate the unit with `systemd-analyze security` and `systemd-analyze verify`.

- [x] Remove the Git-based updater from production builds.
  - [x] Compile it only in an explicitly selected development mode, or delete it.
  - [x] Never fall back from signed OTA when the worker or trust key is unavailable.
  - [x] Replace remaining shell-interpolated commands with argument-vector execution.

- [x] Add signing-key lifecycle support.
  - [x] Support key IDs and multiple trusted public keys during rotation.
  - [x] Document revocation and emergency recovery.
  - [x] Maintain two currently verified encrypted offline copies of the private
    signing key on separate media, as required by the lifecycle procedure.
    - [x] Provide an OS-verified removable-media copier that rejects internal
      disks and overwrites, verifies the ciphertext, and records media custody.
    - [x] Create, recovery-test, and eject the first encrypted removable-media
      copy of the active `release-2026-08` key (`SD-EEE0E3AE`, 2026-09-06).
    - [x] Repeat the verified copy and recovery drill on a second physically
      distinct removable device (`NVME-68D6C050`, 2026-09-06).
  - [x] Perform and document a recovery drill.

- [x] Expand CI into a reproducible release pipeline.
  - [x] Link and test against a pinned PJSIP version.
  - [x] Compile both Arduino sketches with pinned tools and libraries.
  - [x] Rebuild and compare checked-in firmware artifacts.
  - [x] Run host code under AddressSanitizer and UndefinedBehaviorSanitizer.
  - [x] Add OTA install, activation, health-check, and rollback integration tests.
  - [x] Add `shellcheck` and systemd unit validation.
  - [x] Run PCB checks with a pinned KiCad environment.
  - [x] Publish checksums, source commit, tool versions, and an SBOM with releases.

- [x] Add operational monitoring and alerts.
  - [x] Monitor last check-in, SIP registration, and maintenance-tunnel availability.
  - [x] Alert on OTA failure or rollback, serial drops, and MCU resets.
  - [x] Monitor disk space, filesystem errors, certificate expiry, and reboot frequency.
  - [x] Back up OTA artifacts, server configuration, and authorized maintenance keys.
    - [x] Stream update-server and doormand state into encrypted Restic and
      verify every saved archive through a restore stream before success.

- [ ] Validate the full unattended workflow on real hardware.
  - [x] Install a release from `kmatzen.com` using the normal timer path.
  - [x] Confirm both MCUs, the host daemon, audio, SIP, and controls after activation.
  - [x] Force a failed health check and verify automatic rollback.
  - [ ] Test loss of power and network during download, flash, and activation.
    - [x] Automated fault injection proves atomic download, selective MCU-flash
      recovery, and activation-journal rollback.
    - [x] Provide a durable physical-interruption harness that captures the
      before/after boot, release, content, firmware, OTA, service, and HIL state.
    - [x] Physically interrupt Ethernet during an authenticated production-signed
      bundle download, retain client/relay/harness evidence, restore the link,
      and verify the complete bundle plus unchanged release state and full HIL.
    - [ ] Repeat the interruptions by physically removing power/network on the
      production phone for the remaining power, MCU-flash, and activation cases,
      and attach journal and measurement evidence.
  - [ ] Confirm remote maintenance works from outside the home network.
    - [x] Confirm the reverse tunnel, one-minute metrics pull, and nightly
      restricted backup pull remain operational through anima.
    - [x] Verify an approved hardware-backed administrator key through the
      reverse tunnel; the explicit FIDO identity succeeded without phone changes.
    - [x] Provide a privacy-preserving external-vantage audit that rejects the
      home source network and verifies hardware-backed login and phone health.
    - [ ] Complete an interactive maintenance session from a genuinely
      external network and retain the dated audit evidence.
  - [x] Provide a machine-validated final handoff record that binds the real
    Wi-Fi client matrix, external maintenance evidence, two distinct offline
    key copies, physical as-built evidence, and first-time-caller playtests.

## P2 — Reliability and maintainability

- [ ] Build richer interactive experiences and storytelling.
  - [x] Define the phone's core experience loop: invitation, interaction, response, consequence, and return visit.
  - [x] Create a narrative system for branching calls, timed events, recurring characters, secrets, and persistent story state.
  - [x] Let stories react to handset state, keypad input, coins, cards or tokens, time of day, prior choices, and interrupted calls.
  - [x] Support graceful recovery when a caller hangs up, times out, enters unexpected input, or returns later.
  - [x] Add clear audio and display feedback so callers always understand what actions are possible and whether input was accepted.
  - [x] Provide reusable pacing tools for prompts, pauses, repetition, escalation, callbacks, and satisfying endings.
  - [x] Build authoring and validation tools so new stories can be created without modifying daemon code.
  - [x] Add a local preview or simulation mode for playing through every branch before deployment.
  - [x] Validate story graphs for unreachable scenes, dead ends, missing media, invalid transitions, and infinite loops.
  - [x] Make content packages independently versioned, signed, updateable, and reversible through OTA.
  - [x] Add accessibility options for volume, prompt repetition, response timing, spoken instructions, and display legibility.
  - [ ] Conduct playtests with first-time callers and record where they become confused, disengage, or fail to discover an interaction.
    - [x] Provide privacy-preserving guided participant, resilience-scenario,
      and release-decision commands with tamper-checked evidence files.
  - [x] Collect privacy-preserving experience metrics such as completion, abandonment, retries, branch selection, and session duration.
  - [x] Document the intended tone, characters, world rules, interaction vocabulary, and content-review standards.
  - Done when a non-developer can author and preview a branching experience, a first-time caller can complete it without coaching, interrupted sessions recover coherently, and content can be safely deployed or rolled back independently.

- [x] Create an initial story and interaction roadmap.
  - [x] Ship one polished short experience that demonstrates calls, keypad choices, audio, display feedback, and persistent consequences.
  - [x] Add at least one experience that rewards a return visit or changes over real-world time.
  - [x] Add optional discoveries that use the physical phone hardware without blocking the main story.
  - [x] Establish a small library of reusable voices, sound cues, transitions, and interaction patterns.
  - [x] Define content ratings and safeguards appropriate for the phone's expected audience and location.
  - [x] Keep a fallback experience available when the network or external services are unavailable.

- [ ] Add a signed downloadable-experience catalog for lifetime expansion.
  - [x] Preserve the security boundary: native C plugins ship only in signed
    daemon releases; ordinary downloadable experiences are data packages run
    through a constrained, versioned capability API.
  - [x] Document the distribution, package, lifecycle, owner experience,
    recovery, privacy, and release-gate design in
    `host/docs/DOWNLOADABLE_EXPERIENCES.md`.
  - [x] Define and generate signed catalog and experience-package schemas,
    compatibility metadata, ratings, quotas, and capability declarations.
  - [ ] Publish immutable packages and channel catalogs through
    `updates.kmatzen.com`, with stable/beta/device-group rollout, holds,
    withdrawal, and an emergency signed denylist.
    - [x] Implement a fail-closed publisher and verify FIDO-authenticated,
      operator-writable access to `anima`'s container-backed update web root.
    - [ ] Complete the offline package/catalog key ceremony, provision both
      public trust roots through an existing-key-signed phone release, and
      publish plus externally verify the first production catalog objects.
  - [x] Extend the authoring tool to produce deterministic packages and reject
    unsafe paths, missing media, invalid graphs, incompatible schemas, and
    excessive resource use.
  - [x] Implement periodic catalog polling, staged download, signature and hash
    verification, safe extraction, eligibility checks, and idle-only atomic
    activation.
  - [x] Retain a known-good version and permanent offline fallback; add automatic
    rollback, digest quarantine, state migration, and bounded garbage collection.
  - [x] Ensure interruption at download, extraction, validation, activation,
    migration, or cleanup leaves a bootable and selectable known-good package.
  - [x] Add an authenticated owner view for installed experiences, ratings,
    update health, storage, enable/disable, and fallback selection; keep advanced
    controls behind the restricted maintenance path.
  - [x] Add privacy-preserving package health and engagement metrics without
    uploading speech, credentials, free-form input, or reconstructable histories.
  - [x] Test malicious archives, compromised transport, signature/key failures,
    compatibility, disk-full, withdrawal, network loss, restart, rollback, and
    power interruption in unit tests and QEMU.
    - [x] Cover malicious archives, transport and signature compromise,
      compatibility rejection, disk-full preservation, withdrawal, network
      loss, restart recovery, rollback, and durable-transition interruption in
      the content unit suite.
    - [x] Exercise signed installation, catalog-signature compromise, HTTPS
      origin loss and recovery, signed withdrawal, and worker restart through
      the production lifecycle worker in the ARM64 QEMU guest.
    - [x] Prove real ENOSPC handling in a size-bounded QEMU filesystem while
      retaining a readable, selected known-good fallback.
    - [x] Add host-driven QEMU power cuts at each content activation journal
      boundary; retain the known-good release after reboot.
  - [ ] Complete real-phone audio, display, peripheral, storage, owner-usability,
    and staged production acceptance.
  - Done when the phone can safely gain, update, disable, withdraw, and roll back
    experiences for its installed life without reflashing or expert owner action.

- [x] Convert long Arduino operations to nonblocking state machines.
  - [x] Add deadlines and transaction IDs to VFD and coin-validator operations.
  - [x] Reset the watchdog only when forward progress is made.
  - [x] Report the previous MCU reset cause at startup.

- [x] Frame the MCU communication protocol.
  - [x] Add packet length, message type, sequence number, and CRC.
  - [x] Add acknowledgements or replay handling for critical events.
  - [x] Define protocol-version negotiation and compatibility behavior.

- [x] Replace payment-card identifiers with purpose-built credentials.
  - [x] Provision random tokens or keyed hashes instead of real card numbers.
  - [x] Clear sensitive buffers after use.
  - [x] Document prohibited configuration and logging data.

- [ ] Create an as-built record for every physical phone.
  - [x] Provide guided commands that hash installed artifacts, photographs,
    physical-test evidence, and enforce voltage measurements where required.
  - [ ] Record PCB revision, source tag, Gerber/BOM hashes, and installed firmware hashes.
  - [ ] Record device serial numbers, wiring deviations, and assembly photos.
  - [ ] Measure power and brownout behavior with the complete installed hardware.
  - [ ] Test safe recovery after arbitrary power loss.

- [x] Remove stale addresses and deployment procedures.
  - [x] Replace hardcoded `192.168.86.145` and `192.168.86.152` values with configuration or a stable hostname.
  - [x] Separate developer deployment, factory provisioning, production OTA, and recovery documentation.
  - [x] Mark all `git pull` deployment instructions as development-only.
  - [x] Correct the stale I2C address note in `Arduino/PINOUT.md`.
  - [x] Reconcile fabricated-board and future-revision notes in `pcb/README.md`.

- [x] Add staged rollout controls.
  - [x] Support device groups or channels, rollout holds, and explicit release withdrawal.
  - [x] Respect active calls and maintenance blackout periods.
  - [x] Add a nightly hardware-in-the-loop smoke test when practical.

## Release acceptance checklist

A release is ready for an inexperienced end user only when:

- [x] Administrative controls are inaccessible without authentication.
- [x] The host and both MCU images are authenticated and attested.
- [x] A successful OTA has completed through the scheduled production path.
- [x] A deliberately bad OTA has rolled back without manual intervention.
- [x] Failed releases stop retrying automatically.
- [ ] Power and network interruption tests recover safely.
- [x] Remote maintenance works through the known domain without inbound home-network access.
- [x] Monitoring reports the phone's health and alerts on loss of contact.
- [x] Signing keys, server state, and recovery instructions have currently
  verified tested backups.
- [ ] A first-time caller can discover and complete the primary experience without instruction from the owner.
- [ ] Story interruption, timeout, repeat-play, offline, and return-visit paths have been playtested.
- [x] Narrative content can be previewed, validated, deployed, and rolled back independently of daemon code.

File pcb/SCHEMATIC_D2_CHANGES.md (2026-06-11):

# TVS Diode Schematic: D1, D2, D3 (P6KE6.8CA)

**Rationale:** P6KE6.8CA (600W bidirectional TVS, DO-15 THT) protects signal lines from ESD and back-EMF. D1, D2, D3 each clamp a signal to GND.

## Implemented State (THT)

- **D1, D2, D3:** P6KE6.8CA (600W bidirectional TVS, DO-15 THT)
- **Pin 1:** GND
- **Pin 2:** Protected signal (e.g. speaker_receiver+, speaker_front+)

Clamps transient voltage between signal and GND (~10.5V max). In stock at DigiKey (Littelfuse), Mouser (Taiwan Semiconductor).

### D2 (speaker_front+)

- **D2:** P6KE6.8CA
- Pin 1 → GND; Pin 2 → `speaker_front+` (TDA2822 channel A output → ringer)
- No VCC connection; TVS clamps signal to GND only.

### Net Reference

| Net | Nodes |
|---|---|
| coin_rx | A2 MISO, J1 Pin_3 |
| speaker_front+ | C_outA pin 2, J2 Pin_19, **D2 pin 2**  |
| speaker_receiver+ | C_outB pin 2, **D1 pin 2**, J4 pin 2 |
| gnd (TVS pin 1) | D1, D2, D3 pin 1 → GND |

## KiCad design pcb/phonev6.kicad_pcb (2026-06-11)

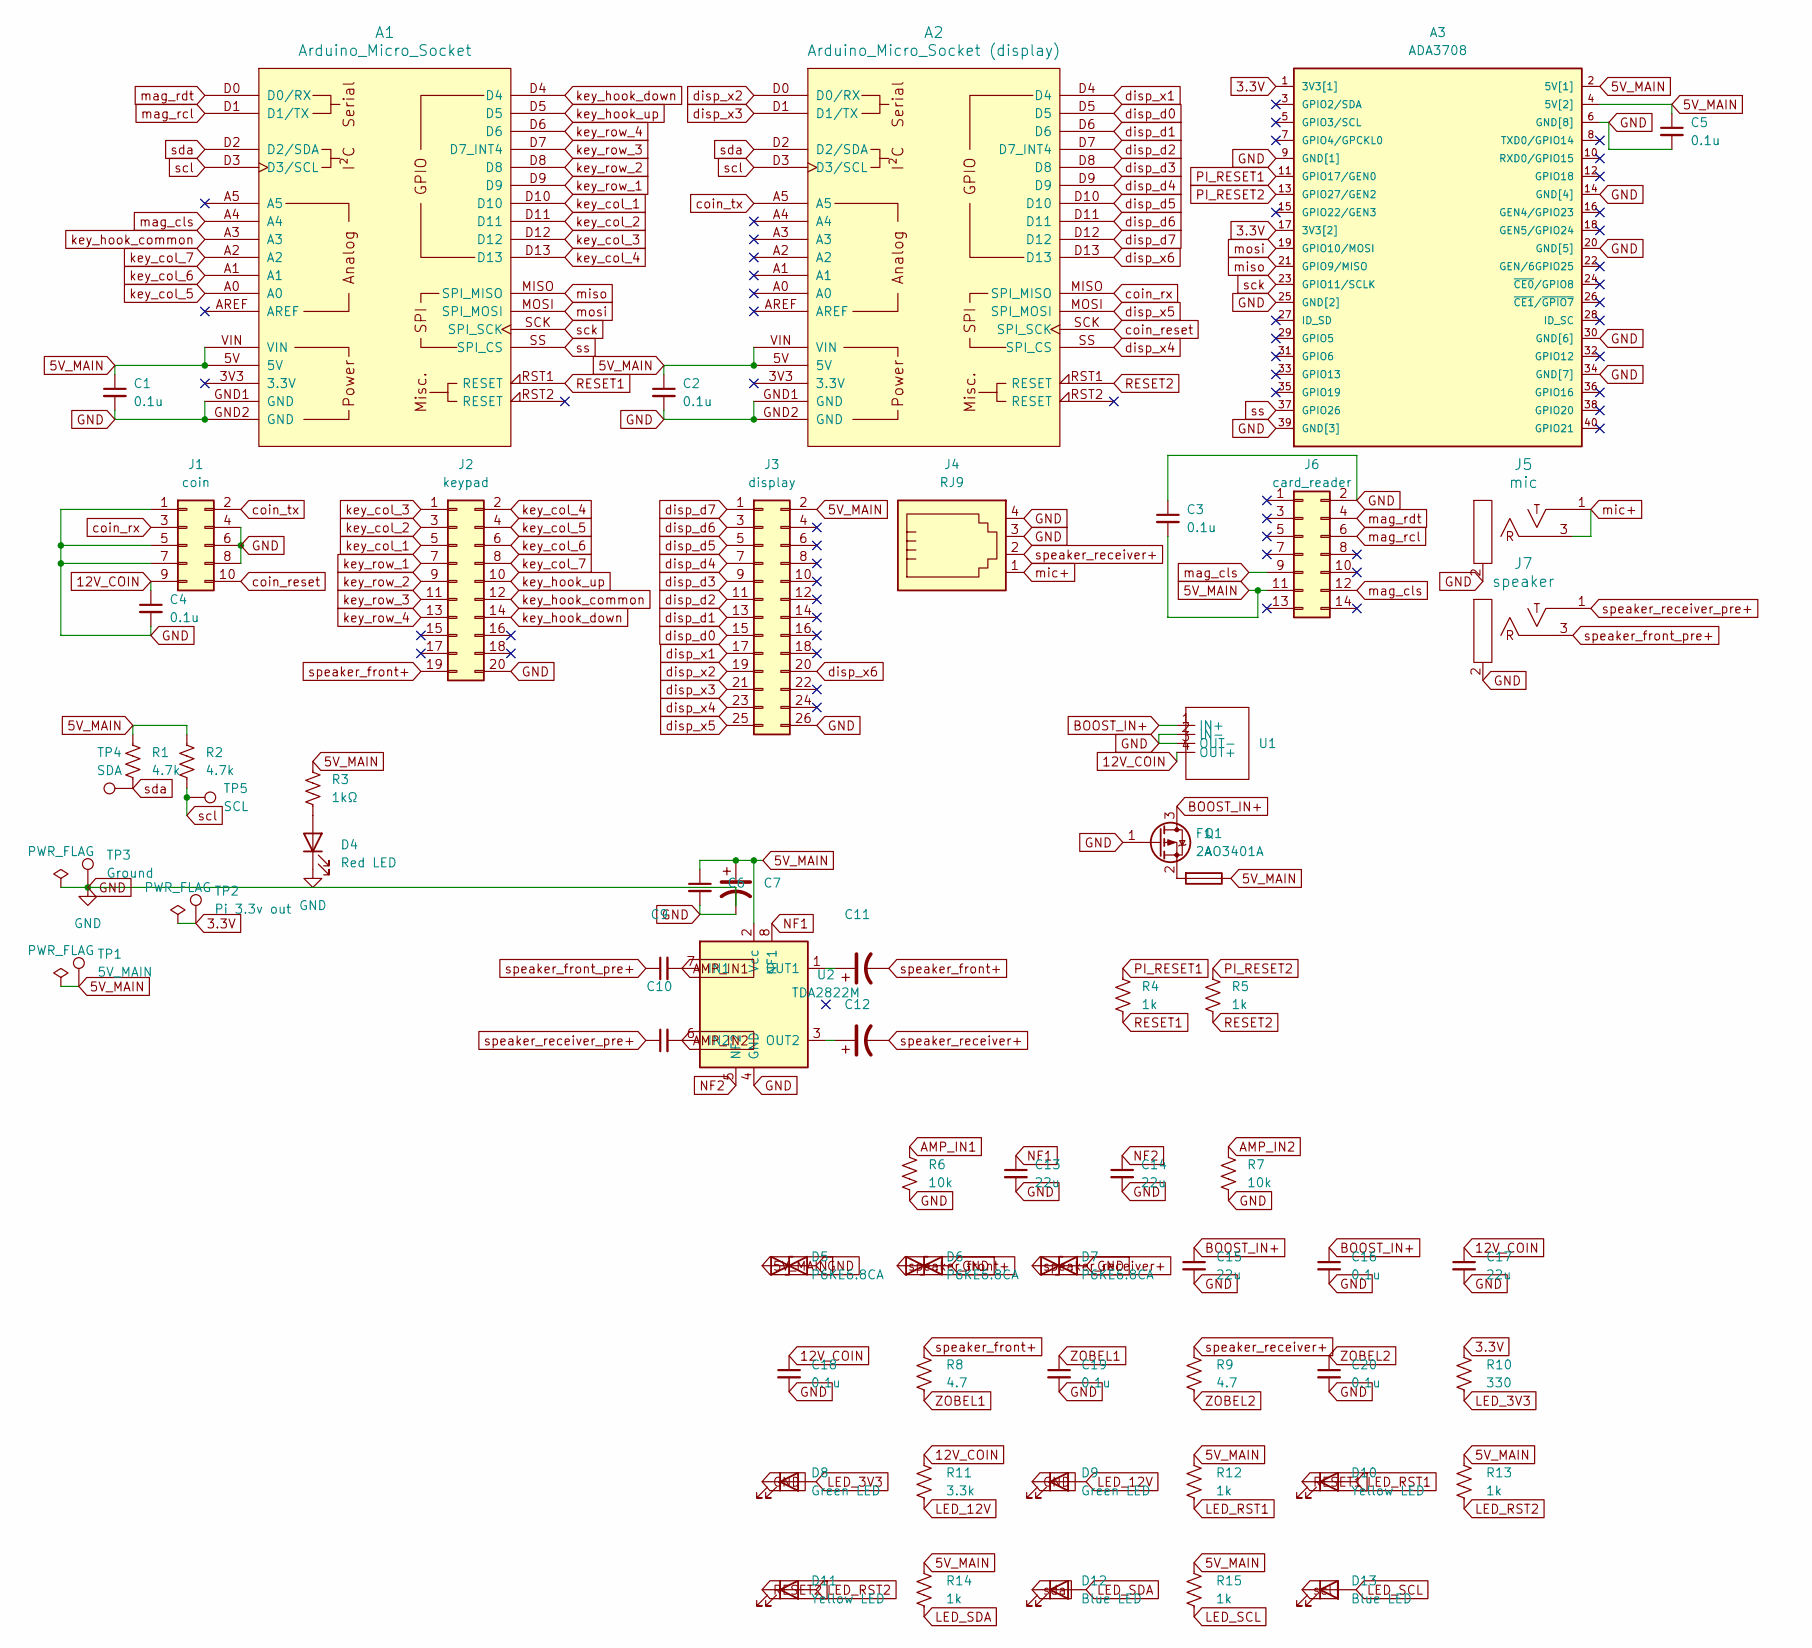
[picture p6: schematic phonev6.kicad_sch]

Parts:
A1: Arduino_Micro_Socket
A2: Arduino_Micro_Socket (display); Arduino_Micro_Socket
A3: ADA3708; ADA3708_RPI-ZERO
C1, C2, C3, C4, C5, C16, C18, C19, C20: 0.1u; C_0805_2012Metric; LCSC C49678
C6, C9, C10: 100nF; C_0805_2012Metric; LCSC C49678
C7, C11, C12: 100µF 16V; CP_Elec_6.3x5.4; LCSC C37308
C13, C14, C15, C17: 22u; C_0805_2012Metric; LCSC C45783
D4: Red LED; LED_0805_2012Metric; LCSC C2297
D5, D6, D7: P6KE6.8CA; D_SMB; LCSC C78395
D8, D9: Green LED; LED_0805_2012Metric; LCSC C2297
D10, D11: Yellow LED; LED_0805_2012Metric; LCSC C2296
D12, D13: Blue LED; LED_0805_2012Metric; LCSC C2293
F1: 2A; Fuse_1812_4532Metric; LCSC C2649901
J1: coin; IDC-Header_2x05_P2.54mm_Vertical
J2: keypad; IDC-Header_2x10_P2.54mm_Vertical
J3: display; IDC-Header_2x13_P2.54mm_Vertical
J4: RJ9; RJ9_Evercom_5301-440xxx_Horizontal
J5: mic; AUDIO-TH_HOOYA_PJ-320; Part Number WQP-WQP419GR
J6: card_reader; IDC-Header_2x07_P2.54mm_Vertical
J7: speaker; AUDIO-TH_HOOYA_PJ-320; Part Number WQP-WQP419GR; LCSC C2884926
Q1: AO3401A; SOT-23; LCSC C15127
R1, R2: 4.7k; R_0805_2012Metric; LCSC C17673
R3: 1kΩ; R_0805_2012Metric; LCSC C17513
R4, R5, R12, R13, R14, R15: 1k; R_0805_2012Metric; LCSC C17513
R6, R7: 10k; R_0805_2012Metric; LCSC C17414
R8, R9: 4.7; R_0805_2012Metric; LCSC C2889556
R10: 330; R_0805_2012Metric; LCSC C17630
R11: 3.3k; R_0805_2012Metric; LCSC C26010
TP1: 5V_MAIN; TestPoint_Loop_D2.50mm_Drill1.0mm
TP2: Pi 3.3v out; TestPoint_Loop_D2.50mm_Drill1.0mm
TP3: Ground; TestPoint_Loop_D2.50mm_Drill1.0mm
TP4: SDA; TestPoint_Loop_D2.50mm_Drill1.0mm
TP5: SCL; TestPoint_Loop_D2.50mm_Drill1.0mm
U1: XL6009_module
U2: TDA2822M; SOIC-8_3.9x4.9mm_P1.27mm; LCSC C725341

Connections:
3.3V: A3.1 (3V3[1]), A3.17 (3V3[2]), R10.1, TP2.1
5V_MAIN: A1.5V, A1.VIN, A2.5V, A2.VIN, A3.2 (5V[1]), A3.4 (5V[2]), C1.1, C2.1, C3.2, C5.1, C6.1, C7.1, D5.1, F1.1, J3.2, J6.11, R1.1, R2.1, R3.1, R12.1, R13.1, R14.1, R15.1, TP1.1, U2.2 (Vcc)
12V_COIN: C4.1, C17.1, C18.1, J1.9, R11.1, U1.4 (OUT+)
AMP_IN1: C9.2, R6.1, U2.7 (IN1)
AMP_IN2: C10.2, R7.1, U2.6 (IN2)
BOOST_IN+: C15.1, C16.1, Q1.3 (D), U1.1 (IN+)
GND: A1.GND1 (GND), A1.GND2 (GND), A2.GND1 (GND), A2.GND2 (GND), A3.6 (GND[8]), A3.9 (GND[1]), A3.14 (GND[4]), A3.20 (GND[5]), A3.25 (GND[2]), A3.30 (GND[6]), A3.34 (GND[7]), A3.39 (GND[3]), C1.2, C2.2, C3.1, C4.2, C5.2, C6.2, C7.2, C13.2, C14.2, C15.2, C16.2, C17.2, C18.2, C19.2, C20.2, D4.1 (K), D5.2, D6.2, D7.2, D8.1 (K), D9.1 (K), J1.1, J1.4, J1.5, J1.6, J1.7, J1.8, J2.20, J3.26, J4.3, J4.4, J5.2 (SHEILD), J6.2, J7.2 (SHEILD), Q1.1 (G), R6.2, R7.2, TP3.1, U1.2 (IN-), U1.3 (OUT-), U2.4 (GND); also elsewhere on the board
LED_3V3: D8.2 (A), R10.2
LED_12V: D9.2 (A), R11.2
LED_RST1: D10.2 (A), R12.2
LED_RST2: D11.2 (A), R13.2
LED_SCL: D13.2 (A), R15.2
LED_SDA: D12.2 (A), R14.2
NF1: C13.1, U2.8 (NF1)
NF2: C14.1, U2.5 (NF2)
unnamed: D4.2 (A), R3.2
unnamed: F1.2, Q1.2 (S)
unnamed: C11.1, U2.1 (OUT1)
unnamed: C12.1, U2.3 (OUT2)
PI_RESET1: A3.11 (GPIO17/GEN0), R4.1
PI_RESET2: A3.13 (GPIO27/GEN2), R5.1
RESET1: A1.RST1 (RESET), D10.1 (K), R4.2
RESET2: A2.RST1 (RESET), D11.1 (K), R5.2
ZOBEL1: C19.1, R8.2
ZOBEL2: C20.1, R9.2
coin_reset: A2.SCK (SPI_SCK), J1.10
coin_rx: A2.MISO (SPI_MISO), J1.3
coin_tx: A2.A5, J1.2
disp_d0: A2.D5, J3.15
disp_d1: A2.D6, J3.13
disp_d2: A2.D7 (D7_INT4), J3.11
disp_d3: A2.D8, J3.9
disp_d4: A2.D9, J3.7
disp_d5: A2.D10, J3.5
disp_d6: A2.D11, J3.3
disp_d7: A2.D12, J3.1
disp_x1: A2.D4, J3.17
disp_x2: A2.D0 (D0/RX), J3.19
disp_x3: A2.D1 (D1/TX), J3.21
disp_x4: A2.SS (SPI_CS), J3.23
disp_x5: A2.MOSI (SPI_MOSI), J3.25
disp_x6: A2.D13, J3.20
key_col_1: A1.D10, J2.5
key_col_2: A1.D11, J2.3
key_col_3: A1.D12, J2.1
key_col_4: A1.D13, J2.2
key_col_5: A1.A0, J2.4
key_col_6: A1.A1, J2.6
key_col_7: A1.A2, J2.8
key_hook_common: A1.A3, J2.12
key_hook_down: A1.D4, J2.14
key_hook_up: A1.D5, J2.10
key_row_1: A1.D9, J2.7
key_row_2: A1.D8, J2.9
key_row_3: A1.D7 (D7_INT4), J2.11
key_row_4: A1.D6, J2.13
mag_cls: A1.A4, J6.9, J6.12
mag_rcl: A1.D1 (D1/TX), J6.6
mag_rdt: A1.D0 (D0/RX), J6.4
mic+: J4.1, J5.1 (SIG), J5.3 (SW)
miso: A1.MISO (SPI_MISO), A3.21 (GPIO9/MISO)
mosi: A1.MOSI (SPI_MOSI), A3.19 (GPIO10/MOSI)
sck: A1.SCK (SPI_SCK), A3.23 (GPIO11/SCLK)
scl: A1.D3 (D3/SCL), A2.D3 (D3/SCL), D13.1 (K), R2.2, TP5.1
sda: A1.D2 (D2/SDA), A2.D2 (D2/SDA), D12.1 (K), R1.2, TP4.1
speaker_front+: C11.2, D6.1, J2.19, R8.1
speaker_front_pre+: C9.1, J7.3 (SW)
speaker_receiver+: C12.2, D7.1, J4.2, R9.1
speaker_receiver_pre+: C10.1, J7.1 (SIG)
ss: A1.SS (SPI_CS), A3.37 (GPIO26)

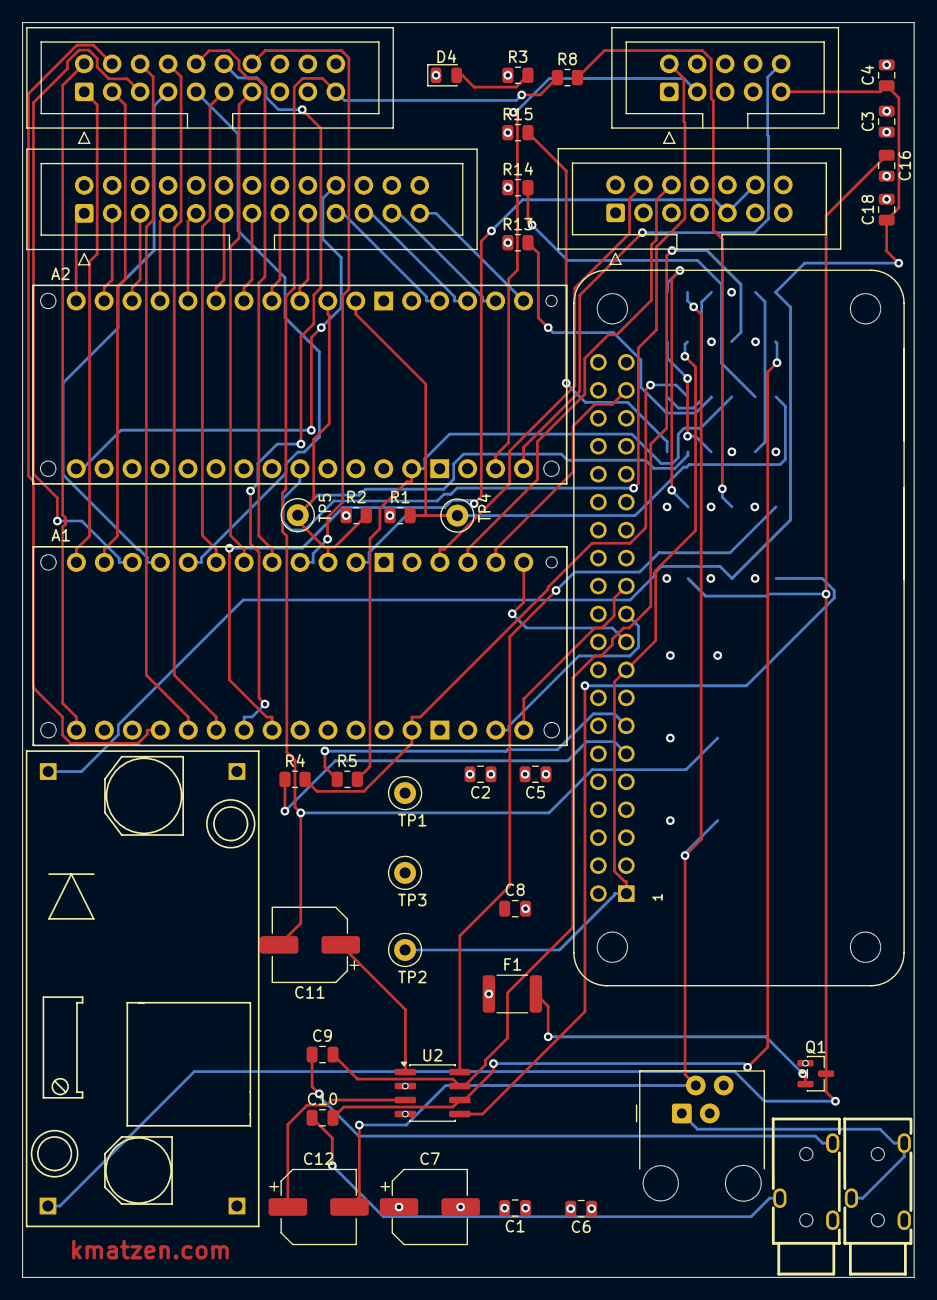
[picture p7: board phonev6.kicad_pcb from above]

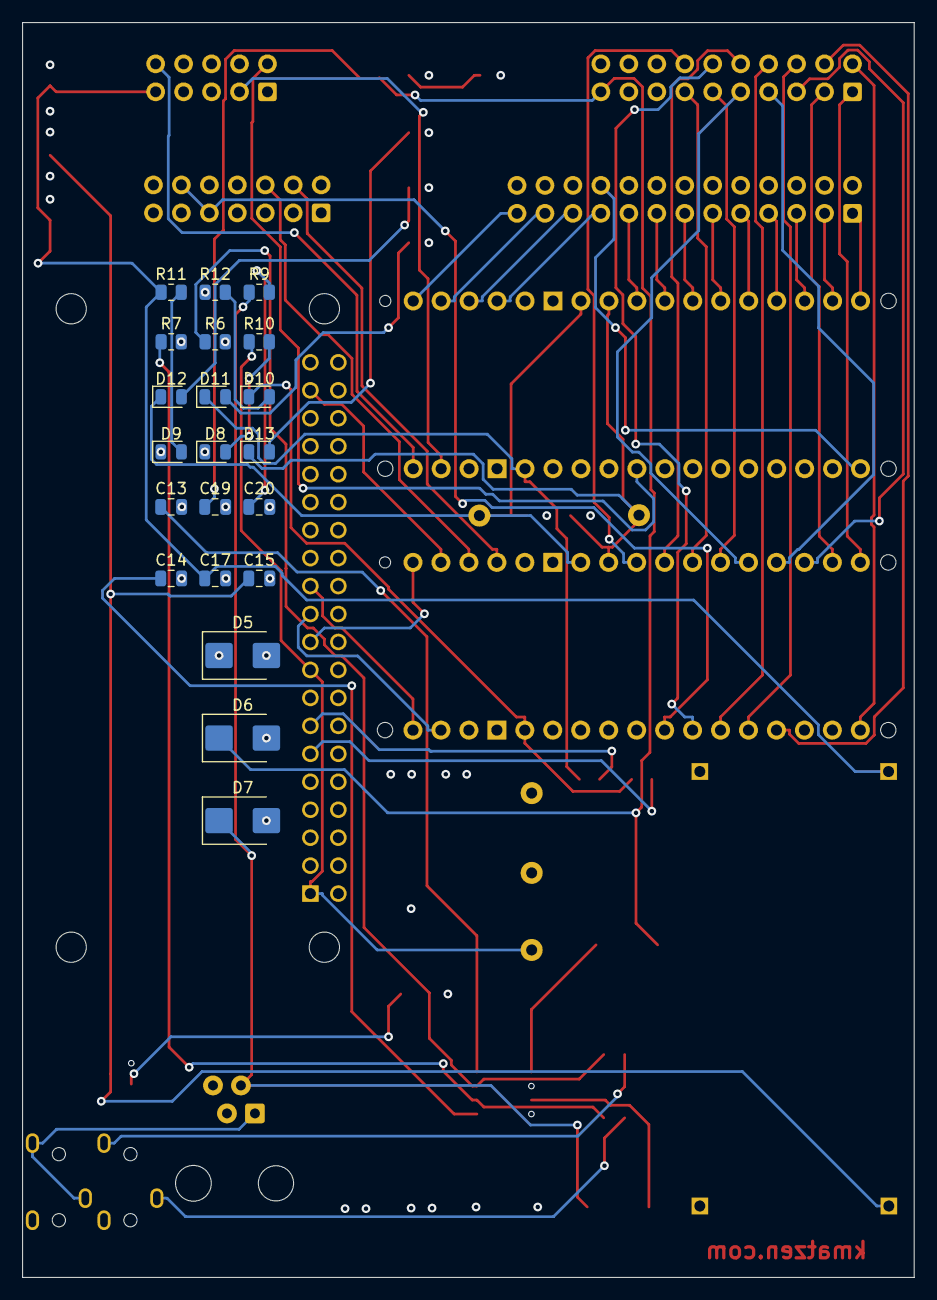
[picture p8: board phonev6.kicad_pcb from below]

Board: 4 copper layers, 81.0 x 114.0 mm, 64 parts (21 on the bottom side), 70 nets.

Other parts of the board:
C8: 4.7µF; C_0805_2012Metric

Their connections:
GND: C8.2; also elsewhere on the board

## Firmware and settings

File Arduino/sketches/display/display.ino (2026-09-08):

/*
 * Millennium Beta (display) firmware.
 * Build with FQBN arduino:avr:millennium_beta so the board identifies as
 * "Millennium Beta" on USB (/dev/serial/by-id/usb-Arduino_LLC_Millennium_Beta-if00).
 */
#include <SoftwareSerial.h>
#include <Wire.h>
#include <avr/wdt.h>
#include <MillenniumProtocol.h>

#ifndef MILLENNIUM_FIRMWARE_VERSION
#define MILLENNIUM_FIRMWARE_VERSION "0.0.0-development"
#endif
#ifndef MILLENNIUM_FIRMWARE_BUILD
#define MILLENNIUM_FIRMWARE_BUILD "unknown"
#endif
#define I2C_DISPLAY_ADDR 8

/* Legacy raw query retained only for the offline OTA attestation helper. */
#define CMD_IDENTITY      0x07  /* OTA attestation query */

/* Captured before the Arduino runtime or boot-time watchdog can clear MCUSR. */
uint8_t previousResetCause __attribute__((section(".noinit")));
void captureResetCause(void) __attribute__((naked, section(".init3")));
void captureResetCause(void) {
  previousResetCause = MCUSR;
  MCUSR = 0;
  wdt_disable();
}
static bool resetCauseReported = false;

#define HEARTBEAT_INTERVAL_MS 10000UL

#define d0 5
#define d1 6
#define d2 7
#define d3 8
#define d4 9
#define d5 10
#define d6 11
#define d7 12
#define WR 4
#define AD 0
#define RD 1
#define CS 17
#define TEST 16
#define RESET 13

const int coinResetPin = 15;
SoftwareSerial coinSerialDevice(14, 23);

/*
 * Coin validator EEPROM image (256 bytes).
 *
 * This table is written to the Mars/MEI TRC-6500 coin validator's EEPROM
 * via the CMD_COIN_PROGRAM command.  It configures the validator's acceptance
 * parameters for US coinage:
 *
 *   Bytes   0-14:  Global configuration (sensor thresholds, timing, options)
 *   Bytes  15-29:  Coin type 1 — US nickel   ($0.05)
 *   Bytes  30-44:  Coin type 2 — US dime     ($0.10)
 *   Bytes  45-59:  Coin type 3 — US quarter  ($0.25)
 *   Bytes  60-74:  Coin type 4 — US dollar   ($1.00)  [Sacagawea / Presidential]
 *   Bytes  75-104: Coin type 5-6 (reserved / unused, zeroed)
 *   Bytes 105-191: Reserved (zeroed)
 *   Bytes 192-210: Calibration / checksum block
 *   Bytes 211-255: Reserved / serial data
 *
 * Each 15-byte coin type block contains acceptance windows for the coin's
 * diameter, thickness, and metal composition as measured by the validator's
 * inductive sensors.  The values were captured from a known-good validator
 * and are specific to the TRC-6500 hardware revision.
 */
byte coinEeprom[] = {
    3,   217, 5,   255, 0,   248, 1,   110, 10,  0,   5,   8,   7,   4,   0,
    3,   240, 5,   204, 40,  0,   192, 0,   12,  40,  180, 18,  50,  128, 100,
    255, 0,   45,  89,  62,  236, 40,  200, 80,  111, 37,  75,  35,  72,  50,
    146, 38,  207, 66,  30,  39,  134, 53,  59,  59,  184, 47,  145, 74,  178,
    14,  207, 47,  24,  61,  103, 43,  139, 78,  50,  53,  142, 43,  81,  67,
    171, 39,  11,  74,  45,  76,  20,  162, 141, 49,  87,  37,  7,   68,  99,
    40,  8,   166, 157, 18,  23,  44,  143, 50,  98,  20,  9,   163, 138, 20,
    25,  40,  71,  58,  222, 63,  145, 0,   0,   0,   0,   0,   0,   0,   0,
    0,   0,   0,   0,   0,   0,   0,   0,   0,   0,   0,   0,   0,   0,   0,
    0,   0,   0,   0,   0,   0,   0,   0,   0,   0,   0,   0,   0,   0,   0,
    0,   0,   0,   0,   0,   0,   0,   0,   0,   0,   0,   0,   0,   0,   0,
    0,   0,   0,   0,   0,   0,   0,   0,   0,   0,   0,   0,   0,   0,   0,
    0,   0,   0,   0,   0,   0,   0,   0,   0,   0,   0,   0,   163, 69,  54,
    199, 39,  3,   66,  5,   66,  68,  151, 196, 57,  67,  22,  195, 89,  5,
    30,  195, 0,   0,   0,   0,   0,   0,   0,   0,   0,   0,   0,   0,   0,
    0,   0,   0,   0,   0,   0,   0,   0,   0,   0,   0,   0,   0,   0,   0,
    0,   0,   0,   0,   0,   0,   0,   0,   0,   0,   0,   0,   49,  48,  50,
    48};

/* I2C rx buffer: 64 bytes. Wire lib on AVR uses 32-byte hw buffer.
 * Host must keep commands under this limit (#134). */
/* Sized to hold multiple complete Wire frames while USB is briefly
 * backpressured. Long display and coin work is now cooperative.
 *
 * Keep this <= 256: i2cHead/i2cTail are bytes. */
#define I2C_BUF_SIZE 256
static volatile byte i2cBuf[I2C_BUF_SIZE];
static volatile byte i2cHead = 0, i2cTail = 0;

/* (#230) Bytes the ISR had to throw away because the ring was full, and the
 * last value reported to the host. A full ring silently truncates whatever
 * Alpha was sending -- a card PAN included -- and the host still parses the
 * short result as a valid event, so the loss has to be visible. */
static volatile unsigned int i2cOverflow = 0;
static unsigned int i2cOverflowReported = 0;
static unsigned long lastOverflowReport = 0;

/* Re-announce the overflow count this often, zero included -- matching Alpha.
 * Reporting only on change means a count that starts at 0 and stays there is
 * never sent at all, so the host's gauge simply does not exist and "no metric"
 * cannot be told apart from "no overflows". An affirmative zero is the whole
 * point of instrumenting this. */
static const unsigned long OVERFLOW_REPORT_INTERVAL_MS = 30000;

static unsigned long lastHeartbeat = 0;
static MillenniumDecoder protocolDecoder;
static uint8_t protocolSequence = 0;
static bool lastDisplayCommandValid = false;
static bool lastCoinCommandValid = false;
static uint8_t lastDisplayCommandSequence = 0;
static uint8_t lastCoinCommandSequence = 0;

enum DisplayOperation { DISPLAY_IDLE, DISPLAY_RESET_HIGH, DISPLAY_RESET_LOW,
                        DISPLAY_WAIT_CLEAR, DISPLAY_WRITE_CONTROL, DISPLAY_WRITE_TEXT };
static DisplayOperation displayOperation = DISPLAY_IDLE;
static uint8_t displayBuffer[100];
static uint8_t displayLength = 0;
static uint8_t displayIndex = 0;
static uint8_t displayControl = 0;
static uint8_t displayTransaction = 0;
static unsigned long displayNext = 0;
static unsigned long displayDeadline = 0;

enum CoinOperation { COIN_IDLE, COIN_RESET_LOW, COIN_RESET_HIGH, COIN_CONTROL_WAIT,
                     COIN_PROGRAM, COIN_VERIFY_SEND, COIN_VERIFY_WAIT };
static CoinOperation coinOperation = COIN_IDLE;
static uint16_t coinIndex = 0;
static uint8_t coinStep = 0;
static uint8_t coinTransaction = 0;
static unsigned long coinNext = 0;
static unsigned long coinDeadline = 0;
static unsigned long coinByteDeadline = 0;

const unsigned long SERIAL_TIMEOUT_MS = 2000;

void setup() {
  SerialUSB.begin(9600);

  Wire.begin(I2C_DISPLAY_ADDR);
  Wire.onReceive(receiveEvent);

  pinMode(coinResetPin, OUTPUT);
  pinMode(14, INPUT);
  digitalWrite(coinResetPin, HIGH);
  coinSerialDevice.begin(600);

  pinMode(d0, OUTPUT);
  pinMode(d1, OUTPUT);
  pinMode(d2, OUTPUT);
  pinMode(d3, OUTPUT);
  pinMode(d4, OUTPUT);
  pinMode(d5, OUTPUT);
  pinMode(d6, OUTPUT);
  pinMode(d7, OUTPUT);
  pinMode(WR, OUTPUT);
  pinMode(AD, OUTPUT);
  pinMode(RD, OUTPUT);
  pinMode(CS, OUTPUT);
  pinMode(TEST, OUTPUT);
  pinMode(RESET, OUTPUT);

  digitalWrite(d0, HIGH);
  digitalWrite(d1, HIGH);
  digitalWrite(d2, HIGH);
  digitalWrite(d3, HIGH);
  digitalWrite(d4, HIGH);
  digitalWrite(d5, HIGH);
  digitalWrite(d6, HIGH);
  digitalWrite(d7, HIGH);

  digitalWrite(WR, HIGH);
  digitalWrite(AD, LOW);
  digitalWrite(RD, HIGH);
  digitalWrite(CS, HIGH);
  digitalWrite(TEST, HIGH);
  digitalWrite(RESET, LOW);

  vfdreset();
  delay(100);
  writeCharacter(20u);
  writeCharacter(21);

  wdt_enable(WDTO_4S);
}

void receiveEvent(int howMany) {
  while (Wire.available()) {
    byte b = Wire.read();
    byte next = (i2cHead + 1) % I2C_BUF_SIZE;
    if (next != i2cTail) {
      i2cBuf[i2cHead] = b;
      i2cHead = next;
    } else {
      i2cOverflow++;   /* (#230) ring full; this byte is gone */
    }
  }
}

void vfdreset() {
  digitalWrite(RESET, HIGH);
  delay(2);
  digitalWrite(RESET, LOW);
  delay(10);
}

static void sendFrame(uint8_t type, const uint8_t *payload, uint8_t length) {
  uint8_t frame[MILLENNIUM_PROTOCOL_MAX_FRAME];
  size_t frameLength = millenniumEncode(type, protocolSequence++, payload, length,
                                        frame, sizeof(frame));
  if (frameLength) SerialUSB.write(frame, frameLength);
}

static void sendAck(uint8_t sequence, uint8_t status) {
  uint8_t payload[2] = {sequence, status};
  sendFrame(MCU_MSG_ACK, payload, sizeof(payload));
}

static void sendOperation(char code, uint8_t transaction,
                          const uint8_t *details, uint8_t length) {
  uint8_t payload[5];
  if (length > 3) length = 3;
  payload[0] = (uint8_t)code;
  payload[1] = transaction;
  if (length) memcpy(payload + 2, details, length);
  sendFrame(MCU_EVT_OPERATION, payload, length + 2);
}

static void sendResetCause() {
  uint8_t payload[4];
  unsigned int n;
  if (resetCauseReported) return;
  n = previousResetCause;
  payload[0] = 'D';
  payload[1] = '0' + (n / 100) % 10;
  payload[2] = '0' + (n / 10) % 10;
  payload[3] = '0' + n % 10;
  sendFrame(MCU_EVT_DIAGNOSTIC, payload, sizeof(payload));
  resetCauseReported = true;
}

static void printIdentity() {
  SerialUSB.println(F("MILLENNIUM role=display version=" MILLENNIUM_FIRMWARE_VERSION
                      " protocol=" MILLENNIUM_PROTOCOL_VERSION_STRING
                      " build=" MILLENNIUM_FIRMWARE_BUILD " selftest=ok"));
  SerialUSB.print(F("reset_cause="));
  SerialUSB.println(previousResetCause);
}

static bool timeReached(unsigned long target) {
  return (long)(millis() - target) >= 0;
}

static void startDisplay(const MillenniumFrame &frame) {
  displayLength = frame.length;
  memcpy(displayBuffer, frame.payload, frame.length);
  displayIndex = 0;
  displayControl = 0;
  displayTransaction = frame.sequence;
  displayDeadline = millis() + 5000UL;
  digitalWrite(RESET, HIGH);
  displayNext = millis() + 2UL;
  displayOperation = DISPLAY_RESET_HIGH;
}

static void serviceDisplay() {
  if (displayOperation == DISPLAY_IDLE) return;
  if (timeReached(displayDeadline)) {
    sendOperation('X', displayTransaction, NULL, 0);
    displayOperation = DISPLAY_IDLE;
    return;
  }
  if (!timeReached(displayNext)) return;
  if (displayOperation == DISPLAY_RESET_HIGH) {
    digitalWrite(RESET, LOW);
    displayNext = millis() + 10UL;
    displayOperation = DISPLAY_RESET_LOW;
  } else if (displayOperation == DISPLAY_RESET_LOW) {
    displayNext = millis() + 100UL;
    displayOperation = DISPLAY_WAIT_CLEAR;
  } else if (displayOperation == DISPLAY_WAIT_CLEAR) {
    displayControl = 0;
    displayOperation = DISPLAY_WRITE_CONTROL;
  } else if (displayOperation == DISPLAY_WRITE_CONTROL) {
    writeCharacter(displayControl++ == 0 ? 20u : 18u);
    if (displayControl >= 2) displayOperation = DISPLAY_WRITE_TEXT;
    displayNext = millis();
  } else if (displayOperation == DISPLAY_WRITE_TEXT) {
    if (displayIndex < displayLength) {
      uint8_t value = displayBuffer[displayIndex++];
      writeCharacter(value == 0x0A ? 13 : value);
      displayNext = millis();
    }
    if (displayIndex >= displayLength) {
      sendOperation('R', displayTransaction, NULL, 0);
      displayOperation = DISPLAY_IDLE;
    }
  }
}

static void finishCoin(char code) {
  sendOperation(code, coinTransaction, NULL, 0);
  coinOperation = COIN_IDLE;
}

static void startCoinProgram(uint8_t transaction) {
  coinTransaction = transaction;
  coinIndex = 0;
  coinStep = 0;
  coinNext = millis();
  coinDeadline = millis() + 45000UL;
  coinOperation = COIN_PROGRAM;
  sendOperation('A', transaction, NULL, 0);
}

static void startCoinVerify(uint8_t transaction) {
  coinTransaction = transaction;
  coinIndex = 0;
  coinStep = 0;
  coinNext = millis();
  coinDeadline = millis() + 600000UL;
  coinOperation = COIN_VERIFY_SEND;
  sendOperation('D', transaction, NULL, 0);
}

static void serviceCoin() {
  static const uint8_t programPrefix[4] = {'E', 'A', 'P', 'w'};
  if (coinOperation == COIN_IDLE) return;
  if (timeReached(coinDeadline)) {
    finishCoin('X');
    return;
  }
  if (coinOperation == COIN_RESET_LOW && timeReached(coinNext)) {
    digitalWrite(coinResetPin, HIGH);
    coinNext = millis() + 1000UL;
    coinOperation = COIN_RESET_HIGH;
  } else if ((coinOperation == COIN_RESET_HIGH || coinOperation == COIN_CONTROL_WAIT) &&
             timeReached(coinNext)) {
    finishCoin('R');
  } else if (coinOperation == COIN_PROGRAM && timeReached(coinNext)) {
    if (coinStep < 4) coinSerialDevice.write(programPrefix[coinStep]);
    else if (coinStep == 4) coinSerialDevice.write(lowByte(coinIndex));
    else coinSerialDevice.write(coinEeprom[coinIndex]);
    coinStep++;
    coinNext = millis() + 20UL;
    if (coinStep >= 6) {
      coinStep = 0;
      coinIndex++;
      if (coinIndex >= 256) finishCoin('B');
    }
  } else if (coinOperation == COIN_VERIFY_SEND && timeReached(coinNext)) {
    while (coinSerialDevice.available()) coinSerialDevice.read();
    if (coinStep == 0) coinSerialDevice.write('q');
    else if (coinStep == 1) coinSerialDevice.write(0x01);
    else coinSerialDevice.write(lowByte(coinIndex));
    coinStep++;
    coinNext = millis() + 20UL;
    if (coinStep >= 3) {
      coinByteDeadline = millis() + SERIAL_TIMEOUT_MS;
      coinOperation = COIN_VERIFY_WAIT;
    }
  } else if (coinOperation == COIN_VERIFY_WAIT) {
    if (coinSerialDevice.available()) {
      uint8_t value = coinSerialDevice.read();
      if (value != coinEeprom[coinIndex]) {
        uint8_t detail[3] = {lowByte(coinIndex), value, coinEeprom[coinIndex]};
        sendOperation('E', coinTransaction, detail, sizeof(detail));
      }
      coinIndex++;
      coinStep = 0;
      coinNext = millis();
      coinOperation = coinIndex >= 256 ? COIN_IDLE : COIN_VERIFY_SEND;
      if (coinIndex >= 256) sendOperation('F', coinTransaction, NULL, 0);
    } else if (timeReached(coinByteDeadline)) {
      uint8_t detail[3] = {lowByte(coinIndex), 0xff, coinEeprom[coinIndex]};
      sendOperation('E', coinTransaction, detail, sizeof(detail));
      coinIndex++;
      coinStep = 0;
      coinNext = millis();
      coinOperation = coinIndex >= 256 ? COIN_IDLE : COIN_VERIFY_SEND;
      if (coinIndex >= 256) sendOperation('F', coinTransaction, NULL, 0);
    }
  }
}

static void handleProtocolFrame(const MillenniumFrame &frame) {
  if (frame.type == MCU_MSG_HELLO) {
    uint8_t versions[2] = {MILLENNIUM_PROTOCOL_VERSION, MILLENNIUM_PROTOCOL_VERSION};
    sendFrame(MCU_MSG_HELLO, versions, sizeof(versions));
    sendResetCause();
    return;
  }
  if (frame.type >= MCU_CMD_DISPLAY && frame.type <= MCU_CMD_COIN_VERIFY) {
    bool isDisplay = frame.type == MCU_CMD_DISPLAY;
    bool isReplay = isDisplay ?
        (lastDisplayCommandValid && frame.sequence == lastDisplayCommandSequence) :
        (lastCoinCommandValid && frame.sequence == lastCoinCommandSequence);
    if (isReplay) {
      sendAck(frame.sequence, 0);
      return;
    }
    if ((frame.type == MCU_CMD_DISPLAY && displayOperation != DISPLAY_IDLE) ||
        (frame.type >= MCU_CMD_COIN_CONTROL && frame.type <= MCU_CMD_COIN_VERIFY &&
         coinOperation != COIN_IDLE)) {
      sendAck(frame.sequence, 1);
      return;
    }
    if (isDisplay) {
      lastDisplayCommandSequence = frame.sequence;
      lastDisplayCommandValid = true;
    } else {
      lastCoinCommandSequence = frame.sequence;
      lastCoinCommandValid = true;
    }
    sendAck(frame.sequence, 0);
  }
  if (frame.type == MCU_CMD_DISPLAY) {
    startDisplay(frame);
  } else if (frame.type == MCU_CMD_COIN_CONTROL && frame.length == 1) {
    coinTransaction = frame.sequence;
    coinDeadline = millis() + 5000UL;
    if (frame.payload[0] == '@') {
      digitalWrite(coinResetPin, LOW);
      coinNext = millis() + 1000UL;
      coinOperation = COIN_RESET_LOW;
    } else {
      coinSerialDevice.write(frame.payload[0]);
      coinNext = millis() + 100UL;
      coinOperation = COIN_CONTROL_WAIT;
    }
  } else if (frame.type == MCU_CMD_COIN_PROGRAM) {
    startCoinProgram(frame.sequence);
  } else if (frame.type == MCU_CMD_COIN_VERIFY) {
    startCoinVerify(frame.sequence);
  } else if (frame.type == MCU_CMD_IDENTITY) {
    printIdentity();
  }
}

void loop() {
  noInterrupts();
  byte head = i2cHead;
  interrupts();
  while (i2cTail != head) {
    SerialUSB.write(i2cBuf[i2cTail]);
    i2cTail = (i2cTail + 1) % I2C_BUF_SIZE;
  }

  /* (#230 item 2) Report ring overflows. Emitted only here, after the drain has
   * finished, so it can never land in the middle of one of Alpha's messages:
   * Wire delivers a whole transmission per ISR call, so at this point the
   * stream sits on an event boundary. Beta talks to the Pi directly, so unlike
   * Alpha's report this always gets through. ASCII digits, because the host
   * consumes the payload with strlen() and a zero byte would desync it. */
  {
    unsigned int ov;
    noInterrupts();
    ov = i2cOverflow;
    interrupts();
    unsigned long nowMs = millis();
    if (ov != i2cOverflowReported ||
        lastOverflowReport == 0 ||
        nowMs - lastOverflowReport >= OVERFLOW_REPORT_INTERVAL_MS) {
      unsigned int n = (ov > 999) ? 999 : ov;
      uint8_t payload[4] = {'B', (uint8_t)('0' + (n / 100) % 10),
                            (uint8_t)('0' + (n / 10) % 10),
                            (uint8_t)('0' + n % 10)};
      sendFrame(MCU_EVT_DIAGNOSTIC, payload, sizeof(payload));
      i2cOverflowReported = ov;
      lastOverflowReport = nowMs;
    }
  }

  while (SerialUSB.available()) {
    byte data = SerialUSB.read();
    if (data == CMD_IDENTITY && !protocolDecoder.active()) {
      printIdentity();
      continue;
    }
    MillenniumFrame frame;
    if (protocolDecoder.feed(data, frame) == 1) handleProtocolFrame(frame);
  }
  serviceDisplay();
  serviceCoin();
  if (coinSerialDevice.available()) {
    uint8_t data = coinSerialDevice.read();
    sendFrame(MCU_EVT_COIN, &data, 1);
  }

  unsigned long now = millis();
  if (now - lastHeartbeat >= HEARTBEAT_INTERVAL_MS) {
    sendFrame(MCU_EVT_HEARTBEAT, NULL, 0);
    lastHeartbeat = now;
  }
  /* Reaching the end proves the main loop, serial parser, I2C drain, and active
   * operation all returned control; blocked code can no longer pet the dog. */
  wdt_reset();
}

void writeCommand(byte v) {
  digitalWrite(AD, HIGH);
  digitalWrite(WR, HIGH);
  digitalWrite(CS, LOW);
  digitalWrite(d0, bitRead(v, 0));
  digitalWrite(d1, bitRead(v, 1));
  digitalWrite(d2, bitRead(v, 2));
  digitalWrite(d3, bitRead(v, 3));
  digitalWrite(d4, bitRead(v, 4));
  digitalWrite(d5, bitRead(v, 5));
  digitalWrite(d6, bitRead(v, 6));
  digitalWrite(d7, bitRead(v, 7));
  digitalWrite(WR, LOW);
  delay(1);
  digitalWrite(WR, HIGH);
  digitalWrite(CS, HIGH);
  delay(1);
}

void writeCharacter(byte v) {
  digitalWrite(AD, LOW);
  digitalWrite(WR, HIGH);
  digitalWrite(CS, LOW);
  digitalWrite(d0, bitRead(v, 0));
  digitalWrite(d1, bitRead(v, 1));
  digitalWrite(d2, bitRead(v, 2));
  digitalWrite(d3, bitRead(v, 3));
  digitalWrite(d4, bitRead(v, 4));
  digitalWrite(d5, bitRead(v, 5));
  digitalWrite(d6, bitRead(v, 6));
  digitalWrite(d7, bitRead(v, 7));
  digitalWrite(WR, LOW);
  delay(1);
  digitalWrite(WR, HIGH);
  digitalWrite(CS, HIGH);
  delay(1);
}

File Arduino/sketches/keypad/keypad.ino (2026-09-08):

/*
 * Millennium Alpha (keypad) firmware.
 * Build with FQBN arduino:avr:millennium_alpha so the board identifies as
 * "Millennium Alpha" on USB (/dev/serial/by-id/usb-Arduino_LLC_Millennium_Alpha-if00).
 */
#include <Keypad.h>
#include <MagStripe.h>
#include <Wire.h>
#include <avr/wdt.h>
#include <MillenniumProtocol.h>

#ifndef MILLENNIUM_FIRMWARE_VERSION
#define MILLENNIUM_FIRMWARE_VERSION "0.0.0-development"
#endif
#ifndef MILLENNIUM_FIRMWARE_BUILD
#define MILLENNIUM_FIRMWARE_BUILD "unknown"
#endif
#define I2C_DISPLAY_ADDR 8

/* Preserve the reset flags before setup() and disable a watchdog inherited
 * from a watchdog reset; otherwise the two-second startup delay can loop. */
uint8_t previousResetCause __attribute__((section(".noinit")));
void captureResetCause(void) __attribute__((naked, section(".init3")));
void captureResetCause(void) {
  previousResetCause = MCUSR;
  MCUSR = 0;
  wdt_disable();
}
bool resetCauseReported = false;

const int hookUpPin = 5;
const int hookDownPin = 4;
const int hookCommonPin = 21;

bool hookUpState = true;
unsigned long lastHookChange = 0;
const unsigned long DEBOUNCE_MS = 50;

/* Bounded retry budget for transient I2C ISR/USB scheduling jitter. */
const uint8_t I2C_SEND_ATTEMPTS = 8;
const unsigned long I2C_RETRY_DELAY_MS = 25;

/* Messages Beta never acknowledged, even after the retries above, and the last
 * value we managed to report to the host. */
unsigned int i2cDropped = 0;
unsigned int i2cDroppedReported = 0;
unsigned int i2cErrors[5] = {0, 0, 0, 0, 0};
unsigned long lastDropReport = 0;
uint8_t protocolSequence = 0;

/* Re-announce the drop count this often, zero included.
 *
 * Reporting only on change loses the news entirely in the case that matters
 * most: drops happen when the link to Beta is sick, which is exactly when the
 * Pi is likely to be mid-reconnect and not reading the port. Beta forwards to
 * a USB endpoint that discards when no host is attached, so a one-shot report
 * simply evaporates -- observed doing exactly that.
 *
 * Re-announcing zero matters too: without it, a gauge left at 3 would stay at
 * 3 after Alpha reboots with a clean counter. It also gives the Pi its only
 * positive sign of life from Alpha -- Beta's heartbeat says nothing about
 * whether the keypad board is still running. 5 bytes every 30 s. */
const unsigned long DROP_REPORT_INTERVAL_MS = 30000;

/* (#232) What the hook read as during setup(), kept for the status query.
 * Printing it at boot would be useless: an external reset re-enumerates the
 * USB CDC port, so anything written before a host attaches is discarded. */
bool bootHookUp = false;
bool bootHookReported = false;

const byte ROWS = 4;
const byte COLS = 7;
char keys[ROWS][COLS] = {{'1', '2', '3', 'A', 'B', 'C', 'D'},
                         {'4', '5', '6', 'E', 'F', 'G', 'H'},
                         {'7', '8', '9', 'I', 'J', 'K', 'L'},
                         {'*', '0', '#', 'M', 'N', 'O', 'P'}};

byte rowPins[ROWS] = {9, 8, 7, 6};
byte colPins[COLS] = {10, 11, 12, 13, 18, 19, 20};
static const byte DATA_BUFFER_LEN = 108;

Keypad keypad = Keypad(makeKeymap(keys), rowPins, colPins, ROWS, COLS);

MagStripe card(22, 0, 1);

/*
 * (#230) Send one I2C message to Beta, retrying while it NACKs.
 *
 * Wire.endTransmission() returns 0 only when Beta acknowledged every byte; 2
 * and 3 are NACKs. Blocking sketch code does not itself explain either result:
 * AVR TWI acknowledges in hardware while interrupts are enabled. We retain
 * retries for transient faults and count every actual return code so electrical,
 * address-NACK, and data-NACK failures can be distinguished in production.
 *
 * Returns true if the message landed.
 */
bool i2cTrySend(const uint8_t *payload, uint8_t len) {
  for (uint8_t attempt = 0; attempt < I2C_SEND_ATTEMPTS; attempt++) {
    uint8_t status;
    Wire.beginTransmission(I2C_DISPLAY_ADDR);
    Wire.write(payload, len);
    status = Wire.endTransmission();
    if (status == 0) {
      return true;
    }
    if (status <= 4) i2cErrors[status]++;
    wdt_reset();
    delay(I2C_RETRY_DELAY_MS);
  }
  return false;
}

/* As above, but tallies a failure. Use this for real phone events; the drop
 * report itself uses i2cTrySend so a failed report cannot inflate the very
 * number it is trying to report. */
bool i2cSend(const uint8_t *payload, uint8_t len) {
  if (i2cTrySend(payload, len)) return true;
  i2cDropped++;
  return false;
}

bool i2cTrySendFrame(uint8_t type, const uint8_t *payload, uint8_t len) {
  uint8_t frame[32];
  size_t frameLen = millenniumEncode(type, protocolSequence++, payload, len,
                                     frame, sizeof(frame));
  return frameLen > 0 && i2cTrySend(frame, (uint8_t)frameLen);
}

bool i2cSendFrame(uint8_t type, const uint8_t *payload, uint8_t len) {
  if (i2cTrySendFrame(type, payload, len)) return true;
  i2cDropped++;
  return false;
}

/*
 * (#230 item 2) Tell the host how many messages we lost.
 *
 * This necessarily rides the same I2C link that dropped them, so it only gets
 * through once the link is healthy again. That is fine: the count is
 * cumulative and the host publishes it as a gauge, so a late report is still
 * correct. ASCII keeps these diagnostics readable on a serial console.
 */
void reportDropsIfChanged() {
  uint8_t msg[5];
  unsigned int n;
  unsigned long now = millis();
  bool changed = (i2cDropped != i2cDroppedReported);
  bool due = (lastDropReport == 0) ||
             (now - lastDropReport >= DROP_REPORT_INTERVAL_MS);

  if (!changed && !due) return;

  n = (i2cDropped > 999) ? 999 : i2cDropped;
  msg[0] = 'A';
  msg[1] = '0' + (n / 100) % 10;
  msg[2] = '0' + (n / 10) % 10;
  msg[3] = '0' + n % 10;

  if (i2cTrySendFrame(MCU_EVT_DIAGNOSTIC, msg, 4)) {
    i2cDroppedReported = i2cDropped;
    lastDropReport = now;
  }

  /* Preserve the Wire return code distribution: 1=data too long, 2=address
   * NACK, 3=data NACK, 4=other. Two decimal digits saturate rather than wrap. */
  for (uint8_t code = 1; code <= 4; code++) {
    unsigned int errors = i2cErrors[code] > 99 ? 99 : i2cErrors[code];
    msg[0] = 'I';
    msg[1] = '0' + code;
    msg[2] = '0' + (errors / 10);
    msg[3] = '0' + (errors % 10);
    i2cTrySendFrame(MCU_EVT_DIAGNOSTIC, msg, 4);
  }
}

void reportResetCause() {
  uint8_t msg[5];
  unsigned int n;
  if (resetCauseReported) return;
  n = previousResetCause;
  msg[0] = 'K';
  msg[1] = '0' + (n / 100) % 10;
  msg[2] = '0' + (n / 10) % 10;
  msg[3] = '0' + n % 10;
  if (i2cTrySendFrame(MCU_EVT_DIAGNOSTIC, msg, 4)) resetCauseReported = true;
}

/*
 * Sample the hook switch.  hookCommonPin is driven low only for the read, the
 * same way loop() does it, so the two pull-ups can be told apart.
 */
bool readHookUp() {
  bool up;
  digitalWrite(hookCommonPin, LOW);
  delayMicroseconds(50);   /* let the pull-ups settle before sampling */
  up = !digitalRead(hookUpPin) && digitalRead(hookDownPin);
  digitalWrite(hookCommonPin, HIGH);
  return up;
}
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

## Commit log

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2026-02-23 Audit Arduino firmware: fix bugs, add pinout docs
    Address Issue #35 (Arduino firmware audit):
    Firmware fixes (keypad.ino):
    - Fix parseTrack2 buffer overrun: sentinel search loops now have
    bounds checking and return early on malformed data
    - Add 50ms hook switch debounce to prevent spurious events
    - Change I2C address from 0 (general call) to 8 (specific address)
    - Remove dead code (#if 0 debug blocks, unused struct fields)
    - Add validity flag to MagstripeData to handle parse failures
    Firmware fixes (display.ino):
    - Add 2-second timeout to all blocking serial reads to prevent
    hangs if the Pi disconnects mid-command
    - Add timeout to coin validator EEPROM verify reads
    - Match I2C slave ad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
    [display.ino, keypad.ino]
2026-02-23 Audit PCB design: rewrite README, fix BOM, document v2→v4 changes
    Address Issue #36 (PCB audit):
    - Rewrite pcb/README.md with:
    - Complete BOM table for phonev4 with all components
    - v2 → v4 change summary (LM358→LM386, added XL6009, RJ9 jack,
    3.5mm audio jacks, removed motor connector, reduced passives)
    - Connector pinout descriptions cross-referencing Arduino/PINOUT.md
    - I2C pull-up documentation (R1/R2 = 10kΩ)
    - Power distribution overview
    - File inventory
    - Known issues (stale BOM, missing Gerbers, no assembly drawing,
    LM386 gain configuration)
    - Replace stale phonev4.csv (contained v2 BOM) with correct v4 BOM
    Partially addresses #36 — remaining items (sc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
    [phonev4.csv]
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2026-02-23 Remove v2 schematic, add Gerbers, document speaker coupling flaw
    - Remove phonev2 KiCad files (v2 is superseded, no longer needed)
    - Add pcb/gerbers/ with the actual Gerber and drill files sent to
    JLCPCB for the phonev4 board fabrication
    - Document known design flaw: handset earpiece and ringer speaker
    outputs are coupled on the PCB, causing crosstalk (Issue #42).
    ALSA config works around this in software via route plugin.
    - Update README file inventory and manufacturing section
    Refs #42
    [phonev2.kicad_pcb, phonev2.kicad_sch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]
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2026-02-23 Replace LM386 with TDA2822M dual-channel amplifier, add protection circuits
    Major schematic improvements addressing #42 (speaker coupling) and #44
    (quiet handset):
    - Replace single-channel LM386 with TDA2822M dual-channel amplifier.
    Channel A drives the ringer speaker, channel B drives the handset
    earpiece. Both paths are now amplified and electrically isolated.
    - Change I2C pull-ups R1, R2 from 10kΩ to 4.7kΩ (standard for 100kHz).
    - Add to BOM: reverse polarity protection (Si2301 P-MOSFET), ESD
    protection (PRTR5V0U2X on RJ9 and coin connectors), 1A resettable
    fuse, power indicator LED, and 7 test points.
    - Add TDA2822M symbol to custom library (phone.kicad_sym).
    - Rewrite pcb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
    [phonev4.csv, phonev4.kicad_sch]
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2026-02-23 fix: stop coin validator motor running every 30s when phone idle
    The serial watchdog only counted reads as activity. When idle, the Arduino
    sends nothing, so after 30 seconds the watchdog falsely marked the link dead
    and triggered reconnect. Reconnect sends 'f' to re-init the coin validator,
    which spins the motor.
    Changes:
    - Treat writes (display + coin validator) as serial activity
    - Increase SERIAL_WATCHDOG_SECONDS from 30 to 300 (5 min) to avoid
    false positives during normal idle periods
    [millennium_sdk.c]
2026-02-23 fix: daemon service config/epoll/state, disable serial watchdog
    Daemon service fixes:
    - Use /etc/millennium/daemon.conf, add StandardInput=null for baresip epoll
    - Create /var/lib/millennium on install, chown for user services
    - Add MILLENNIUM_STATE_FILE env var when config file fails to load
    - Fix service name (daemon.service) in Makefile and updater
    - Add SETUP troubleshooting for config, epoll, and state file errors
    Serial watchdog:
    - Disable until keepalive implemented (issue #59)
    - Nothing writes to serial when idle, so watchdog still false-positives
    [millennium_sdk.c]
2026-02-23 Harden Arduino firmware and add serial keepalive
    Arduino sketch improvements (PINOUT.md known issues):
    - Add 4-second watchdog timer to both keypad and display sketches
    - Replace direct SerialUSB.write in receiveEvent ISR with ring buffer
    - Add bounds check for display command buffer overflow
    - Define protocol constants (CMD_*, EVT_*) replacing magic numbers
    - Document coinEeprom[] structure (TRC-6500 coin validator config)
    - Remove unnecessary pinMode toggling in hook scan loop
    Serial keepalive (issue #59):
    - Display Arduino sends 'P' heartbeat every 10 seconds over USB serial
    - Daemon recognizes and silently consumes heartbeat events
    - Re-enable serial watchdog with 60-second timeout (was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
    [display.ino, keypad.ino, millennium_sdk.c]
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2026-02-23 pcb: Rename power nets 5v→5V_MAIN, 12v→12V_COIN (fixes #69)
    - Schematic: global_label and TP1 Value
    - PCB: net definitions, pads, pour zone net_name
    [phonev4.kicad_pcb, phonev4.kicad_sch]
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2026-02-23 pcb: Assign missing footprints for D3, F1, TP1–TP5 (fixes #72)
    - D3 (power LED): LED_SMD:LED_0805_2012Metric
    - F1 (1A PTC): Fuse:Fuse_1812_4532Metric_Pad1.30x3.40mm_HandSolder
    - TP1–TP5: TestPoint:TestPoint_Pad_D1.5mm
    Run 'Update PCB from Schematic' in KiCad to apply to board.
    [phonev4.kicad_sch]
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2026-02-23 pcb: Align BOM with schematic and THT footprints (fixes #70)
    - LED1 → D3, LED_D5.0mm (matches schematic ref and THT choice)
    - TP1-TP7 → TP1-TP5, TestPoint_Loop (no TX/RX on PCB)
    - F1: Fuse_Radial_D10.0mm (THT)
    - R3: R_Axial_DIN0204 (matches schematic)
    - U1 footprint: - → XL6009_module
    [phonev4.csv]
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2026-02-23 pcb: Correct D1/D2 package to SOT-143 (fixes #73)
    PRTR5V0U2X is only available in SOT-143 (4-pin), not SOT-23.
    Update BOM, README, and AUDIT.md.
    [phonev4.csv]
2026-02-23 pcb: Document Q1 Si2319/Si2301 pin compatibility (fixes #71)
    Both are P-ch MOSFETs, SOT-23, identical G-S-D pinout.
    Update README, BOM, AUDIT to note either part acceptable.
    [phonev4.csv]
2026-02-23 pcb: Align capacitor BOM/README with schematic (fixes #83)
    - Radial D8mm: P3.80mm → P2.00mm (match schematic)
    - 100nF (C_inA/B, C_dec, C-*): C_Small/0603 → C_Axial_L3.8mm THT
    - README BOM table updated; add capacitor audit note to AUDIT.md
    [phonev4.csv]
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2026-02-24 Fix issues #122, #127, #132
    #122: web_server_pause - check paused flag in process_request, return 503
    when server is paused (e.g. during audio)
    #127: Serial input buffer - cap at 256KB to prevent unbounded growth on
    malformed/garbage data; discard and reset when cap would be exceeded
    #132: Remove dead config.cpp - Makefile builds config.c; config.cpp was
    never compiled
    [millennium_sdk.c]
2026-02-24 Fix issues #128, #131
    #128: string_buffer_append - on realloc failure, skip append instead of
    overflowing; check needed <= capacity before memcpy
    #131: Document that audio_tones functions are no-ops when built without ALSA
    [millennium_sdk.c]
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2026-02-24 fix(#59): Serial watchdog keepalive to avoid false positives when idle
    When the phone is idle, neither Pi nor Arduino sends on the serial link.
    After SERIAL_WATCHDOG_SECONDS (60s) with no activity, the watchdog
    falsely marked the link dead and triggered reconnect (sending 'f' to
    coin validator, spinning motor).
    Add periodic keepalive (CMD_KEEPALIVE 0x06) sent every
    SERIAL_KEEPALIVE_INTERVAL (30s) when idle. The write updates
    last_serial_activity, preventing false watchdog triggers.
    - millennium_sdk.c: send keepalive in check_serial when elapsed
    >= 30s and < 60s
    - Arduino display.ino: handle CMD_KEEPALIVE as no-op
    - PINOUT.md: document 0x06 keepalive command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
    [display.ino, millennium_sdk.c]
2026-02-24 docs: Add deploy_display.sh, Alpha/Beta headers, BRANCH support
    - deploy_display.sh: sync and flash display firmware on remote Pi
    - Sketches: header comments ensure millennium_alpha/beta FQBN used
    - BRANCH= env var to deploy specific branch (e.g. fix/issue-59)
    - README: deploy instructions, Alpha/Beta requirement
    [display.ino, keypad.ino]
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2026-02-25 pcb: diode reannotation, ERC fixes, no-connect markers
    - Update docs for D1-D3 (P6KE6.8CA TVS), D4 (power LED)
    - Add PWR_FLAGs for 5V_MAIN, GND, 3.3V nets
    - Fix C6/C7 bypass wiring (parallel to GND, not series)
    - Add no_connect markers for 59 intentionally unused pins
    - Remove dangling wires at 288.29mm and 110.49/130.81
    - Add add_no_connect.py script for future ERC sync
    - Add F1 fuse footprint, fp-lib-table, DESIGN_OPTIONS
    [phonev4.csv, phonev4.kicad_pcb, phonev4.kicad_sch]
2026-02-26 pcb: phonev4 KiCad design with project footprint libraries
    - Add project-local footprint libs: ADA3708, audio, PCM_arduino-library, misc_footprints
    - Q1 THT: TO-220-3_Vertical_GSD for IRF9540N
    - R4, R5: 1k for Pi→Arduino reset (unconnected in schematic)
    - Updated fp-lib-table, BOM, README, audit script
    Made-with: Cursor
    [phonev4.csv, phonev4.kicad_pcb, phonev4.kicad_sch]
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2026-02-26 pcb: Gerber export cleanup - RS-274X, export script for JLCPCB zip
    - Disable Gerber X2 attributes (usegerberattributes no) to avoid JLCPCB
    preview parser issues
    - Add export_jlcpcb.sh: Gerbers + drills -> phonev5-gerbers.zip
    - BOM/CPL handled by KiCad JLCPCB plugin
    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
    [phonev5.csv, phonev5.kicad_pcb, phonev5.kicad_sch]
2026-02-26 pcb: clean up unused files, add JLCPCB workflow
    - Remove obsolete BOM/CPL CSVs and Python scripts (plugin handles these)
    - Remove redundant loose Gerber files (kept in zip only)
    - Remove outdated gerbers/ docs (BOM_VERIFICATION, CPL_ROOT_CAUSE, etc.)
    - Add JLCPCB_WORKFLOW.md: export script + plugin for BOM/CPL
    - Update .gitignore for PCB build artifacts (gerbers, jlcpcb, backups)
    - Update README Manufacturing section
    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
    [phonev5-B_Cu.gbr, phonev5-B_Mask.gbr, phonev5-B_Paste.gbr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]
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2026-03-14 Arduino: GPIO reset flashing, remove CMD_FLASH_MODE hack; add CLAUDE.md
    Replace the old deploy_display.sh (uhubctl power-cycling, 200-attempt
    race loop, CMD_FLASH_MODE silent mode) with a clean GPIO-reset approach
    now that the Pi has direct RST connections to both Arduinos:
    - GPIO17/GEN0 (pin 11) → Arduino Alpha RST
    - GPIO27/GEN2 (pin 13) → Arduino Beta RST (required bodge wire; trace
    missing from phonev5 PCB — documented in pcb/README.md errata)
    - deploy_display.sh: assert GPIO27 reset (open-drain), wait for device
    to cycle, flash with avrdude; remove uhubctl/1200-baud/race loop
    - deploy_keypad.sh: new script, same approach via GPIO17
    - Makefile: replace flash_display wi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
    [phonev5.csv, phonev5.kicad_pcb, phonev5.kicad_sch]
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2026-03-15 display: fix VFD blanking by replacing writeCommand(0) with vfdreset+display-on+scroll-off
    The Noritake CU20026SCPB-T23A VFD should never receive AD=HIGH. The old
    CMD_DISPLAY_TEXT handler called writeCommand(0) (AD=HIGH, data=0x00) which
    turned the display off or wrote to an invisible register, causing the blank/
    solid-character symptoms.
    Fix: replace writeCommand(0) with vfdreset() + delay(100) + writeCharacter(20)
    (display on) + writeCharacter(18) (scroll off) before each text write. Also
    translate 0x0A line separator to VFD char 13 (CR/line feed).
    Debug response bytes (Y/L/R/W/X/Z) retained for field diagnostics.
    [display.ino]
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2026-05-24 host: migrate VoIP from embedded Baresip to PJSIP (PJSUA C API)
    Baresip is an application, not a library; embedding its internal API forced a
    chain of hacks (run-as-the-~/.baresip-user, stdin redirect, disabling its
    stdio module, relaxed systemd hardening, internal-ABI coupling). Replace it
    with PJSIP's PJSUA C API, a purpose-built embeddable stack.
    - pjsip_interface.h/.c: PJSUA wrapper (create/init/transport/register, make/
    answer/hangup calls, RFC2833 DTMF via pjsua_call_dial_dtmf, reg+call event
    callbacks, audio auto-connect, foreign-thread registration). Header exposes
    plain C only, so millennium_sdk.c still compiles on the Mac; the .c builds
    on the Pi (pkg-config libpjproject),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
    [millennium_sdk.c, pjsip_interface.h]
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2026-05-24 host: select PJSIP sound devices by name (fix mono on the C-Media USB)
    On-Pi smoke testing revealed PJSUA auto-picks the raw stereo-only ALSA hw:
    device and fails to open it at mono telephony (Unable to set channel count 1).
    The asound.conf plug-wrapped devices handle mono fine.
    - pjsip_interface: select capture/playback by ALSA device NAME (resolved to a
    PJSUA index at startup via pjsua_enum_aud_devs), not fragile numeric indices;
    fall back to PJSUA default if a name is not found.
    - Config: sip.snd_capture / sip.snd_playback (defaults plughw:CARD=Device,DEV=0
    and out_right_solo = mic + earpiece/right channel).
    - Smoke test uses the same names (argv-overridable).
    Verified on the Pi: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
    [millennium_sdk.c, pjsip_interface.h]
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2026-06-11 build: unify on C89 + enforce -Werror; fix /api/logs
    Three related backend/build changes done together:
    1. C89 unification. Compile everything with one standard, -std=gnu89 (the
    C89 language plus the GNU extensions the ALSA/PJSIP system headers need,
    e.g. `inline`; strict -std=c89 can't parse those headers). Add
    -Wdeclaration-after-statement and hoist ~90 mixed-declaration sites to
    their block tops across the codebase. Removes the old per-file C89/C99
    Makefile split (the C99 files needed it for system headers, not their own
    code).
    2. -Werror: treat all warnings as errors and resolve every one. clang (Mac
    tests) and gcc (Pi daemon) both build clean:
    - websocket SHA1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
    [millennium_sdk.c]
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2026-06-14 Fix data race on the serial event queue / control-command dispatch
    Found by playtesting: under load the daemon SIGABRT'd (heap corruption). Three
    threads touch the core concurrently with no synchronization:
    - the main loop (serial read -> event_queue_push, pop, dispatch, display),
    - web-server worker threads (send_control_command dispatches keypad/coin/hook
    events directly, running plugin handlers + serial display writes),
    - PJSUA worker threads (SIP call-state callback pushes onto the event queue).
    The event queue is a malloc'd linked list spliced with no lock, and plugin
    dispatch + the serial fd were written from two threads at once -> heap/list
    corruption -> abort. AddressSanitizer ove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
    [millennium_sdk.c]
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2026-06-14 keypad firmware: fully initialize MagstripeData (fix uninitialized members)
    parseTrack2() only set the discretionary fields (expirationDate, serviceCode,
    otherData and their lengths) inside the `discretionaryLen >= 7` branch, so the
    early returns (no start sentinel / separator / end sentinel) and the short-data
    case returned a struct with uninitialized pointer members -- undefined behavior
    flagged by cppcheck (uninitvar / uninitStructMember). The caller only reads pan
    today, so it was latent, but it's a real defect.
    Initialize all fields up front (NULL / 0), so every return path yields a
    fully-defined struct. No behavior change for the live path.
    Found in the static-analysis pass; cppcheck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
    [keypad.ino]
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2026-07-18 verify: TLA+ model of coin accounting across the three ledgers
    The same balance lives in daemon_state->inserted_cents,
    classic_phone_data.inserted_cents and the persisted file. The only sync
    channel between the first two is plugins_adjust_inserted_cents (#109),
    called from exactly two sites -- the charge and the refund. Every other
    write to either ledger is unilateral.
    tests/CoinLedger.tla finds four independent divergence paths (#222):
    coin_return zeroes only the daemon ledger; the plugin's idle timeout and
    call timeout zero only the plugin ledger; and the boot ordering seeds the
    plugin from a daemon balance that has not been restored yet.
    No fix here -- collapsing to a single ledger chan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
    [CoinLedger.cfg, CoinLedgerDrift.cfg]
2026-07-18 verify: TLA+ model of the OTA updater; fix check ratchet and restart status
    tests/Updater.tla models the check FSM, the four-step apply pipeline, and
    what a restart does to a call in progress and to escrowed coins.
    Two fixes, both verified by the model:
    - check_state ratcheted 0 -> 1 -> 2 and never returned to 0, while
    updater_check_async required 0 to start. /api/check-update was inert
    after the first call for the life of the process. Worst when the FIRST
    check failed: latest_version is cleared and could never be refilled, so
    a phone that boots with the network down never learns about an update
    again. The guard is now `check_state != 1` -- start unless one is
    alr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
    [Updater.cfg, UpdaterOpen.cfg]
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2026-07-18 fix(#229): make the display frame's declared length match what is sent
    millennium_client_write_to_display narrowed strlen() to uint8_t for the 0x02
    frame header, then wrote the full strlen() in the body. For any message of 256
    bytes or more the two disagreed, and the framing has no resynchronisation --
    the receiver consumes exactly the number of bytes the header declares, so
    every byte past that was interpreted as a command opcode.
    The firmware's own bounds check (display.ino:194, `num_bytes > sizeof(buf)`
    with buf[100]) does not save this: it rejects the frame and returns, but the
    Pi has already committed to sending that many bytes, which then land as
    opcodes too.
    Not reachable today -- d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
    [millennium_sdk.c]
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2026-07-19 verify: model-check the mutex acquisition graph for deadlock (#231 follow-up)
    #231 documented the lock order. Documenting an order is not the same as
    proving nothing violates it, and a counterexample here is a hang on the phone
    rather than a wrong number.
    tests/LockOrder.tla models the real acquisition chains across the five
    lock-taking threads and checks for circular wait. tests/extract_lock_edges.py
    derives the edge set from the source -- tracking pthread_mutex_lock/unlock
    nesting and taking the transitive closure over the call graph -- rather than
    from the comment I wrote in #231.
    That extraction immediately found the comment was wrong in two places:
    - daemon_state_mutex -> plugins_m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
    [LockOrder.cfg, LockOrderMutant.cfg]
2026-07-19 fix(#222): collapse the coin ledgers into one; persist spends
    I said this would change the plugin SDK contract. It does not. number_guess --
    which CLAUDE.md calls the canonical example -- already uses sdk_balance() /
    sdk_spend_balance() with no local ledger. This makes the three older plugins
    match the pattern the reference plugin already follows.
    classic_phone, jukebox and fortune_teller no longer keep a private
    inserted_cents. Four other plugins hold no money at all. The four divergence
    paths from tests/CoinLedger.tla are now unrepresentable rather than patched:
    there is nothing to keep in sync.
    Two problems found during the conversion, both worse than the modelled ones:
    - jukebox and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
    [CoinLedger.cfg, CoinLedgerDrift.cfg]
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2026-07-19 fix(#224, #225): roll back a failed OTA; never restart during a call
    #224 -- rollback. updater_apply now captures the pre-update commit with
    `git rev-parse HEAD` before the pull, and resets the working tree back to it if
    the build or install fails. Previously `make clean` ran first and unconditionally
    while the tree was already at the new commit, so a build failure stranded new
    source with no binary and no record of where it came from.
    The INSTALLED BINARY is deliberately not restored -- undoing an install needs a
    backup that does not exist -- and the status string says so
    ("source rolled back; installed binary unchanged") rather than implying a full
    rollback. Partial fix, stated as partial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
    [Updater.cfg, UpdaterOpen.cfg]
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2026-08-01 fix(#247): keep retrying the serial reconnect after the first failure
    millennium_client_check_serial() opened with an early return on
    display_fd == -1, but open_serial_port() drops the stale fd before it
    attempts the open -- so a failed reconnect left the fd at -1 and every
    later call bailed at that guard. The retry and backoff logic lives
    further down the same function, so the first failed attempt was also
    the last one: any serial disconnect outlasting ~2s stranded the daemon
    until someone restarted the service.
    Treat a closed fd as a dead link instead, and gate the keepalive and
    activity watchdog on having a live fd so they fall through to the
    reconnect.
    Verified on the phone by unbindin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
    [millennium_sdk.c]
2026-08-01 fix(#239): replay the tracked coin gate on serial reconnect
    The reconnect path sent a bare 'f' to the coin validator. That was wrong
    twice over: it dropped the 'z' that every other 'f' and 'c' call site
    pairs with, so the re-init may never have committed; and it armed the
    validator regardless of hook state, so a reconnect with the handset on
    the hook left the mech accepting coins that handle_coin_event() then
    refused to credit, because it only credits in IDLE_UP. The coin is
    physically swallowed and the customer gets nothing.
    Instead of guessing what the TRC-6500 does with an unterminated 'f',
    track the last gate command the daemon sent and replay it with that call
    site's exact sequence --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
    [millennium_sdk.c]
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2026-08-01 test: give the serial recovery policy a testable seam (#247 follow-up)
    check_serial touches real fds, so both simulator.c and tests/unit_tests.c
    stub it out entirely -- its policy had no coverage at all, which is how
    #247 (the reconnect that gave up after one failed attempt) shipped.
    Move the decision into serial_recovery.c as pure logic:
    serial_action_t serial_recovery_next_action(const serial_link_state_t *);
    int serial_recovery_backoff_seconds(int attempts);
    check_serial now samples the link, asks for a verdict, and carries it
    out. Marking the link dead makes a retry due immediately, so it re-asks
    and reconnects in the same pass, as it always has. No behaviour chang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
    [millennium_sdk.c]
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2026-08-01 fix(#232, #230, #254): report hook at boot, retry I2C, flash the bootloader
    Three coupled fixes, all needed to get one working flash onto Alpha.
    #254 -- pi_flash.sh polled for the SKETCH's USB port after resetting the
    board, but a reset Micro runs the stock Caterina bootloader, which
    enumerates under its own product string (Arduino Micro), not the custom
    one. So it waited out the bootloader window and handed avrdude the
    running firmware, which answers with "programmer is not responding".
    Every flash had been failing this way. Poll the bootloader path instead,
    which is what CLAUDE.md already documented. Also default BOTH_RESET=0:
    both bootloaders share a product string and have no USB serial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
    [keypad.ino]
2026-08-02 feat(#230): surface dropped I2C messages to the host as a metric
    Item 2 of #230. Item 1 (send-side retry) landed in #255; this makes the
    loss that survives the retry visible instead of silent, which was the
    original complaint: "nothing anywhere reports the loss".
    Both directions now count what they lose. Alpha tallies messages Beta
    never acknowledged; Beta's receive ISR tallies bytes dropped because the
    ring was full, which previously truncated a card PAN with the host still
    parsing the short result as a valid 16-char event.
    New 'X' event on the existing serial protocol: source letter ('A'/'B')
    plus a 3-digit count. ASCII rather than a raw byte because
    process_event_buffer() consumes strle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
    [display.ino, keypad.ino, millennium_sdk.c]
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
